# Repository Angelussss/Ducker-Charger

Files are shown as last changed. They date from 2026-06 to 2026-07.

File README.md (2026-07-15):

<div align="center">

# ⚡ Ducker-Charger

**A fully custom, open-source smart power bank, designed from scratch.**

*4S3P Li-Ion pack · bidirectional USB-PD · bench-supply output · TFT telemetry UI*






<table>
  <tr>
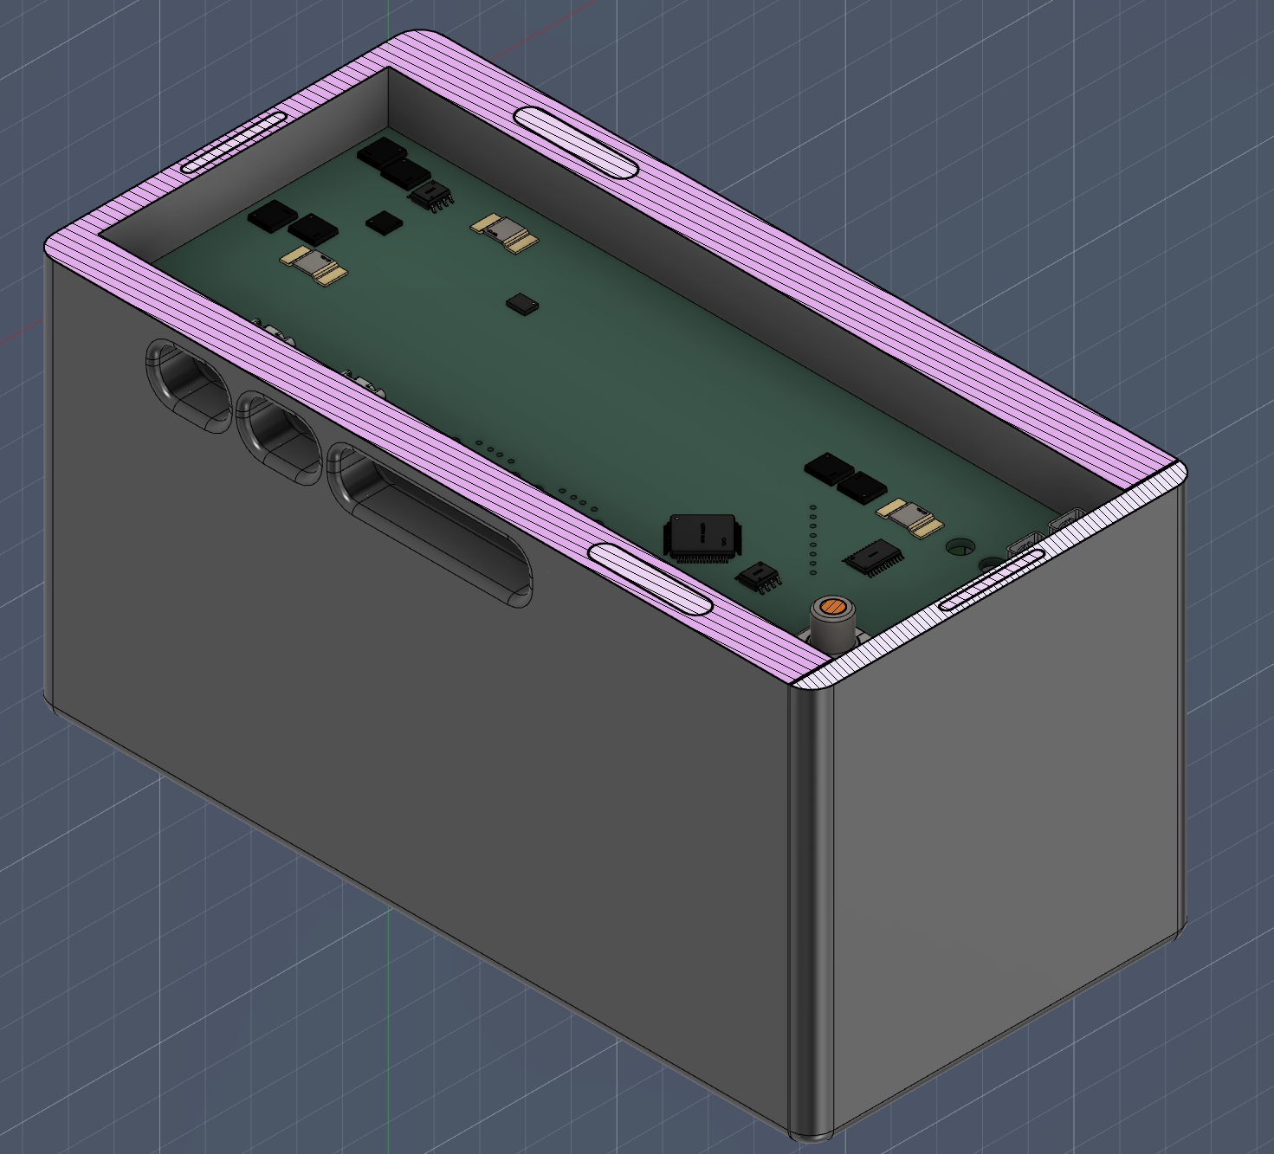
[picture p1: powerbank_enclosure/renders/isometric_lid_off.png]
Enclosure render
    <td align="center"></td>
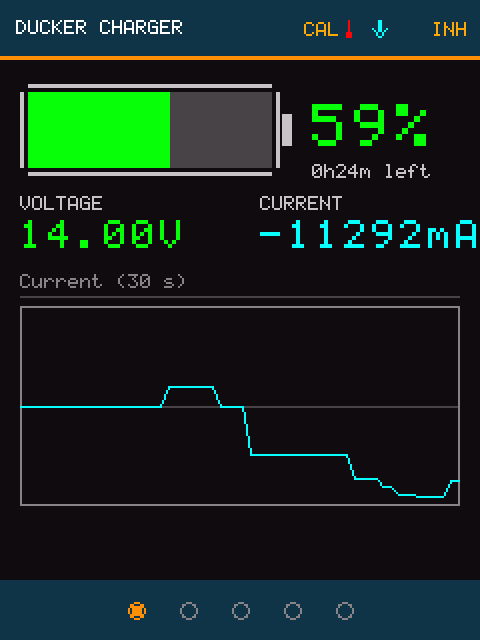
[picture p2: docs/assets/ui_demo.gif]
UI demo
    <td align="center"></td>
  </tr>
  <tr>
    <td align="center"><em>Enclosure (prototype 3, lid off)</em></td>
    <td align="center"><em>Live telemetry UI</em></td>
  </tr>
</table>

</div>

> [!WARNING]
> **Work in progress: the design is not yet validated.** This project involves
> Li-Ion batteries, which can overheat, catch fire, or explode if mishandled.
> Take any information here at your own risk and read the safety note below.

## 🌟 Highlights

* **115 Wh**: 12× 18650 cells (Sony Murata VTC5, 4S3P), 14.4 V nominal / 16.8 V max
* **2× USB-C PD**: primary port is bidirectional (charges the pack *and* powers loads)
* **2× USB-A**: fixed 5 V, individually switchable, current-monitored
* **Lab output**: banana-jack rail that behaves like a bench power supply
* **Hardware-autonomous BMS**: BQ77915 protection works even if all firmware fails
* **STM32F401 supervisor**: power-state FSM, charge management, TFT + rotary-encoder UI
* **On-device gauge calibration**: guided 9-step wizard on the display; a multimeter is the only tool needed (no bqStudio / EV2400)
* **Develop without hardware**: full-PCB emulator, desktop UI simulator, host-side unit tests

## ⚠️ Safety & Disclaimer

* **I assume no liability** for any damage to property, people, or components resulting from the construction or use of this project.
* Always double-check polarity before connecting the batteries.
* Do not attempt to assemble this circuit if you are not experienced in handling lithium batteries.

## 🛠️ Requirements

**Hardware**
* Assembled mainboard + Sensing-Board (`PCB/`)
* 12× 18650 Li-Ion cells, 4S3P (e.g. Sony/Murata VTC5)
* ST-Link V2 (or compatible SWD probe) to flash the STM32F401RBT6
* A USB-PD charger for the primary port, plus USB-C/USB-A cables to exercise the outputs

**Software**
* `arm-none-eabi-gcc`: the firmware builds via the CubeMX-generated `Makefile` in `firmware/cubeMX/`, no IDE required
* `st-flash` (`stlink-tools`) or STM32CubeProgrammer, to flash over SWD
* `gcc` + `SDL2`: only needed for `firmware/emulator/` and `firmware/interface-tester/` (no hardware required to run these)
* Optional: STM32CubeIDE / STM32CubeMX, only to regenerate peripheral init code from `cubeMX.ioc`

## 🧩 Architecture

Distributed design: cell safety, power conversion, PD negotiation and gauging
each live in a dedicated IC; the STM32 supervises, aggregates telemetry and
drives the UI. Block diagram in [`PCB/README.md`](PCB/README.md).

<details>
<summary><strong>Full IC breakdown (10 subsystems)</strong></summary>
<br>

| Subsystem | Part | Role |
|---|---|---|
| Safety / Protection | TI **BQ77915** + N-ch MOSFETs | Autonomous, software-independent cell OV/UV/SC/OC cutoff (4S, always-on) |
| Charger | TI **BQ25713** | Buck-boost NVDC battery charger (driven by the TPS25750 on a private I²C bus) |
| Main USB-C PD | TI **TPS25750** | Primary PD port controller; patch bundle streamed by the MCU at every boot |
| Aux USB-C PD | Infineon **CYPD3175** (CCG3PA) | Secondary PD port negotiation (replaced the EOL STUSB4710) |
| Aux programmable rail | ST **STPD01** | I²C-programmable supply for the secondary USB-C / lab output |
| Fuel gauge | TI **BQ34Z100-R2** | Impedance Track™ State-of-Charge / Time-to-Empty |
| Telemetry | TI **INA3221** | 3-channel voltage/current monitoring |
| Step-down | TI **TPS54302 / TPS54202** | Auxiliary rails |
| ESD / I²C isolation | **USBLC6**, **ISO1540** | Port ESD protection, isolated I²C to the battery-referenced gauge |
| Host | **STM32F401RBT6** | I²C master, power-state FSM, thermal manager, HMI / supervisor |

</details>

## 📂 Repository

| Path | Contents |
| --- | --- |
| [`PCB/`](PCB/README.md) | KiCad projects: main board + cell sensing board |
| [`firmware/`](firmware/) | STM32 firmware, PD controller configs, emulator, UI simulator, tests |
| [`docs/`](docs/README.md) | Documentation, start here |
| [`powerbank_enclosure/`](powerbank_enclosure/) | 3D-printable enclosure (F3D, STEP, STL, renders) |

<details>
<summary><strong>Full tree</strong></summary>

```text
Ducker-Charger/
├── PCB/
│   ├── Ducker-Charger/         # Main charger board (schematics, layout, datasheets)
│   └── Sensing-Board/          # Cell sensing board
├── firmware/
│   ├── cubeMX/                 # STM32F401 firmware (FSM, charge mgmt, UI, drivers)
│   ├── TPS25750/               # Primary PD controller config (JSON project + .bin)
│   ├── CYPD3175/               # Secondary PD controller firmware (hex, patches, LED driver)
│   ├── emulator/               # Full-PCB emulator: real firmware vs IC models (SDL)
│   ├── interface-tester/       # Desktop UI simulator (SDL)
│   └── tests/                  # Host-side unit tests (FSM, charge, HPI, math)
├── powerbank_enclosure/        # 3D-printable enclosure (F3D, STEP, STL, renders)
└── docs/
    ├── hardware/               # Power architecture, pin map / BSP reference
    ├── firmware/               # Architecture, FSM, charge mgmt, boot, UI
    └── assets/                 # UI demo gif
```

</details>

## 📖 Documentation

Start from **[`docs/README.md`](docs/README.md)**: full system overview and a
walkthrough of how the firmware works, with links to:

* [Hardware architecture](docs/hardware/Hardware_Architecture.md) · [pin-level BSP reference](docs/hardware/BSP_reference.md)
* [Firmware architecture](docs/firmware/Firmware_Architecture.md) · [power-state FSM](docs/firmware/FSM.md) · [charge management](docs/firmware/Charge_Management.md)
* [Boot & IC provisioning](docs/firmware/Boot_and_Provisioning.md) · [gauge calibration wizard](docs/firmware/Gauge_Calibration.md) · [UI / display reference](docs/firmware/UI_and_Display.md)
* [KiCad projects & block diagram](PCB/README.md)

## 🎮 User Guide

Boots to **MAIN** (battery %, voltage/current, live current graph). Rotate the
encoder to cycle **MAIN → DETAILS → GRAPH → PORTS → STATS**; press to open
**SETTINGS** (per-port toggles, Lab output voltage/current, USB-C2 output
ceiling, lock-all, brightness/auto-sleep, gauge calibration wizard, shutdown).
A long press (or SETTINGS → Shutdown) puts the device into deep sleep; a
short press wakes it back up if a charger is attached. Fault conditions open a
dedicated FAULT screen automatically, naming the cause.

Full screen-by-screen reference: [`docs/firmware/UI_and_Display.md`](docs/firmware/UI_and_Display.md).

## 🎥 Presentation & Demo

* 📊 Slides: [Google Slides](https://docs.google.com/presentation/d/1OwDXiBUUQ08QPd7Jknc45msrt9zxNyJMcGTFnEZxmk4/edit?usp=sharing)
* 🎬 YouTube walkthrough: [youtu.be/msm0JCK7GhI](https://youtu.be/msm0JCK7GhI)

## 👥 Team & Contributions

The project is split by layer, one owner per layer end-to-end (design, implementation, docs, tests):

| Member | Layer owned |
|---|---|
| Angelo Perotti | Hardware (PCB/KiCad), CubeMX project bring-up, boot & IC provisioning |
| Francesco Brunelli | Charge management: sensors, actuators, fault detection |
| Michelangelo Calia | Power-state FSM & fault handling |
| Maya | Display/UI stack: driver, widgets, screens, navigation |

## 🤝 Contributing

Issues, suggestions, and pull requests are momentarily suspended, as this is a university course project.

## 📜 License

Released under the [Creative Commons Attribution-NonCommercial 4.0 Internationalç
License (CC BY-NC 4.0)](LICENSE). © 2026 Angelo Perotti.

You are free to use, modify, and build upon this work for **non-commercial**
purposes, as long as you **credit the author**. See [NOTICE](NOTICE) for
attribution details.

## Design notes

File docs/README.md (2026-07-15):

# Ducker-Charger: Project Documentation

Entry point of the Ducker-Charger documentation: what the project is, how the
hardware is organized, how the firmware works, and which tools exist to develop
and test it. Every section links to the detailed document that covers it.

## Documentation map

```text
docs/
├── README.md                        # ← you are here: overview + code walkthrough
├── hardware/
│   ├── Hardware_Architecture.md     # power architecture, rails, subsystem analysis
│   └── BSP_reference.md             # pin map, ADC channels, I2C buses, GPIO tables
├── firmware/
│   ├── Firmware_Architecture.md     # module layers, main loop, telemetry/encoder/display/UI
│   ├── FSM.md                       # power-state machine: events, states, transition matrix
│   ├── Charge_Management.md         # charge.c: sensors, register maps, port logic
│   ├── Boot_and_Provisioning.md     # every-boot IC init + one-time gauge provisioning
│   ├── Gauge_Calibration.md         # on-device fuel-gauge calibration wizard
│   └── UI_and_Display.md            # screens, widgets, per-screen behaviour
└── assets/
    └── ui_demo.gif                  # UI demo capture
```

Related documentation outside `docs/`:

| Location | Content |
| --- | --- |
| [`PCB/README.md`](../PCB/README.md) | KiCad projects, schematic sheets, system block diagram |
| [`PCB/Ducker-Charger/docs/`](../PCB/Ducker-Charger/docs/) | IC datasheets and technical reference manuals |
| [`firmware/CYPD3175/README.md`](../firmware/CYPD3175/README.md) | Secondary-port PD controller firmware (build, flash, LED driver) |
| [`firmware/emulator/README.md`](../firmware/emulator/README.md) | Full-PCB emulator (firmware vs datasheet-level IC models) |
| [`firmware/interface-tester/README.md`](../firmware/interface-tester/README.md) | Desktop UI simulator (SDL) |

---

## 1. What the Ducker-Charger is

A custom, open-source smart power bank built around a 4S3P pack of twelve 18650
cells (Sony Murata VTC5, 14.4 V nominal / 16.8 V max / ~115 Wh). It exposes:

- **USB-C1 (primary)**: bidirectional USB-PD: charges the pack *and* powers loads (OTG).
- **USB-C2 (secondary)**: source-only USB-PD output, with a user-settable output ceiling.
- **2× USB-A**: fixed 5 V outputs, individually switchable.
- **Lab output**: banana-jack pins driven like a bench supply (shares the STPD01 rail with USB-C2, interlocked).

HMI: ILI9341 TFT (SPI) + rotary encoder with push-button.

Design philosophy: **distributed architecture**. Cell safety, power conversion,
PD negotiation and gauging each live in a dedicated IC; the STM32 supervises,
aggregates telemetry and drives the UI. Battery protection works even if every
line of firmware fails.

## 2. Hardware in one page

Full analysis: [`hardware/Hardware_Architecture.md`](hardware/Hardware_Architecture.md).
Pin-level reference: [`hardware/BSP_reference.md`](hardware/BSP_reference.md).

**NVDC topology**: the system load hangs on `VSYS`, regulated by the buck-boost
charger from either VBUS or the battery, the device is "instant-on" from USB-C
even with a dead pack.

| Subsystem | IC | Role |
| --- | --- | --- |
| Cell protection | TI **BQ77915** | Autonomous hardware OV/UV/OC/SC cutoff + passive balancing (4S, always-on). No firmware involved. |
| Charger | TI **BQ25713** | 4-switch buck-boost NVDC charger. On the TPS25750's **private** I2C bus, the MCU cannot reach it; it only sees the analog IADPT/IBAT/PSYS pins and CHRG_OK / EN_OTG GPIOs. |
| Primary PD (USB-C1) | TI **TPS25750** | PD controller; ROM-based, receives its 32 KB patch bundle from the STM32 at every boot. |
| Secondary PD (USB-C2) | Infineon **CYPD3175** (CCG3PA) | Autonomous PD negotiation, monitored by the MCU over HPI. Replaced the EOL STUSB4710. Own firmware, flashed independently. |
| Aux programmable rail | ST **STPD01** | Generates the voltage negotiated on USB-C2 / set for the lab output. |
| Fuel gauge | TI **BQ34Z100-R2** | Impedance Track SoC / time-to-empty. Battery-referenced, behind an **ISO1540** I2C isolator. |
| Telemetry | TI **INA3221** | Shunt monitor for USB-A1/A2 (CH3 grounded). |
| Aux rails | TI **TPS54302 / TPS54202** | Step-downs for logic and 5 V rails. |
| Host | **STM32F401RBT6** | I2C master, ADC telemetry, FSM, HMI, supervisor. |

**Buses:**

| Bus | Pins | Devices (7-bit addr) |
| --- | --- | --- |
| I2C3 "PD bus" | PA8 / PC9 | TPS25750 (0x20, length-prefixed host interface) |
| I2C1 "system bus" | PB6 / PB7 | CYPD3175 (0x08, HPI) · STPD01 (0x05) · INA3221 (0x40) · BQ34Z100 (0x55, isolated) |
| ADC1 | 8 channels | 5× NTC + IADPT / IBAT / PSYS from the charger |
| SPI1 | PA5 / PB5 | ILI9341 display (write-only) |
| TIM3 | PC6 / PC7 | Quadrature encoder (button on PC0 / EXTI0) |

**Grounds:** system `GND` and battery `-BATT` join only through the protection
FETs and the sense resistor; when protection trips, `-BATT` floats, hence the
ISO1540 isolator in front of the gauge.

## 3. Firmware: how the code works

Full detail: [`firmware/Firmware_Architecture.md`](firmware/Firmware_Architecture.md).

### 3.1 Layered structure (`firmware/cubeMX/Core/`)

```text
UI          ui/ui_state.c · ui/screens.c · ui/widgets.c
App         app/telemetry.c · app/encoder.c · app/initialization.c · app/provisioning.c · app/calibration.c
System      system/fsm.c · system/charge.c · system/event.c · system/tps25750_io.c
Display     display/ili9341.c · display/gfx.c
HAL         CubeMX-generated (SPI1 · I2C1 · I2C3 · TIM3 · ADC1 · GPIO)
```

Strictly one-directional: lower layers never know about upper ones. The UI reads
charge-layer getters read-only; only the FSM drives actuators; only `charge.c`
touches sensors and pushes events.

### 3.2 Boot (`main.c` + `app/initialization.c` + `app/provisioning.c`)

Doc: [`firmware/Boot_and_Provisioning.md`](firmware/Boot_and_Provisioning.md).

1. HAL + clock (HSE/PLL, 84 MHz) and `MX_*_Init()` peripherals.
2. **`System_Initialization()`**: every-boot bring-up of ICs with volatile config:
   - **TPS25750**: streams the 32 KB patch bundle (`app/tps25750_bundle.c`,
     generated from `firmware/TPS25750/*.bin`) over I2C3, verifies `PTCH → APP`
     transition. Skipped on warm reboot. No bundle → no PD, no charging.
   - **INA3221** config (CH1-2, averaging) and **STPD01** safe defaults
     (5 V / 3 A, output **off**).
   - 50 ms bounded timeouts, one retry per step; failures degrade the boot
     (`Init_GetReport()` feeds the boot screen) but never block it.
3. **Gauge provisioning**: one-time, marker-guarded write of pack parameters
   into the BQ34Z100 data flash; runs only on a verified device, at rest.
4. `Encoder_Init` · `Telemetry_Init` · `ILI9341_Init` · `UI_Init` · charge-layer
   `init()` · `PB_FSM_Init()` → IDLE.

### 3.3 Main loop (cooperative, no RTOS)

Each `while(1)` iteration: refresh port-status pins (`readNCS()`), pop one event
from the ring buffer into `PB_FSM_FireEvent()`, track encoder activity and the
deep-sleep button hold, `PB_FSM_Update()` (onExit/onEnter/onRun), `Telemetry_Poll()`
(rate-limited to 500 ms; keeps running in SLEEP so energy/uptime/histories don't
stop), and `UI_Tick()` (250 ms refresh) unless the FSM has the backlight off.
Sensor polling lives in each state's `onRun`, so what gets polled follows the
power state automatically.

### 3.4 Power-state FSM (`system/fsm.c`)

Doc: [`firmware/FSM.md`](firmware/FSM.md). Hybrid **vtable + transition matrix**:
behaviour per state (`onEnter/onRun/onExit`), transitions in a `[state][event]`
lookup. States: `DEEP_SLEEP`, `SLEEP`, `IDLE`, `SAFETY_LOCK`, `LOW_V`,
`EMERGENCY`, `CHARGING`, `MANUAL` (lab mode), `ERROR`. Events come from the
charge layer (charger plug/unplug, SoC thresholds 15 %/10 %, under-voltage,
overtemperature, critical faults) and from the UI (buttons, inactivity, lock,
lab mode). Protection states cut outputs in `onEnter`; `DEEP_SLEEP` uses STM32
STOP mode with the encoder button as sole wake source.

### 3.5 Charge management (`system/charge.c`)

Doc: [`firmware/Charge_Management.md`](firmware/Charge_Management.md). The only
module that touches sensors/actuators:

- **ADC**: NTC → °C (Beta equation), IADPT → mA, PSYS → W.
- **I2C**: gauge registers/flags, INA3221 currents + critical alerts, STPD01 status.
- **Primary port**: on `PD_IRQ`, decode TPS25750 `INT_EVENT1` (plug, power status,
  new contract as sink/provider), parse Fixed-Voltage PDO/RDO, gate **OTG**
  (EN_OTG raised only in IDLE/SLEEP; the pin is an independent kill switch on C1 sourcing).
- **Secondary port**: on `C2_RDY`, read the CYPD3175 HPI event (contract complete,
  disconnect, OVP/OCP/OTP, hard reset), then program the STPD01 through
  `secondaryUSBC_ApplyOutput()`, which clamps the negotiated contract to the
  user-set ceiling, verifies no post-setup fault, and only then enables the port.
- Pushes all FSM events; exposes getters for telemetry/UI.

### 3.6 Telemetry, display, UI

Docs: [`firmware/Firmware_Architecture.md`](firmware/Firmware_Architecture.md),
[`firmware/UI_and_Display.md`](firmware/UI_and_Display.md).
`app/telemetry.c` reshapes charge-layer getters into UI structs (battery snapshot,
per-port V/I with 60-sample histories, lifetime/session stats), no I2C of its own.
Display stack: `ili9341.c` (SPI, RGB565, 240×320) + `gfx.c` (text/primitives).
UI: screen carousel MAIN ↔ DETAIL ↔ GRAPH ↔ PORTS ↔ STATS, SETTINGS overlay
(long-press/double-click) with OUTPUT / DISPLAY / CALIBRATION / TEST sub-pages, CONFIRM/WARNING
modals, FAULT takeover, SLEEP page. Two-phase draw (full `Draw` on entry, partial
`Update` at 4 fps) eliminates flicker.

### 3.7 Companion firmware (not on the STM32)

- **TPS25750** (`firmware/TPS25750/`): TI web-GUI config project + generated
  `.bin` → embedded as `tps25750_bundle.c`, streamed at every boot (volatile).
- **CYPD3175** (`firmware/CYPD3175/`): built with Infineon CCGx Power SDK /
  PSoC Creator; flashed once over SWD or CC bootloader. Repo keeps the built hex,
  a status-LED driver, SDK patches and the PD config (PDOs 5/9/12/15/20 V @ 3 A).
- **BQ25713**: no firmware, configured at runtime by the TPS25750.

## 4. Development tooling (host-side, no hardware needed)

| Tool | What it does |
| --- | --- |
| [`firmware/emulator/`](../firmware/emulator/README.md) | Runs the **unmodified firmware** natively against register-level models of every IC (HPI, TPS patch flow, gauge data flash, battery physics with OCV/IR/thermal). SDL window renders the panel; headless scripted mode for regression runs. Firmware bugs are supposed to surface here. |
| [`firmware/interface-tester/`](../firmware/interface-tester/README.md) | UI-only simulator: real UI sources on a fake framebuffer + fake telemetry from `sim_config.ini`. Fastest way to iterate on screens. |
| `firmware/tests/` | Host-side unit tests: `make` runs `test_event`, `test_fsm`, `test_charge`, `test_cypd3175`, `test_hpi_schematic`, `test_math` against HAL stubs and IC models. |

## 5. Build & flash

```sh
cd firmware/cubeMX && make          # arm-none-eabi → build/cubeMX.elf/.hex/.bin
cd firmware/tests   && make         # host unit tests (gcc)
cd firmware/emulator && ./build.sh && ./run.sh          # full-board emulator (SDL2)
cd firmware/interface-tester && ./build.sh && ./run.sh  # UI simulator (SDL2)
```

STM32 flashes over SWD (ST-Link). Per-IC programming paths are mapped in
[`firmware/Boot_and_Provisioning.md`](firmware/Boot_and_Provisioning.md).
**Caveat:** CubeMX regeneration rewrites the Makefile, re-check the application
entries in `C_SOURCES` afterwards.

## 6. Mechanical

`powerbank_enclosure/` holds the 3D-printable enclosure (prototype 3): Fusion 360
source (`.f3d`), STEP, STLs (body, upper lid, short-side lid) and renders.

## 7. Status & open points

- Work in progress; hardware not yet validated, see the root [README](../README.md) disclaimer.
- Open `CHECK:` items (TPS burst chunking/address, gauge data-flash offsets,
  design capacity vs final pack, CYPD3175 LED pin) tracked in
  [`firmware/Boot_and_Provisioning.md`](firmware/Boot_and_Provisioning.md#open-verification-points).
- Fuel-gauge calibration is done **on-device**: SETTINGS → Calibration, a
  nine-step multimeter-assisted wizard (electrical cal, pack config, IT
  enable, learning-cycle monitor), see
  [`firmware/Gauge_Calibration.md`](firmware/Gauge_Calibration.md). Until it
  is run on the real pack, SoC readings are indicative and the UI shows a
  NOT CALIBRATED warning at every wake. ChemID selection (optional accuracy
  refinement) still needs one bqStudio session.

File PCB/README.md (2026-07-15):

# PCB: KiCad Projects

Two KiCad projects make up the Ducker-Charger hardware:

| Project | Contents |
| --- | --- |
| `Ducker-Charger/` | Main charger board: schematics, PCB layout, production files |
| `Sensing-Board/` | Cell sensing board (tap connections from the 4S pack to the BMS) |

## Main board schematic structure

| Sheet | File | Contents |
| --- | --- | --- |
| Root | `Ducker-Charger.kicad_sch` | Top level, sheet interconnections |
| High power | `high_pow.kicad_sch` | TPS25750 (primary USB-C PD), BQ25713 buck-boost charger, VBUS power path |
| Low power | `low_pow.kicad_sch` | CYPD3175 (secondary USB-C PD), STPD01 programmable rail, USB-A load switches, INA3221 sensing, lab-output switching |
| Logic | `Logic.kicad_sch` | STM32F401RBT6, display/encoder interface, logic supply |
| BMS | `BMS.kicad_sch` | BQ77915 protection, BQ34Z100-R2 fuel gauge, ISO1540 I2C isolator, protection FETs |

> The secondary PD controller is the Infineon **CYPD3175**: it replaced the
> ST **STUSB4710** (EOL).

Component datasheets and technical reference manuals used during the design are
collected in [`Ducker-Charger/docs/`](Ducker-Charger/docs/).

## System block diagram

```mermaid
flowchart TB
    subgraph BMS["BMS (always-on hardware safety)"]
        PACK["4S3P Sony VTC5<br/>14.4V nom / 16.8V max"]
        BQ77915["BQ77915 protector<br/>+ N-ch FETs (low-side)"]
        GAUGE["BQ34Z100-R2 fuel gauge<br/>(battery-referenced)"]
        PACK --> BQ77915
        PACK -.->|sense| GAUGE
    end

    subgraph HP["High-power stage"]
        TPS["TPS25750<br/>primary USB-C PD"]
        BQ25713["BQ25713<br/>buck-boost NVDC charger"]
        USBC1(("USB-C1<br/>bidirectional PD"))
        USBC1 <--> TPS
        TPS <-->|private I2C_EX| BQ25713
    end

    subgraph LP["Low-power / aux stage"]
        CYPD["CYPD3175<br/>secondary USB-C PD"]
        STPD01["STPD01<br/>programmable rail"]
        USBC2(("USB-C2<br/>source-only"))
        USBA(("2x USB-A<br/>5V"))
        LAB(("Lab output"))
        INA["INA3221<br/>current monitor"]
        CYPD <--> USBC2
        STPD01 --> USBC2
        STPD01 --> LAB
        INA --- USBA
    end

    subgraph LOGIC["Logic"]
        MCU["STM32F401RBT6"]
        DISP["ILI9341 TFT (SPI1)"]
        ENC["Rotary encoder (TIM3)"]
        MCU --> DISP
        ENC --> MCU
    end

    BQ77915 -->|+BATT| BQ25713
    BQ25713 -->|VSYS| LP
    BQ25713 -->|VSYS| LOGIC

    MCU <-->|"I2C3 (PD bus)"| TPS
    MCU <-->|"I2C1 (system bus, HPI)"| CYPD
    MCU <-->|I2C1| STPD01
    MCU <-->|I2C1| INA
    MCU <-->|"I2C1 via ISO1540"| GAUGE
```

Bus-level detail (pins, addresses):
[`docs/hardware/BSP_reference.md`](../docs/hardware/BSP_reference.md).

## Production

`*/production/` holds the fabrication outputs (gerber zip + IPC netlist)
generated with the JLCPCB fabrication toolkit. Regenerate after any layout
change; do not hand-edit.

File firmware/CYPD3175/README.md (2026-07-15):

# Ducker-Charger: CYPD3175 (EZ-PD CCG3PA) firmware customisation

Custom bits to graft onto the **EZ-PD CCGx Power SDK** reference firmware
for the USB-C2 PD controller (CYPD3175-24LQXQ, the STUSB4710
replacement). Reviewed here first; moves into the git repo only after
approval.

## Contents

```
src/ducker_led.c|h      status-LED driver (GPIO + SDK software timer)
src/INTEGRATION.md      where to hook it inside the reference project
config/c2_pd_config.md  config-table values (PDOs, protections) for the
                        EZ-PD Configuration Utility: no code involved
```

## Status

- **BUILT AND LINKED** (2026-07-04) against CCGx Power SDK 3.5 with
  PSoC Creator 4.4 in the win11 VM, zero warnings under `-Werror`.
  Flash: 89.6% (noboot) vs 88.7% baseline, the LED costs ~600 B.
  Built hex in `build/`; the patched reference files (app.c, main.c,
  both .cyprj with the ducker_led source entries) are mirrored in
  `patched-reference/` and live in the VM under `C:\ducker\fw`.
- Two of the three original CHECKs are resolved against SDK 3.5
  (timer ID = USER_TIMERS_START_ID+4, GPIO signatures verified).
- **One CHECK left**: the LED pin is a placeholder
  (`GPIO_PORT_1_PIN_4`) until the CCG3PA section of the schematic
  exists.
- The big open item is the power stage: `pa_direct_fb` expects the
  CCG3PA to drive the regulator via direct feedback. Copying the CCG3PA
  reference topology in the new PCB keeps firmware work at
  "config + LED"; keeping the STPD01 I2C chain means real psource-layer
  work.

## Toolchain

| Piece | Purpose |
|---|---|
| EZ-PD CCGx Power SDK | stack + reference projects (`CYPD3175-24LQXQ_pa_direct_fb`, `CYPD3171-24LQXQ_pb`) |
| PSoC Creator 4.x (Windows) | build |
| EZ-PD Configuration Utility | config table edit + bootloader flashing |
| MiniProg3/4 (SWD) | first flash on a blank chip |

Getting started: Infineon AN218179 "Getting Started with EZ-PD CCG3PA".

## LED behaviour (as implemented)

| State | Pattern |
|---|---|
| No cable | off |
| Attached / negotiating | slow blink (2 Hz) |
| Contract established | solid on |
| OVP/OCP fault | fast blink (8 Hz) |

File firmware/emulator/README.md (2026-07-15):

# emulator: full-PCB emulator for the Ducker-Charger firmware

Runs the **unmodified firmware** (`main.c`, FSM, charge management,
boot-camp init, gauge provisioning, telemetry, encoder, ILI9341 driver,
UI) natively on the PC against register-level models of the board's ICs.

Where `interface-tester/` fakes the telemetry and replaces the display
API, this emulator models **the PCB**: the ICs behave as their
datasheets/TRMs say, not as the firmware expects. Firmware bugs are
supposed to surface here; that is the point.

```
firmware thread (real, unmodified code)          emulator
────────────────────────────────────────  ──────────────────────────
main.c / fsm.c / charge.c / event.c        fake HAL (src/hal_impl.c)
initialization.c / provisioning.c            ├── I2C1 ─ BQ34Z100 (gauge, data flash, flags)
telemetry.c / encoder.c                      │         ├ CYPD3175 (HPI, event queue, INT PC3)
ili9341.c / gfx.c / ui/*                     │         ├ STPD01   (VOUT/ILIM/INT_STAT, EN PC11)
                                             │         └ INA3221  (shunts A1/A2, MSB-first)
                                             ├── I2C3 ─ TPS25750 (len-prefixed regs, PTCH→APP
                                             │          patch flow, burst addr 0x22, IRQ PB14)
                                             ├── ADC1 ─ NTC dividers + current/power senses
                                             ├── SPI1 ─ ILI9341/ST7789 panel (CASET/RASET/
                                             │          RAMWR decode → SDL window)
                                             └── GPIO ─ pin table, EXTI0, CHRG_OK, EN pins
                                           board.c: 4S3P battery physics (OCV curve, SoC
                                           integration, IR drop, thermal), power flow
```

## Quick start

```sh
# needs gcc + SDL2  (Arch: sudo pacman -S sdl2)
./build.sh
./run.sh                     # SDL window, 240x320 like the panel
./run.sh --headless 8000 --at 2500:c --at 5000:v    # scripted, no window
```

Headless mode dumps `screen.ppm` (as the eye would see it: backlight,
display-on and inversion applied) and `gram.ppm` (raw GRAM) plus a
status report on exit.

## Keys / scripted events

| Key | Action |
|-----|---|
| arrows / wheel | encoder rotation |
| SPACE | encoder button (hold = long press) |
| `c` | plug / unplug the C1 charger (TPS25750 + CHRG_OK) |
| `d` | attach / detach a sink device on C1 (powerbank sources, OTG) |
| `v` | attach / detach a PD sink on C2 (CYPD3175) |
| `1` / `2` | attach / detach a load on USB-A1 / A2 |
| `l` | attach / detach a resistive load on the lab output (`lab_load_ohm`) |
| `o` | INA3221 critical alert on A1 |
| `t` `h` `u` `f` | gauge faults: overtemp / BATHI / BATLOW / CF |
| `x` `z` `r` | CYPD3175 OVP / OCP / hard reset |
| `g` | STPD01 short-circuit fault |
| `k` | toggle CHRG_OK line |
| `w` | wake from STOP mode (deep sleep) |
| `q` | shutdown: push the long-press event straight into DEEP_SLEEP (only takes effect from IDLE/SLEEP, same as a real button hold) |
| `i` | print full status (board + firmware getters + pins) |
| `s` | dump screen.ppm / gram.ppm |
| ESC | quit |

`emu_config.ini` sets the initial battery state, PD contracts, loads and
IC behavior. `time_scale` accelerates only the battery physics.

## Recording gifs

`--rec <ms>` dumps a numbered frame to `frames/` every `<ms>` in both
the SDL and the headless loop. `./record.sh [out.gif]` wraps it:
records an interactive SDL session until ESC, trims the display-off
boot frames, inverts the colors back to the real-panel palette and
assembles the gif with ffmpeg (`REC_MS=50` for 20 fps).

## Gauge calibration model

The BQ34Z100 model exercises the on-device calibration wizard end to
end: the DF calibration block (subclass 104) is live, reported V/I/T
are distorted by the stored divider/gain/offset, seeded with deliberate
errors at attach, the internal offset routines run with realistic
CCA/BCA timing, and IT_ENABLE sets QEN + Update Status 0x04. A correct
wizard run visibly converges the readings.

Every log line carries the firmware FSM state as a column, and every
event fired into the FSM is traced as a `[FSM ]` line with the
transition it caused (`CHARGER_CONNECTED: IDLE -> CHARGING`), including
events that were ignored or refused by a guard, the log alone tells the
whole story of a scenario. The hook is `PB_FSM_TraceEvent()`, a weak
no-op in fsm.c that the emulator overrides; the target build pays
nothing for it.

## Fidelity notes / limits
- STPD01 `DIGITAL_ENABLE` (0x06) is stored but does not gate the output
  in the model (power-on follows the EN pin only), verify on hardware
  before trusting either.
- Timing is wall-clock: I2C/SPI transfers are instantaneous, HAL_Delay
  sleeps for real. `time_scale` compresses battery time only.
- BQ25713 is on the TPS25750's private I2C bus on the real board and is
  not modeled beyond CHRG_OK + the charge-current profile.

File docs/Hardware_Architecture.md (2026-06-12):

# Ducker-Charger: Hardware Architecture

This document details the hardware design, power architecture, and circuit analysis of the Ducker-Charger.

## 1. Power Architecture & Domains

The system utilizes a **Narrow Voltage DC (NVDC)** architecture. This decouples the system load from the battery, allowing the device to operate immediately upon USB-C insertion even if the battery is depleted or removed ("Instant-on").

### Voltage Rails

| Rail Name | Voltage | Source | Description |
| --- | --- | --- | --- |
| **VBUS** | 5V - 20V | USB-C / Boost | Input/Output power rail negotiated by PD Controller.|
| **VSYS** | Regulated | U1 (Charger) | Main system bus. Powered by Buck-Boost from VBUS or Battery.|
| **+BATT** | 10V - 16.8V | Battery Pack | Raw battery stack voltage (4S Li-Ion typical).|
| **+3V3** | 3.3V | **IC2** (TPS54302) | Logic supply for MCU and sensors, derived from `VSYS`.|
| **5V_USB** | 5.0V | **U4, U5** | Regulated output for USB-A ports.|
---

## 2. Subsystem Analysis

### 2.1. High-Power Stage & USB-C PD

*Schematic Sheet: `/High_pow/*`

* **USB-C PD Controller (U2 - TPS25750):** Manages the Power Delivery policy and negotiation on CC lines. It controls the input VBUS MOSFETs via `PP5V` gate drive and communicates with the MCU via `I2C_PD`.

* **Buck-Boost Charger (U1 - BQ25713):** The core power converter. It utilizes a 4-switch H-Bridge topology (MOSFETs Q3, Q4, Q13, **Q5**) to regulate voltage regardless of the VBUS/Battery differential. It manages the Power Path via the `BATDRV` signal, controlling Q15 to charge or discharge the battery.

### 2.2. Battery Management System (BMS)

*Schematic Sheet: `/BMS/*`

The BMS prioritizes safety through hardware redundancy, separating protection from monitoring.

* **Primary Protection (U8 - BQ77915):** A standalone hardware protector. It monitors individual cell voltages (`VC0`-`VC4`) and drives the series protection MOSFETs (Q1, Q2) to cut off the battery in case of Over-Voltage, Under-Voltage, or Short-Circuit. It also handles passive cell balancing.

* **Fuel Gauge (IC3 - BQ34Z100-R2):** Uses a low-side sense resistor (`SRN`/`SRP`) to track State of Charge (SoC).

* **Critical Design Note:** An **ISO1540 (U9)** I2C isolator is used. The Fuel Gauge references the Battery Negative (`-BATT`), while the MCU references System Ground (`GND`). The isolator prevents ground loops and protects the logic when protection FETs are open.

### 2.3. Logic & Control

*Schematic Sheet: `/Logic/*`

* **MCU (U7 - STM32F401RBT6):** The central controller. It monitors system telemetry, drives the display, and configures the PD controller and Charger via I2C.

* **Power Supply:** The MCU regulator (**IC2 - TPS54302**) is powered by `VSYS`. Since `VSYS` is backed by `VBUS`, the logic remains active during charging.

### 2.4. Auxiliary Outputs & Sensing

*Schematic Sheet: `/Low_pow/*`

* **Lab Mode Switching:** The system can route power to banana jacks (`V_LABS`) or USB ports via back-to-back MOSFETs (Q6-Q9), controlled by `USB_C_ZENABLER` and `LAB_ZENABLER` signals.

* **Current Monitoring:** An **INA3221** (3-channel monitor) provides real-time current and voltage telemetry for the auxiliary outputs.

---

## 3. Critical Implementation Details

### Ground Separation

The design features two distinct ground domains:

1. **GND:** System Ground (Logic, Power Stage, USB-C).
2. **-BATT:** Battery Pack Negative.

*Connection:* These are connected via the **Protection MOSFETs** and the **Sense Resistor**. When the protection trips, `-BATT` floats.

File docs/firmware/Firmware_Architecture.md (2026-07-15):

# Ducker-Charger: Firmware Architecture

This document describes the software architecture, module structure, and data
flow of the Ducker-Charger firmware, targeting the STM32F401RBT6 MCU and built
on top of the STM32 HAL generated by STM32CubeMX.

---

## 1. Project Layout

```
firmware/cubeMX/
├── Core/
│   ├── Inc/
│   │   ├── app/
│   │   │   ├── encoder.h        # Rotary encoder API
│   │   │   ├── initialization.h # Boot-time IC bring-up (TPS25750 patch…)
│   │   │   ├── provisioning.h   # BQ34Z100 data-flash provisioning
│   │   │   ├── calibration.h    # On-device gauge calibration backend
│   │   │   └── telemetry.h      # UI-facing data aggregation
│   │   ├── display/
│   │   │   ├── ili9341.h        # Low-level SPI display driver
│   │   │   ├── gfx.h            # Primitive drawing (text, lines…)
│   │   │   └── logo.h           # Boot logo bitmap
│   │   ├── system/
│   │   │   ├── charge.h         # Charge management: sensors + actuators
│   │   │   ├── defines.h        # Pins, thresholds, IC addresses
│   │   │   ├── event.h          # FSM event queue (ring buffer)
│   │   │   ├── fsm.h            # Power-state FSM
│   │   │   └── tps25750_io.h    # Length-prefixed TPS25750 register I/O
│   │   └── ui/
│   │       ├── ui_state.h       # UI state machine
│   │       ├── screens.h        # Per-screen draw/update functions
│   │       └── widgets.h        # Reusable graphical components
│   └── Src/
│       ├── app/        (encoder, initialization, provisioning,
│       │                calibration, telemetry, tps25750_bundle)
│       ├── display/    (ili9341, gfx)
│       ├── system/     (charge, event, fsm, tps25750_io)
│       ├── ui/         (ui_state, screens, widgets)
│       └── main.c      # CubeMX-generated entry point + main loop
├── Drivers/            # STM32 HAL + CMSIS (CubeMX-generated)
└── cubeMX.ioc          # CubeMX project file
```

The application code lives entirely in `Core/`. CubeMX-generated peripheral
initialisation (`MX_*_Init()`) stays in its generated files; application
integration lives in `main.c`'s USER CODE sections.

---

## 2. Module Architecture

The firmware is split into independent layers that communicate in a
single direction (lower layers do not know about upper layers):

```
┌──────────────────────────────────────────────┐
│              UI Layer                        │
│   ui_state.c  ·  screens.c  ·  widgets.c    │
├──────────────────────────────────────────────┤
│           Application Layer                  │
│  telemetry.c · encoder.c · initialization.c │
│  provisioning.c                              │
├──────────────────────────────────────────────┤
│         System Layer (FSM + charge)          │
│   fsm.c · charge.c · event.c · tps25750_io  │
├──────────────────────────────────────────────┤
│            Display Layer                     │
│       ili9341.c  ·  gfx.c                   │
├──────────────────────────────────────────────┤
│         HAL / Hardware (CubeMX)              │
│  SPI1 · I2C1 · I2C3 · TIM3 · ADC1 · GPIO   │
└──────────────────────────────────────────────┘
```

### Layer responsibilities

| Layer | Module | Responsibility |
| --- | --- | --- |
| **UI** | `ui_state` | State machine: which screen is active, navigation transitions |
| **UI** | `screens` | Full draw and partial update of each screen |
| **UI** | `widgets` | Reusable graphical components (battery bar, graph, labels…) |
| **App** | `telemetry` | Reshapes charge-layer getters into UI-facing structs (`telemetry`, `port_stats[]`, `sys_stats`); no I2C of its own |
| **App** | `encoder` | Reads TIM3 counter delta and button debounce |
| **App** | `initialization` / `provisioning` | Boot-time IC bring-up (TPS25750 patch bundle, STPD01/INA3221 defaults) and one-time BQ34Z100 data-flash provisioning |
| **App** | `calibration` | On-device gauge calibration backend: ratio-method DF rewrites, internal offset routines, pack config, IT enable, learning monitor (see `Gauge_Calibration.md`) |
| **System** | `fsm` | Power-state FSM: consumes events, drives port actuators via `onEnter`/`onExit` (see `FSM.md`) |
| **System** | `charge` | All sensor reads (ADC + I2C) and all port actuation; pushes FSM events (see `Charge_Management.md`) |
| **System** | `event` | 8-slot ring buffer decoupling event producers from the FSM |
| **System** | `tps25750_io` | Length-prefixed register I/O helpers for the TPS25750 host interface |
| **Display** | `ili9341` | SPI commands/data to the panel; raw pixel operations; backlight ownership |
| **Display** | `gfx` | Text rendering, lines, rectangles built on top of `ili9341` |

---

## 3. Main Loop Integration

The firmware uses a **cooperative, polling-based** approach: there is no RTOS.
Everything is called from the `while(1)` loop in `main.c`:

```c
/* USER CODE BEGIN 2  (after MX_*_Init calls) */
Encoder_Init(&htim3);
Telemetry_Init(&hi2c1, &hi2c3);
ILI9341_Init(&hspi1);
UI_Init();                     // show boot screen
init();                        // charge layer bring-up (initialization.c)
PB_FSM_Init(&fsm);             // enters IDLE
/* USER CODE END 2 */

/* USER CODE BEGIN 3  (inside while(1)) */
readNCS();                     // refresh port-status pins
if (event_pop(&evt)) PB_FSM_FireEvent(&fsm, evt);
/* encoder-activity, deep-sleep-hold and inactivity timers */
PB_FSM_Update(&fsm);           // onExit / onEnter / onRun
Telemetry_Poll();              // rate-limited; runs even in SLEEP so
                               // uptime/energy/histories keep flowing
if (state != SLEEP && state != DEEP_SLEEP)
    UI_Tick();                 // input + redraw (skipped: backlight off)
/* USER CODE END 3 */
```

Sensor polling itself happens inside the FSM's `onRun` handlers (each
active state calls `readCS()`/`readSensors()`/`readINA()` as appropriate),
so what gets polled follows the power state automatically.

### Timing budget

| Task | Interval | Controlled by |
| --- | --- | --- |
| Telemetry reshape | 500 ms | `TELEMETRY_POLL_INTERVAL_MS` in `telemetry.h` |
| UI refresh | 250 ms (4 fps) | `UI_REFRESH_INTERVAL_MS` in `ui_state.h` |
| Encoder read | Every `UI_Tick()` call | No timer, read-on-every-tick |
| FSM inactivity → SLEEP | 2 min | `INACTIVITY_TIMEOUT_MS` in `defines.h` |
| Deep-sleep hold | 3 s | `BUTTON_DEEPSLEEP_HOLD_MS` in `defines.h` |
| Boot screen timeout | 1 500 ms | `BOOT_SCREEN_DURATION_MS` in `ui_state.c` |

---

## 4. Application Layer

### 4.1 Telemetry Module (`telemetry.h / telemetry.c`)

The telemetry module makes **no I2C calls of its own**: the fuel gauge,
INA3221 and PD contracts are already polled every FSM tick by the charge
layer. `do_poll()` reads that layer's getters and reshapes the data into
UI-facing structs, `telemetry` (battery snapshot), `port_stats[5]`
(per-port V/I + 60-sample history ring for the PORTS screen), `sys_stats`
(lifetime + session counters, including a discharge-energy integral with a
sub-mWh remainder accumulator), and `tte_min`/`ttf_min`.

**Global data structure:**

```c
extern SystemTelemetry_t telemetry;
```

| Field | Type | Source | Description |
| --- | --- | --- | --- |
| `soc_percent` | `uint8_t` | BQ34Z100 reg `0x02` | State of Charge 0–100 % |
| `voltage_mV` | `uint16_t` | BQ34Z100 reg `0x08` | Pack voltage in mV |
| `current_mA` | `int16_t` | BQ34Z100 reg `0x0A` | Signed: positive = charging |
| `temp_celsius` | `int16_t` | BQ34Z100 reg `0x0C` | Converted from 0.1 K units |
| `is_full` | `uint8_t` | BQ34Z100 flags `FC` bit | 1 when battery fully charged |
| `is_charging` | `uint8_t` | BQ34Z100 flags `CHG` bit | 1 when current > 0 |
| `over_temp` | `uint8_t` | BQ34Z100 flags `OT` bit | 1 on over-temperature fault |
| `vbus_present` | `uint8_t` | TPS25750 PD contract | 1 when the primary USB-C port is plugged and sinking |
| `charge_phase` | `uint8_t` | BQ34Z100 `CHG` flag / current sign | 0=idle, 1=charging. The BQ25713 register that would distinguish pre-charge/fast/taper (`CHGSTATUS1`) sits on a private I2C bus this MCU can't reach, see `Charge_Management.md`. |
| `power_mW` | `int32_t` | Computed | `voltage_mV × current_mA / 1000` |
| `current_history[]` | `int16_t[60]` | Ring buffer | Last 60 current samples (30 s) |
| `sensor_ok` | `uint8_t` | Internal | 1 if last poll succeeded on all chips |

**API:**

```c
void    Telemetry_Init(I2C_HandleTypeDef *hi2c1_ptr,
                       I2C_HandleTypeDef *hi2c3_ptr);
uint8_t Telemetry_Poll(void);   // respects TELEMETRY_POLL_INTERVAL_MS
void    Telemetry_ForcePoll(void);
```

**I2C bus assignment** (all access happens in the charge layer):

| Bus | HAL handle | Devices | Address (7-bit) |
| --- | --- | --- | --- |
| I2C1 | `hi2c1` | CYPD3175 · STPD01 · INA3221 · BQ34Z100 (via ISO1540) | `0x08` · `0x05` · `0x40` · `0x55` |
| I2C3 | `hi2c3` | TPS25750 (length-prefixed host interface, `tps25750_io.c`) | `0x20` |

> **Note:** the BQ25713 charger is *not* on any MCU bus, it sits on the
> TPS25750's private I2C_EX bus. Its only MCU-visible outputs are the
> analog telemetry pins (IADPT/IBAT/PSYS on ADC1) and CHRG_OK/EN_OTG GPIOs.

**Temperature conversion** (from raw register to °C):
```
T[°C] = (raw / 10) − 273
```
Example: `raw = 2981` → 298.1 K → **25 °C**

**Current ring buffer:** `current_history[]` is a circular buffer of 60
samples. `history_idx` points to the next free slot; `history_full` is set
to 1 after the first complete lap. At one sample per 500 ms this gives
30 seconds of current history, used by the graph screen.

---

### 4.2 Encoder Module (`encoder.h / encoder.c`)

Reads the rotary encoder (EC11 type) connected to TIM3 in hardware encoder
mode, plus the push-button on PC0.

**Hardware connections:**

| Signal | MCU pin | Notes |
| --- | --- | --- |
| Encoder A | TIM3 CH1 (PC6) | Handled automatically by TIM3 encoder mode |
| Encoder B | TIM3 CH2 (PC7) | Handled automatically by TIM3 encoder mode |
| Button | PC0 | Active-low, external pull-up on board; EXTI0 both edges + 50 ms software debounce. Also the sole DEEP_SLEEP wake source. |

**How TIM3 encoder mode works:** the timer hardware counts quadrature edges
on channels A and B without using interrupts (`TIM_ENCODERMODE_TI12`).
Reading `TIM3->CNT` gives the accumulated position; the raw delta is
divided by 2 (2 counts per detent in TI12) to obtain user-visible clicks.

**API:**

```c
void    Encoder_Init(TIM_HandleTypeDef *htim_ptr);
int8_t  Encoder_GetDelta(void);   // positive = right, negative = left
uint8_t Encoder_IsPressed(void);  // edge-triggered, consumed on read
uint8_t Encoder_IsHeld(void);     // level-based, not consumed
```

`Encoder_GetDelta()` is stateful: it returns the movement since the last
call and resets the reference counter. Calling it twice without any rotation
returns 0 on the second call.

Button debounce threshold: `ENCODER_DEBOUNCE_MS = 50 ms`.

---

## 5. Display Layer

### 5.1 ILI9341 Driver (`ili9341.h / ili9341.c`)

Low-level SPI driver. Handles the hardware reset sequence, the
command/data distinction via the DC pin, and raw pixel operations.

**SPI connections:**

| Signal | MCU pin |
| --- | --- |
| SPI1 SCK | PA5 |
| SPI1 MOSI | PB5 |
| CS | PB0 (`DISP_CS_Pin`) |
| DC | PB1 (`DISP_DC_Pin`), LOW = command, HIGH = data |
| RST | PB2 (`DISP_RST_Pin`) |
| Backlight | PB8 (`BCKL_CTRL_Pin`), via `ILI9341_Backlight()`, polarity per JP402 |

Display resolution: **240 × 320 pixels, portrait mode.**
Pixel format: **RGB565** (5 bits red, 6 bits green, 5 bits blue, 2 bytes per pixel).

**Key primitives:** `ILI9341_Init()`, `ILI9341_FillScreen()`,
`ILI9341_FillRect()`, `ILI9341_DrawPixel()`.

**Colour constants** (defined in `ili9341.h`):

| Constant | RGB565 | Usage |
| --- | --- | --- |
| `COLOR_BG` | `0x0841` | Near-black background |
| `COLOR_ACCENT` | `0x04FF` | Teal, active elements, selection |
| `COLOR_WARN` | `0xFD00` | Orange, warnings |
| `COLOR_DANGER` | `0xF800` | Red, errors, low battery |

### 5.2 GFX Layer (`gfx.h / gfx.c`)

Geometric and text primitives built on top of `ili9341`:
`GFX_DrawString()`, `GFX_DrawChar()`, `GFX_DrawHLine()`, `GFX_DrawCircle()`.
Three font sizes are available: `GFX_FontSmall`, `GFX_FontMedium`, `GFX_FontLarge`.

---

## 6. UI Layer

### 6.1 State Machine (`ui_state.h / ui_state.c`)

Manages navigation between screens. The state is stored in:

```c
extern UIState_t ui_state;
```

**Screens and navigation:**

```
          [BOOT]
            |  auto after 1 500 ms
            v
[MAIN] <--> [DETAIL] <--> [GRAPH] <--> [PORTS] <--> [STATS]   (carousel, wraps)

  SETTINGS overlay: long press (1 s) or double click from anywhere;
  its rows open the OUTPUT (Lab / USB-C2), DISPLAY, CALIBRATION
  (gauge wizard, behind a confirm modal) and TEST sub-pages.
  Modals: CONFIRM (Lock all / Shutdown), WARNING, FAULT (FSM takeover),
  SLEEP (dark screen page).
```

Encoder rotation moves through the main carousel. Short press is
screen-specific (GRAPH: cycle Y scale; SETTINGS: act on the selected row).
The full per-screen behaviour is documented in `UI_and_Display.md`.

**API:**

```c
void       UI_Init(void);
void       UI_Tick(void);                    // call in while(1)
void       UI_NavigateTo(UIScreen_t screen);
```

**`UIScreen_t` enum:** see `ui/ui_state.h`, BOOT, MAIN, DETAIL, GRAPH,
PORTS, STATS, SETTINGS, OUTPUT, DISPLAYPG, CALPG, TESTPG, CONFIRM, WARNING,
SLEEP, FAULT.

### 6.2 Screens (`screens.h / screens.c`)

Each screen exposes two functions:

- `Screen_XXX_Draw()`, draws everything (background, labels, current
  values). Called once when entering the screen.
- `Screen_XXX_Update()`, redraws **only** the dynamic parts (numbers,
  graph). Called periodically by `UI_Tick()`.

This two-phase approach eliminates flickering: the background and static
labels are never redrawn unnecessarily.

**Screen layout (240 × 320 portrait):**

```
Y=0   ┌──────────────────────────┐
      │  HEADER  (30 px)         │  title + status icons (USB-C, charging…)
Y=30  ├──────────────────────────┤
      │  CONTENT (260 px)        │  screen-specific content
Y=290 ├──────────────────────────┤
      │  FOOTER  (30 px)         │  navigation dots (● ○ ○ ○)
Y=320 └──────────────────────────┘
```

**MAIN screen layout:**

```
┌──────────────────────────┐
│  DUCKER CHARGER  [●USB-C]│  header
├──────────────────────────┤
│  [███████░░░░░] 85%      │  battery bar (Widget_BatteryBar)
│  14.75 V      +2450 mA   │  voltage + current labels
│  ~~~~~~~~~~~~~~~~~~~~~~~~│  current graph (Widget_LineGraph, 30 s)
├──────────────────────────┤
│  ●  ○  ○  ○              │  navigation dots footer
└──────────────────────────┘
```

**SETTINGS screen:** scrollable overlay of 9 rows. The currently selected
row is highlighted with `COLOR_ACCENT`.

| Row | Action | Backing signal / path |
| --- | --- | --- |
| 0 | USB-A Port 1 toggle | `USB_A1_CTRL_Pin` (PC1), row reads the live pin |
| 1 | USB-A Port 2 toggle | `USB_A2_CTRL_Pin` (PC2), row reads the live pin |
| 2 | Lab output → OUTPUT page | `C2_LAB_EN_Pin` (PA11) via FSM MANUAL state |
| 3 | USB-C Port 2 → OUTPUT page | `C2_PORT_EN_Pin` (PA12), row reads the live pin (the port auto-enables on PD negotiation) |
| 4 | Lock all (confirm modal) | `EVT_LOCK`/`EVT_UNLOCK` → FSM SAFETY_LOCK |
| 5 | DISPLAY page | brightness, auto-sleep, screen off, shutdown |
| 6 | CALIBRATION page | nine-step gauge calibration wizard (`app/calibration.c`), behind a CONFIRM modal |
| 7 | TEST page | forced warning scenarios |
| 8 | Exit | back to the screen SETTINGS was opened from |

### 6.3 Widgets (`widgets.h / widgets.c`)

Self-contained graphical components used by `screens.c`.

| Widget | Function pair | Description |
| --- | --- | --- |
| **BatteryBar** | `Widget_BatteryBar_Draw/Update` | Filled bar + percentage text. Colour: green >50 %, yellow >20 %, red ≤20 % |
| **LineGraph** | `Widget_LineGraph_Draw` | Renders a `int16_t[]` ring buffer; scales Y automatically between `val_min` and `val_max` |
| **ValueLabel** | `Widget_ValueLabel_Draw/Update` | Small header label + large numerical value |
| **StatusIcon** | `Widget_StatusIcon_Draw` | Coloured dot + text for USB-C, charging, full, temperature states |
| **MenuRow** | `Widget_MenuRow_Draw` | Single row with optional selection highlight |

---

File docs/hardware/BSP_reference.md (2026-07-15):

# Hardware Interface & Memory Map: Ducker-Charger Mainboard

**Target MCU:** STM32F401RBT6
---

## 1. Human Interface (Encoder & Button)

The user interface relies on a mechanical rotary encoder with an integrated push button.
**Hardware Note:** Signals are filtered via RC networks on the PCB. Internal pull-ups should be configured for the button if not sufficient.

| Signal Name | STM32 Pin | GPIO Config | Function |
| :--- | :--- | :--- | :--- |
| **ENC_A** | **PC6** | `AF_TIM` (Encoder Mode) | Encoder Phase A |
| **ENC_B** | **PC7** | `AF_TIM` (Encoder Mode) | Encoder Phase B |
| **ENC_BUTT** | **PC0** | `Input` (Pull-up) | Enter Button (Active Low) |

---

## 2. Analog Sensing System (ADC)

All sensors are read via **ADC1** (12-bit resolution).
**Reference (VREF+):** VDDA (+3.3V, filtered).

### 2.1 Channel Mapping
| Signal Name | STM32 Pin | ADC Channel | Description |
| :--- | :--- | :--- | :--- |
| **NTC_1** | **PA0** | IN0 | Temp Zone 1 (General/FETs) |
| **NTC_2** | **PA1** | IN1 | Temp Zone 2 |
| **NTC_3** | **PA2** | IN2 | Temp Zone 3 |
| **NTC_4** | **PA3** | IN3 | Temp Zone 4 |
| **NTC_ONB** | **PA4** | IN4 | On-Board NTC |
| **HP.IADPT** | **PA6** | IN6 | USB-C Input Current |
| **HP.IBAT** | **PA7** | IN7 | Battery Current (Charge/Discharge) |
| **HP.PSYS** | **PC4** | IN14 | Total System Power |

### 2.2 Data Conversion Formulas

**Thermistors (NTC)**
Standard voltage divider with 10k Pull-up to 3.3V.

**Input Current (HP.IADPT)**
Hardware: Sense Resistor = 10 mOhm, BQ25713 Gain = 20x.
```c
// Result in Amperes
float current_in_A = (adc_voltage_mV / 200.0f);

```

**System Power (HP.PSYS)**
Analog voltage proportional to system power (Battery + VBUS).

```c
// Result in Watts (Approximate, depends on R72/R69 ratio)
float power_sys_W = (adc_voltage_V * 60.0f);

```

---

## 3. Digital Communication Architecture

The system uses two separate I2C buses to isolate High Power (PD) negotiation from Low Power (System) telemetry.

### 3.1 High Power Bus (I2C_PD) - "Monitor Mode"

**Peripheral:** I2C3, **Pins:** SCL = **PA8**, SDA = **PC9**

| Device | IC | Address (7-bit) | Firmware Role |
| --- | --- | --- | --- |
| **PD Controller** | **TPS25750** | **0x20** | **Primary Target.** Query for PD Contracts & Status. Length-prefixed host interface, access via `system/tps25750_io.c` only. |
| **Charger** | **BQ25713** | N/A | **Not on this bus.** Slaved to the TPS25750 on their private `I2C_EX`; unreachable from the MCU. Its MCU-visible signals are the analog IADPT/IBAT/PSYS pins (ADC1) and the CHRG_OK / EN_OTG GPIOs. |

### 3.2 Low Power Bus (I2C_LP) - "Control Mode"

**Peripheral:** I2C1, **Pins:** SCL = **PB6**, SDA = **PB7**

| Device | IC | Address (7-bit) | Function & Configuration |
| --- | --- | --- | --- |
| **Power Monitor** | **INA3221** | **0x40** | **USB-A Current.** *Init:* CH1 (USB-A1) + CH2 (USB-A2) enabled; CH3 is tied to GND on this board. *Shunts:* 10 mOhm. |
| **Fuel Gauge** | **BQ34Z100-R2** | **0x55** | **Battery SoC.** Behind the ISO1540 isolator (battery side). Full register map below. |
| **Sec. USB-C PD** | **CYPD3175** (EZ-PD CCG3PA) | **0x08** | **Secondary port PD controller.** HPI protocol, 16-bit register addresses. Negotiates autonomously; MCU reads events/contract. |
| **Sec. USB-C Reg.** | **STPD01PUR** | **0x05** | **Programmable buck for the C2/Lab rail.** `ADD` pin grounded per netlist → 0x05. Set VOUT/ILIM, monitor faults. |

### 3.2.1 BQ34Z100-R2 Register Map (Fuel Gauge, I2C_LP @ 0x55)

These are the standard/extended commands the firmware reads from the fuel gauge.
Addresses, byte order, and units verified against the **BQ34Z100-R2 Technical
Reference Manual (SLUUCO5A)**. Multi-byte values are **little-endian** (low byte at
the lower address). The bundled `docs/bq34z100-r2.pdf` is the *datasheet* and does
**not** contain this table; it is sourced from the TRM.

| Command | Addr (LSB/MSB) | Bytes | Unit | Firmware field (`FuelGaugeSensors`) |
| :--- | :--- | :---: | :--- | :--- |
| `StateOfCharge()` | 0x02 | 1 | % | `SoC` |
| `Voltage()` | 0x08/0x09  | 2 | mV | `voltage` |
| `AverageCurrent()` | 0x0A/0x0B  | 2 | mA | `avgCurrent` |
| `Temperature()` | 0x0C/0x0D  | 2 | 0.1 K | `externalTemperature` |
| `Flags()` | 0x0E/0x0F  | 2 | bitfield| `flags` (see below) |
| `Current()` | 0x10/0x11  | 2 | mA | `current` |
| `AverageTimeToEmpty()` | 0x18/0x19  | 2 | minutes | `avgTimeToEmpty` |
| `AverageTimeToFull()`  | 0x1A/0x1B  | 2 | minutes | `avgTimeToFull` |
| `VoltScale()` | 0x20 | 1 | N/A | `voltageScale` |
| `CurrScale()` | 0x21 | 1 | N/A | `currentScale` |
| `InternalTemperature()`| 0x2A/0x2B  | 2 | 0.1 K | `internalTemperature` |
| `CycleCount()` | 0x2C/0x2D  | 2 | counts  | `cycleCount` |
| `StateOfHealth()` | 0x2E/0x2F  | 2 | % | `stateOfHealth` |

**Scaling note (per TRM §2.2):** when `VoltScale()` / `CurrScale()` return a value
> 1, the raw `Voltage()` / `Current()`, `AverageCurrent()`, and capacity readings
must be multiplied by that scale to obtain real units.

**`Flags()` bit definitions (TRM Table 2-6):**

| Byte | Bit 7 | Bit 6 | Bit 5 | Bit 4 | Bit 3 | Bit 2 | Bit 1 | Bit 0 |
| :--- | :---: | :---: | :---: | :---: | :---: | :---: | :---: | :---: |
| High | OTC | OTD | BATHI | BATLOW | CHG_INH | XCHG | FC | CHG |
| Low  | REST | RSVD | RSVD | CF | RSVD | SOC1 | SOCF | DSG |

The firmware decodes all high-byte bits and the documented low-byte bits
(`DSG`, `SOCF`, `SOC1`, `CF`, `REST`).

---

## 4. GPIO Control & Interrupts

### 4.1 Digital Outputs (Active High)

Signals used to enable power rails and modes.

| Signal Name | STM32 Pin | Hardware Target | Description |
| --- | --- | --- | --- |
| **USB_A1_CTRL** | **PC1** | Q10 (Load Switch) | Enable USB-A Port 1 Output (5V) |
| **USB_A2_CTRL** | **PC2** | Q11 (Load Switch) | Enable USB-A Port 2 Output (5V) |
| **HP.EN_OTG** | **PB15** | BQ25713 EN_OTG | Enable OTG (Reverse Power) on C1. ANDed by the charger with the I2C bit the TPS25750 sets, the MCU holding this low is an independent kill switch on C1 sourcing. |
| **STPD01_EN** | **PC11** | STPD01 Enable Pin | Enable the C2/Lab buck converter |
| **C2_PORT_EN** | **PA12** | Port FET | Route the STPD01 rail to the USB-C2 connector |
| **C2_LAB_EN** | **PA11** | Lab FET | Route the STPD01 rail to the Lab output (FSM MANUAL state; interlocked with C2_PORT_EN) |
| **BCKL_CTRL** | **PB8** | JP402 → FET | Display backlight (polarity per jumper; drive via `ILI9341_Backlight()` only) |

### 4.2 Interrupts & Status Inputs

Critical signals, polled from `readCS()` each FSM tick (the encoder button
on PC0/EXTI0 is the only line configured as a true interrupt).

| Signal Name | STM32 Pin | Trigger | Action Required |
| --- | --- | --- | --- |
| **HP.PD_IRQ** | **PB14** | Falling Edge | Read TPS25750 Event Register (Plug/Unplug). |
| **C2_ST_INT** | **PC12** | Falling Edge | Read STPD01 fault register (overcurrent/temp). |
| **C2_RDY** | **PC3** | Falling Edge | Read CYPD3175 HPI event register (PD event/fault). |
| **HP.CHRG_OK** | **PB13** | High Level | Adapter is valid. Also the DEEP_SLEEP wake gate: a button wake is only honored while this pin is high. |

---

## 5. Firmware Operational Notes

1. **Boot & Safety Sequence:**
* Check `HP.CHRG_OK` (PB13) before enabling high-current paths.
* `STPD01_EN` (PC11) stays low at boot, `initialization.c` programs the STPD01 with safe defaults (5 V / 3 A, output disabled) and enabling remains the runtime logic's job.
* Initialize `INA3221` (I2C_LP) immediately to provide OCP (Over Current Protection) for USB-A ports.

2. **Fuel Gauge Polarity Warning:**
* The hardware design places the **SRP** pin on the Cell Side and **SRN** on the System Side.
* **Action:** Ensure the BQ34Z100 flash configuration matches this polarity. If configured incorrectly, discharge current will be reported as positive charge.

3. **I2C Bus Separation:**
* **I2C_PD (I2C3: PA8 SCL / PC9 SDA)** is strictly for the TPS25750. Do not attempt to address battery-side or LP devices on this bus.
* **I2C_LP (I2C1: PB6/PB7)** carries everything else: CYPD3175, STPD01, INA3221, and the BQ34Z100 behind the ISO1540 isolator.

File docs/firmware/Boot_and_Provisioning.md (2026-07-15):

# Boot Initialization & IC Provisioning

**Scope:** the `feat/boot-camp` work, how every programmable IC on the
Ducker-Charger gets its configuration, at boot and in production.

## The four programming paths

Not everything on this board is "flashed" the same way. The complete
map:

| IC | What | When | How |
|---|---|---|---|
| STM32F401RB | application firmware | development / production | SWD (ST-Link) |
| CYPD3175 (CCG3PA) | USB-PD firmware, persistent | production + updates | SWD (MiniProg / OpenOCD `psoc4`) or CC/I2C bootloader, see `firmware/CYPD3175/README.md` |
| TPS25750 | patch + configuration bundle, **volatile** | **every boot** | streamed over I2C3 by the STM32 (`initialization.c`) |
| BQ34Z100-R2 | data-flash configuration (pack parameters, gauging) | **once**, in production | I2C, marker-guarded (`provisioning.c`) |

The BQ25713 charger has no user firmware: it is configured at runtime
by the TPS25750 through their private I2C bus (`I2C_EX`), so it never
appears in this document.

## Every-boot initialization: `Core/Src/app/initialization.c`

`System_Initialization()` runs once from `main()` (USER CODE 2 section,
after the `MX_*_Init()` calls) and configures the ICs whose settings do
not survive a power cycle, in this order:

1. **TPS25750** *(critical)*, the device is ROM-based and boots into
   patch mode: the 32 KB patch/config bundle
   (`Core/Src/app/tps25750_bundle.c`, generated from
   `firmware/TPS25750/TPS25750D_DuckerCharger.bin`) is streamed over
   I2C3 using the Patch Bundle Burst Mode protocol (`PBMs` → raw burst
   writes → `PBMc`), then the transition to `APP` mode is verified.
   Register access goes through the shared `system/tps25750_io.c`
   helpers (the host interface is length-prefixed on the wire); only
   the raw burst writes bypass them, as the burst target is a separate
   plain I2C address with no register framing.
   A warm reboot (device already in `APP`) skips the stream entirely.
   Without this step there is no PD on USB-C1 and no charging.
2. **INA3221**: configuration register: channels 1–2 enabled (channel
   3 is grounded on this board), 16-sample averaging, 1.1 ms
   conversions, continuous mode. Written and read back.
3. **STPD01**: safe defaults: VOUT 5 V, ILIM 3 A, **output disabled**.
   Turning the output on remains the runtime logic's job.

Design rules baked into the module:

- **Bounded timeouts everywhere** (50 ms per transaction), never
  `HAL_MAX_DELAY`: a dead bus degrades the boot, it must never freeze
  the product.
- Each step is retried once, then recorded as failed.
- **The boot always continues.** `Init_GetReport()` exposes the
  per-step outcome so the UI boot screen (or a UART log) can show what
  failed; a failed TPS25750 means a degraded product (no PD/charge),
  not a dead display.

## One-time provisioning: `Core/Src/app/provisioning.c`

The fuel gauge keeps its configuration in its own data flash, so this
is **not** part of the hot boot path: DF writes wear the gauge's flash
and must happen with the pack at rest.

### Version check over I2C

`Provisioning_Check()` answers "does this gauge need programming?"
in two stages:

1. `Control() DEVICE_TYPE` (0x0001) must return **0x0100**: confirms
   a BQ34Z100 actually answers at 0x55. Any other answer means wrong
   or absent silicon: the module then **refuses to write anything**.
2. A two-byte marker in *Manufacturer Info Block A*: `'D'` + a
   pack-configuration revision. Blank marker → factory-fresh gauge;
   older revision → re-provision. Bump `PROV_MARKER_1` whenever the
   patch list changes and already-deployed units re-provision
   themselves at the next check.

`Provisioning_Required()` returns 1 only for the two legitimate cases
(blank / old revision), bus errors and wrong devices are *not*
invitations to write.

### What gets written

`Provisioning_RunGauge()` (guarded by `|AverageCurrent| < 50 mA`)
unseals with the TI default keys and applies a patch list
(`GaugeDfPatch_t`: subclass, offset, bytes) through the standard
data-flash block protocol (0x3E/0x3F class+block select, 0x40 window,
0x60 checksum). Blocks whose content already matches are skipped to
spare the flash. Current list: design capacity (7800 mAh, 3P × VTC5),
series cells (4), the revision marker.

### Electrical calibration (on-device)

Shunt/divider/offset calibration is done from the device itself,
SETTINGS → Calibration, multimeter-assisted, no bqStudio needed. The
resulting DF values belong in the patch list above as golden-image
entries. Full procedure: [Gauge_Calibration.md](Gauge_Calibration.md).

### The golden image (still to do)

Static parameters are not enough for accurate gauging: the BQ34Z100
uses Impedance Track and must **learn** Qmax and the Ra tables on a
sample pack once, ChemID selection, full
charge/rest/discharge/rest learning cycle, then export. The exported
golden image becomes additional `GaugeDfPatch_t` entries, and every
production unit receives it through this same module. Until then, SoC
and capacity readings are indicative only.

## CYPD3175 (USB-C2 PD controller): `firmware/CYPD3175/`

Built separately with the Infineon EZ-PD CCGx Power SDK 3.5 + PSoC
Creator 4.4 and flashed independently from the STM32. The folder
contains the compiled hex (reference `pa_direct_fb` + our status-LED
module), the LED driver sources, minimal patches against the SDK
reference (full SDK sources are not redistributed for licensing
reasons), and the PD configuration values (PDOs 5/9/12/15/20 V @ 3 A,
protections) for the EZ-PD Configuration Utility. Details and the
rebuild procedure: `firmware/CYPD3175/README.md`.

## Open verification points

All marked `CHECK:` in the sources (`grep -rn CHECK Core/Src/app`):

| # | What | Where to verify |
|---|---|---|
| 1 | PBMs data layout and burst chunking | TPS25750 TRM, "Patch Bundle Burst Mode" |
| 2 | Burst target address (default 0x22 assumed; PBMs response reports the real one) | TPS25750 TRM |
| 3 | BQ34Z100 subclass IDs / offsets (Design Capacity, Series Cells, Mfg Info A) | BQ34Z100-R2 TRM data-flash table |
| 4 | Design capacity value (7800 mAh) vs final cell choice | pack BOM |
| 5 | CYPD3175 status-LED pin (placeholder `GPIO_PORT_1_PIN_4`) | schematic, once the CCG3PA section exists |

**Resolved since:** all IC I2C addresses now live in the single shared
header `system/defines.h`, TPS25750 settled at 0x20
(`TPS25750_PD_CONTROLLER_ADDR`), STPD01 at 0x05 (`ADD` pin grounded per
the schematic netlist, see `Charge_Management.md`).

## Maintenance notes

- **Flash budget:** the TPS bundle costs 32 KB of MCU flash. The UI and
  charge logic are now integrated in the build, re-measure with
  `arm-none-eabi-size` after significant changes (128 KB total).
- **CubeMX regeneration rewrites the Makefile** (it has no USER CODE
  sections): after every regeneration, re-check that all the application
  entries (`Core/Src/app/*.c`, `system/*.c`, `display/*.c`, `ui/*.c`)
  are still in `C_SOURCES`.
- The `main.c` hooks live inside USER CODE sections and survive
  regeneration.

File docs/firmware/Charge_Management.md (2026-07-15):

# Charge Management

## Table of Contents

- [Introduction](#introduction)
- [Telemetry](#telemetry)
	- [ADC](#adc)
	- [GPIO](#gpio)
	- [I2C1](#i2c1)
	- [I2C3](#i2c3)
- [Charging Ports](#charging-ports)
	- [USB-As](#usb-as)
	- [Primary USB-C](#primary-usb-c)
	- [Secondary USB-C](#secondary-usb-c)
- [Additional Resources](#additional-resources)

## Introduction

This document covers the implementation of the charge management system of the Ducker Charger (files `charge.h` and `charge.c`). Such system is responsible for:
- Reading all relevant sensors via `ADC` and converting appropriately the read values into correct units
- Initializing, reading and updating the statuses of ports and both critical and non-critical signals via `GPIO`
- Detecting faults (e.g. short circuit, over-temperature, etc...) and throwing interrupts accordingly
- Reading status registers and flags of different key components (`BQ34Z100-R2`, `INA3221`, `TPS25750`, `CYPD3175`, `STPD01`) via two different `I2C` channels
- Monitoring the secondary USB-C PD controller (`CYPD3175`) via HPI, reading the negotiated contract, configuring accordingly the power delivery and enabling/disabling the secondary USB-C port and the power delivery component
- Gating the primary port's OTG (source) mode through `EN_OTG` (PB15), enabled only when a sink device negotiates while the FSM allows outputs, dropped on unplug and in every protection state
- Applying the user-configurable output ceiling on the secondary USB-C port (`setSecondaryUSBC_VoltageCeiling/CurrentCeiling`): the delivered rail is `min(ceiling, negotiated contract)`, the ceiling can only lower what PD negotiated, never raise it
- Providing ready-to-use get functions for easy data fetch regarding sensors, statuses and components read

All TPS25750 register access goes through `system/tps25750_io.c`: the host interface is length-prefixed on the wire (a read returns `[len][data...]`, a write is `[reg][len][data...]`), which `HAL_I2C_Mem_*` cannot produce, hence the dedicated `tps25750_read()`/`tps25750_write()` helpers on I2C3.

---

## Telemetry

### ADC

All sensors are read via **ADC1** (12-bit resolution) according to the following table:
#### Channel Mapping
| Signal Name | STM32 Pin | ADC Channel | Description |
| :--- | :--- | :--- | :--- |
| `NTC_1` | PA0 | IN0 | Temp Zone 1 (General/FETs) |
| `NTC_2` | PA1 | IN1 | Temp Zone 2 |
| `NTC_3` | PA2 | IN2 | Temp Zone 3 |
| `NTC_4` | PA3 | IN3 | Temp Zone 4 |
| `NTC_ONB` | PA4 | IN4 | On-Board NTC |
| `HP.IADPT`  | PA6 | IN6 | USB-C Input Current |
| `HP.IBAT` | PA7 | IN7 | Battery Current (Charge/Discharge) |
| `HP.PSYS` | PC4 | IN14 | Total System Power |

*Note:* HP.IBAT is not memorized since the charge/discharge battery current is also fetched via I2C from the Fuel Gauge (`BQ34Z100-R2`). We need to read it anyway to continue the ADC scan sequence.

#### Data Conversion
Data fetched via ADC are provided in voltage and therefore need to be converted accordingly to get their correct value expressed in their proper unit measure.
First of all we need to adjust the fetched, raw voltage measure, according to our hardware specs; the function `toVoltage` performs this transformation by dividing the raw value by `VMAX` and multiplying it by `VREF` as shown:

$$
\frac{V_{raw}}{V_{MAX}} \cdot V_{REF}
$$

where: `VMAX` is equal to 2^nbits - 1 = 4095 (the ADC channel has 12-bit resolution); and `VREF` is equal to `VDD` = 3300mV.

Then we need to convert the obtained voltage value (expressed in `mV`) accordingly to the sensor we are reading:
- **Temperature:** obtained via NTC thermistors, in order to get the value expressed in ºC we need to:
	- Convert from voltage to resistance by doing:

$$
R_{PULLUP} \cdot \frac{V_{out}}{(V_{REF} - V_{out})}
$$

	- Convert from resistance to K using the Beta equation:

$$
T = \left( \frac{1}{T_0} + \frac{1}{\beta} \cdot \ln\left(\frac{R}{R_0}\right) \right)^{-1}
$$

	- Convert from K to ºC:

$$
T_{ºC} = T - 273.15
$$

- **USB-C Input Current:** given the Sense Resistor of 10 mOhm and the `BQ25713` Gain = 20x, in order to get the current value expressed in `mA` we need to divide the voltage by 0.2, or, more specifically:

$$
I = \frac{V_{out}}{R \cdot Gain} \cdot 1000
$$

- **Total System Power:**

$$
P = \frac{V_{out}}{1000} \cdot 60
$$

	- Where 60 is a hardware-derived gain constant (R72/R69 ratio)

### GPIO

#### Digital Outputs (Active High)

Signals used to enable power rails and modes.

| Signal Name | STM32 Pin | Hardware Target | Description |
| --- | --- | --- | --- |
| `USB_A1_CTRL` | PC1 | Q10 (Load Switch) | Enable USB-A Port 1 Output (5V) |
| `USB_A2_CTRL` | PC2 | Q11 (Load Switch) | Enable USB-A Port 2 Output (5V) |
| `C2_PORT_EN`  | PA12 | Port FET | Route the STPD01 rail to the USB-C2 connector |
| `C2_LAB_EN` | PA11 | Lab FET | Route the STPD01 rail to the Lab output (interlocked with `C2_PORT_EN`) |
| `HP.EN_OTG` | PB15 | BQ25713 EN_OTG | Enable OTG (Reverse Power) on C1, see the Primary USB-C section |
| `STPD01_EN` | PC11 | STPD01 Enable Pin | Enable the shared C2/Lab buck converter |

#### Interrupts & Status Inputs

Critical signals. Configure as EXTI (External Interrupt) or Polling.

| Signal Name  | STM32 Pin | Trigger | Action Required |
| --- | --- | --- | --- |
| `HP.PD_IRQ`  | PB14 | Falling Edge | Read TPS25750 Event Register (Plug/Unplug). |
| `C2_ST_INT`  | PC12 | Falling Edge | Read STPD01 fault register (overcurrent/temp). |
| `C2_RDY` | PC3 | Falling Edge | Read CYPD3175 HPI event register (PD protocol event/fault).  |
| `HP.CHRG_OK` | PB13 | High Level | Adapter is valid. Safe to start charging logic. |

### I2C1

#### BQ34Z100-R2 Register Map (Fuel Gauge @ 0x55)

These are the standard/extended commands the firmware reads from the fuel gauge.
Addresses, byte order, and units verified against the **BQ34Z100-R2 Technical
Reference Manual (SLUUCO5A)**. Multi-byte values are **little-endian** (low byte at
the lower address). The bundled [`bq34z100-r2.pdf`](../../PCB/Ducker-Charger/docs/bq34z100-r2.pdf) is the *datasheet* and does
**not** contain this table; it is sourced from the [TRM](../../PCB/Ducker-Charger/docs/BQ34Z100-R2_Technical Reference_Manual.pdf). All mentioned registers are Read-Only (RO)

| Command | Addr (LSB/MSB) | Bytes | Unit | Firmware field (`FuelGaugeSensors`) |
| :--- | :--- | :---: | :--- | :--- |
| `StateOfCharge()` | 0x02 | 1 | % | `SoC` |
| `Voltage()` | 0x08/0x09 | 2 | mV | `voltage` |
| `AverageCurrent()` | 0x0A/0x0B | 2 | mA | `avgCurrent` |
| `Temperature()` | 0x0C/0x0D | 2 | 0.1 K | `externalTemperature` |
| `Flags()` | 0x0E/0x0F | 2 | bitfield | `flags` (see below) |
| `Current()` | 0x10/0x11 | 2 | mA | `current` |
| `AverageTimeToEmpty()`  | 0x18/0x19 | 2 | minutes  | `avgTimeToEmpty` |
| `AverageTimeToFull()` | 0x1A/0x1B | 2 | minutes  | `avgTimeToFull` |
| `VoltScale()` | 0x20 | 1 | N/A | `voltageScale` |
| `CurrScale()` | 0x21 | 1 | N/A | `currentScale` |
| `InternalTemperature()` | 0x2A/0x2B | 2 | 0.1 K | `internalTemperature` |
| `CycleCount()` | 0x2C/0x2D | 2 | counts | `cycleCount` |
| `StateOfHealth()` | 0x2E/0x2F | 2 | % | `stateOfHealth` |

> **Scaling note (per TRM §2.2):** when `VoltScale()` / `CurrScale()` return a value greater than 1, the raw `Voltage()` / `Current()`, `AverageCurrent()`, and capacity readings must be multiplied by that scale to obtain real units

**`Flags()` bit definitions (TRM Table 2-6):**

| Byte | Bit 7 | Bit 6 | Bit 5 | Bit 4 | Bit 3 | Bit 2 | Bit 1 | Bit 0 |
| :--- | :---: | :---: | :---: | :---: | :---: | :---: | :---: | :---: |
| High | OTC | OTD | BATHI | BATLOW | CHG_INH | XCHG | FC | CHG |
| Low  | REST | RSVD | RSVD | CF | RSVD | SOC1 | SOCF | DSG |

**Flags Legend: RSVD = Reserved**
- **OTC:** Overtemperature in Charge condition is detected. True when set
- **OTD:** Overtemperature in Discharge condition is detected. True when set
- **BATHI:** Battery High bit that indicates a high battery voltage condition. True when set
- **BATLOW:** Battery Low bit that indicates a low battery voltage condition. True when set
- **CHG_INH:** Charge Inhibit: unable to begin charging. Refer to the data flash (Charge Inhibit Temp Low, Charge Inhibit Temp High) parameters for threshold settings. True when set
- **XCHG:** Charging not allowed
- **FC:** Full charge is detected
- **CHG:** (Fast) charging allowed. True when set
- **DSG:** Discharging detected. True when set
- **SOCF:** State of Charge is below the final (critical) low threshold
- **SOC1:** State of Charge is at threshold 1
- **CF:** Condition Flag, indicates the gauge needs a re-learning cycle. Firmware pushes `EVT_ERROR` on rising edge
- **REST:** Rest condition detected (no charge or discharge current for a sustained period)

*Note:* The firmware decodes all high-byte bits and all four documented low-byte bits (`DSG`, `SOCF`, `SOC1`, `CF`, `REST`). `CF` is the only low-byte flag that pushes an FSM event; the rest are available for the display layer

#### INA3221 Register Map @ 0x40

| Register Name | Addr (LSB/MSB) | Access | Bytes | Description |
| :--- | :--- | :----- | :---: | :--- |
| `Channel-1 Shunt Voltage` | 0x01 | R | 2 | Averaged shunt voltage value |
| `Channel-2 Shunt Voltage` | 0x03 | R | 2 | Averaged shunt voltage value |
| `Channel-3 Shunt Voltage` | 0x05 | R | 2 | Averaged shunt voltage value |
| `Mask/Enable` | 0x0F | R/W | 2 | Alert configuration, alert status indication, summation control and status |

*Note:* All data bytes are transmitted MSB first

**Data conversion:** in order to get the value of current (expressed in mA) that is passing through each channel, we need to convert the average shunt voltage value according to the following formula:

$$
I = \frac{V_{shunt} \cdot 0.04}{0.01}
$$

Where:
- 40 µV (= 0.04 mV) is the unit in which the shunt voltage is stored in the registers
- 10 mΩ is the resistance value for all shunt resistors

- **`Shunt Voltage` registers bit definitions (Starting from Table 6):**

| Bit  | Name | Access | Description |
| :--: | :--- | :----- | :--- |
|  15  | `SIGN` | R | Sign bit.  <br>0 = positive number  <br>1 = negative number in two's complement format |
| 14-3 | `SD11-0` | R | Channel's shunt-voltage data bits |
| 2-0  | `Reserved` | R | Reserved |

*Note:* the firmware right-shifts the 16-bit read by 3 positions to discard the reserved bits and isolate the signed 12-bit value

- **`Mask/Enable` bit definitions (Table 20):** (only those used by the firmware are specified)

| Bit | Name  | Access | Description |
| :-: | :---- | :----- | :--- |
|  9  | `CF1` | R/W | Critical-alert flag indicator |
|  8  | `CF2` | R/W | Critical-alert flag indicator |
|  7  | `CF3` | R/W | Critical-alert flag indicator |

*Note:* These bits are asserted if the corresponding channel measurement has exceeded the critical alert limit, resulting in the Critical alert pin being asserted

#### CYPD3175-24LQXQ HPI Register Map @ 0x08

The CYPD3175 (Cypress EZ-PD CCG3PA) uses the **HPI (Host Processor Interface)** protocol over I2C. All register addresses are **16-bit** and must be transmitted using `I2C_MEMADD_SIZE_16BIT`. The register space is split between global device registers and per-port registers.

**Global registers:**

| Register Name | Addr | Access | Bytes | Description |
| :--- | :----- | :----- | :---: | :--- |
| `INTR_REG` | 0x0006 | R/WC | 1 | Interrupt source flags; write 1 to clear each bit |

- **`INTR_REG` bit description:**

| Bit | Name | Description |
| --- | --- | --- |
| 0 | `DEV_INTR` | Device-level interrupt pending |
| 1 | `PORT0_INTR` | Port 0 interrupt pending |

**Port 0 registers (port base 0x1000, offsets per `cy_hpi_master_port_reg_t`):**

| Register Name | Addr | Access | Bytes | Description |
| :--- | :----- | :----- | :---: | :--- |
| `PORT0_TYPE_C_STATUS` | 0x100C | RO | 4 | Type-C connection state |
| `PORT0_CURRENT_PDO` | 0x1010 | RO | 4 | Active PDO contract (USB PD Fixed PDO format, little-endian) |
| `PORT0_CURRENT_RDO` | 0x1014 | RO | 4 | Active RDO from sink (USB PD RDO format, little-endian) |

- **HPI event codes; read from `RESPONSE_REG` (0x007E) per `cy_hpi_master_response_t`:**

| Code | Firmware macro | Description |
| ---- | --- | --- |
| 0x82 | `CYPD3175_EVT_OCP` | VBUS overcurrent fault |
| 0x83 | `CYPD3175_EVT_OVP` | VBUS overvoltage fault |
| 0x85 | `CYPD3175_EVT_DISCONNECT` | Type-C disconnection |
| 0x86 | `CYPD3175_EVT_CONTRACT_COMPLETE` | PD contract negotiation complete |
| 0x8F | `CYPD3175_EVT_HARD_RESET` | Hard Reset received |
| 0xB6 | `CYPD3175_EVT_OTP` | Overtemperature fault |

*Note:* the firmware reads `INTR_REG` (0x0006) to confirm a port 0 interrupt (bit 1 set), then reads the device-level `RESPONSE_REG` (0x007E) for the single-byte event code. The port 0 interrupt bit is then cleared by writing `0x02` back to `INTR_REG`. PDO/RDO data follows the standard [Fixed-Voltage PDO/RDO bit mappings](#usb-power-delivery-standard) and is decoded identically to the primary port.

####  STPD01PUR Register Map @ 0x05

*Note:* the `ADD` pin is grounded on this PCB (confirmed via schematic netlist); per the STPD01 datasheet's I2C address table, `ADD` tied to GND selects `ADD1,ADD0 = 01`, giving a 7-bit address of `0b0000101` (0x05).

| Register Name | Addr (LSB/MSB) | Access | Bytes | Description |
| :--- | :--- | :----- | :---: | :--- |
| `VOUT` | 0x00 | R/W | 1 | Set the output voltage configuration |
| `ILIM` | 0x01 | R/W | 1 | Set the output current limitation configuration |
| `INT_STAT` | 0x02 | R | 1 | Interrupt management (see below) |
| `DIGITAL_ENABLE` | 0x06 | R/W | 1 | Digital enable |

**Interrupt register description (Table 14):**

| Bit | Function | Notes |
| --- | --- | --- |
| 0 | `Overvoltage protection` | |
| 1 | `Constant current function` | |
| 2 | `Short-circuit protection` | |
| 3 | `Power` | |
| 4 | `Watchdog` | |
| 5 | `Overtemperature protection` | Junction temperature 165 °C |
| 6 | `Overtemperature warning` | Junction temperature 145 °C |
| 7 | `Inductor peak current protection` | |

*Note:* the firmware decodes all bits except 1 and 4. Bit 6 (`OTW`) is decoded and stored in `stpd01_status.overTemperatureWarning` for the display layer but does **not** block STPD01 enable, only bits 0, 2, 5, and 7 (OVP, SCP, OTP, ILIM) are treated as blocking faults in `checkSTPD01()`

### I2C3

#### TPS25750 Register Map @ 0x20

All access is length-prefixed (see `system/tps25750_io.c`): reads return `[len][data...]`, writes send `[reg][len][data...]`. The byte counts below are payload sizes, excluding the length prefix.

| Register Name | Addr (LSB/MSB) | Access | Bytes | Description |
| :--- | :--- | :----- | :---: | :--- |
| `INT_EVENT1` | 0x14 | RO |  11 | Interrupt event bit field for `I2Cs_IRQ`. If any bit in this register is 1, then the `I2Cs_IRQ` pin is pulled low |
| `INT_CLEAR1` | 0x18 | RW |  11 | Interrupt clear bit field for `INT_EVENT1`. Bits set  <br>in this register are cleared from `INT_EVENT1` |
| `POWER_STATUS` | 0x3F | RO | 2 | Details about the power of the connection |
| `ACTIVE_CONTRACT_PDO` | 0x34 | RO | 6 | Power data object for active contract. This register stores `PDO` data for the current explicit USB PD contract, or all zeroes if no contract |
| `ACTIVE_CONTRACT_RDO` | 0x35 | RO | 4 | Power data object for the active contract. This register stores the `RDO` of the current explicit USB PD contract, or all zeroes if no contract |

*Note:* `PDO` = Power Data Object; `RDO` = Request Data Object

- **`EVENT1` interrupt register description:**

| Bit | Name | Firmware field | Description |
| --- | --- | --- | --- |
| 3 | `PlugInsertOrRemoval` | `plugInsertOrRemoval` | USB Plug Status has Changed |
| 12  | `NewContractAsCons` | `newContractAsCons` | Far-end source has accepted an RDO sent by the PD Controller as a Sink |
| 13  | `NewContractAsProv` | `newContractAsProv` | An RDO from the far-end device has been accepted and the PD Controller is a Source |
| 24  | `PowerStatusUpdate` | `powerStatusUpdate` | Set whenever contents of `POWER_STATUS` register (0x3F) change |

- **`POWER_STATUS` register description:**

| Bit | Name | Firmware field | Description |
| --- | --- | --- | --- |
| 0 | `PowerConnection` | `powerConnection` | Asserted if there is a connection |
| 1 | `SourceSink` | `sourceSink` | Source / Sink indicator (0 = source; 1 = sink) |

- **`ACTIVE_CONTRACT_PDO` register description:**

| Bytes | Bits  | Name | Description |
| ----- | ----- | --- | --- |
| 5-6 | 15:10 | `Reserved` | Reserved |
| 5-6 | 9:0 | `firstPDOControlBits` | Contains bits 29:20 of the first PDO |
| 1-4 | 31:0  | `ActivePDO` | Power data object. This field contains the contents of the PDO Requested |

*Note:* the firmware extracts bits of 1-4 bytes; which contain the actual PDO contract (treated as 32-bit little endian value). The PDO contract follows the [USB Power Delivery Standard](#usb-power-delivery-standard), according to which the firmware extracts the PDO type (`pdoType`), the voltage, (`voltageRaw`) and the maximum current (`maxCurrentRaw`), the latter two are then converted respectively in `mV` and `mA`

- **`ACTIVE_CONTRACT_RDO` register description:**

*Note:* the firmware extracts bits of 1-4 bytes; which contain the actual RDO contract (treated as 32-bit little endian value). The RDO contract follows the [USB Power Delivery Standard](#usb-power-delivery-standard), according to which the firmware extracts the operating current (`operatingCurrentRaw`) and converts it into `mA`

---

## Charging Ports

In this section, a detailed explanation of the logic adopted behind each of the charging ports is provided. The powerbank exposes four output ports: two USB-A ports (`USB-A1`, `USB-A2`), a primary USB-C port (autonomously negotiated by the `TPS25750`), and a secondary USB-C port (PD negotiated autonomously by the `CYPD3175`, output regulated via the `STPD01`).

All the following logic and the firmware in general expects:
- The call of its `init` function at start, and
- The periodical call of its functions regarding: (i) sensor reading and update, (ii) components status reading and update and, (iii) critical and non-critical signals status reading and update

### USB-As

Each USB-A port provides a fixed 5V output and therefore requires no negotiation procedure. Current delivered by each port is monitored by the `INA3221`, whose reading function computes the current flowing through each channel and checks for critical-alert conditions, triggering the appropriate fault handling when needed. Both ports can be enabled/disabled by calling their respective functions `enable_USBAx()` and `disable_USBAx()`

#### Primary USB-C

The primary USB-C allows for both source and sink connections. This port is also responsible for charging the powerbank. The firmware periodically reads the `PD_IRQ` signal status in order to detect connection changes. Once it detects one, the firmware fetches from the `INT_EVENT1` the possible reasons the interrupt has been fired:
- `PlugInsertOrRemoval` detects if the USB port status has changed
- `PowerStatusUpdate` assesses if the `POWER_STATUS` register has changed
- `NewContractAsCons` detects a new contract negotiated with our device acting as **sink** (consumer)
- `NewContractAsProv` detects a new contract negotiated with our device acting as **source** (provider)

If both `PlugInsertOrRemoval` and `PowerStatusUpdate` are set, the firmware reads the `POWER_STATUS` register and updates the port's connection state and, if connected, whether the powerbank is acting as source or sink:

- **Sink** (being charged): `EVT_CHARGER_CONNECTED` is pushed and the FSM enters CHARGING.
- **Source** (OTG, powering a device): the firmware raises `EN_OTG` (PB15) via `enable_OTG()`, but only while the FSM is in IDLE or SLEEP, the same auto-enable gate used for the secondary port. Per the BQ25713 TRM, OTG output requires this pin HIGH **and** the `ChargeOption3.EN_OTG` I2C bit the TPS25750 sets on its private bus, an AND condition, so the MCU holding the pin low is an independent kill switch on C1 discharging the pack (protection-state `onEnter` handlers rely on exactly this).
- **Unplug**: `disable_OTG()` runs before `EVT_CHARGER_DISCONNECTED` is pushed.

If the port is connected and either `NewContractAsCons` or `NewContractAsProv` is set, the firmware reads the `ACTIVE_CONTRACT_PDO` register and checks the `PDO Type` field. If the contract is not Fixed-Voltage type, it is rejected; otherwise, the firmware extracts the `Voltage` and `Maximum Current` from the PDO, then reads the `ACTIVE_CONTRACT_RDO` in order to extract the `Operating Current`.

Finally, the firmware clears the bits it has read from `INT_EVENT1` by setting them in the `INT_CLEAR1` register, avoiding re-processing already-handled events.

*Note:* the `PlugInsertOrRemoval` AND `PowerStatusUpdate` gate does not currently handle a `POWER_STATUS` change occurring without a plug event

#### Secondary USB-C

The secondary USB-C port is source-only. PD negotiation is handled autonomously by the `CYPD3175` (EZ-PD CCG3PA). The MCU monitors the `C2_RDY` signal (PC3), which is wired to the CYPD3175's `GPIO_3`/interrupt pin; when it goes low, `secondaryUSBC_ConnectionINT()` is called. `C2_ST_INT` (PC12) is wired to the STPD01's `INT` pin and triggers `stpd01_PowerStateINT()` instead.

The function reads `INTR_REG` (0x0006) to confirm a port 0 interrupt (bit 1), then reads the single-byte event code from `RESPONSE_REG` (0x007E). The port 0 interrupt bit is cleared by writing `0x02` to `INTR_REG`. Events are handled as follows:

1. **OVP / OCP** (codes 0x83 / 0x82): USB-C2 and STPD01 are immediately disabled, the contract is cleared, and `EVT_FAULT_CRITICAL` is pushed.
2. **OTP** (code 0xB6): USB-C2 and STPD01 are disabled, negotiation is cleared, and `EVT_FAULT_OT` is pushed.
3. **Hard Reset** (code 0x8F): STPD01 and USB-C2 are disabled and negotiation is cleared; `isPlugged` stays true because the device is still physically present and the CYPD3175 re-advertises automatically.
4. **Disconnect** (code 0x85): contract and connection state are cleared, both STPD01 and USB-C2 are disabled.
5. **Contract complete** (code 0x86): `PORT0_CURRENT_PDO` (0x1010) and `PORT0_CURRENT_RDO` (0x1014) are read to extract the negotiated `Voltage`, `Maximum Current`, and `Operating Current` using the standard USB PD Fixed PDO/RDO bit mapping. The output is then applied through `secondaryUSBC_ApplyOutput()`, the single path shared with the ceiling setters, so a fresh contract and a live ceiling change can never diverge. It clamps the contract to the user ceiling (`min(ceiling, contract)` on both voltage and current, the CYPD3175 only negotiates; the STPD01 is what physically produces the rail, so the clamp is a real limit), configures the `STPD01` via `setupSTPD01()`, and enables it with a 10 ms stabilization delay, after which `checkSTPD01()` verifies no post-setup fault is active. If healthy, the USB-C2 output is enabled and the contract is marked as negotiated. A state gate applies before any of this: auto-enable only runs while the FSM is in IDLE or SLEEP, everywhere else the event is acked and the contract stored, but the output stays off (MANUAL is excluded too: there the STPD01 rail belongs to the Lab output).

Changing the ceiling from the UI while a device is already connected and negotiated re-runs `secondaryUSBC_ApplyOutput()` immediately, the rail is reprogrammed live, no replug needed. Since the STPD01 offers no VOUT/ILIM readback and its rail carries no shunt (INA3221 ch3 is grounded), `setupSTPD01()` records the register-decoded setpoint, exposed via `getSTPD01_SetpointVoltage()/Current()`, the quantized value the rail actually holds, which telemetry and the UI use as the source of truth for that rail.

---

## Additional Resources

### USB Power Delivery Standard
PDO and RDO contracts follow the USB Power Delivery Standard available [here](https://www.usb.org/documents)

In this section we provide the complete PDO and RDO register bit mappings used for this project and taken from the official documentation provided in the link above.

#### `Fixed-Voltage PDO` register description

| Bit(s)  | Name | Description |
| --- | --- | --- |
| 31...30 | `PDO Type` | 00b - Fixed Voltage  <br>Other values are used to describe other PDOs. |
| 29 | `Dual-Role Power` | 0b - Port cannot change Power Role via the PR_Swap Message process<br><br>1b - Port may change Power Role via the PR_Swap Message process |
| 28 | `USB Suspend Supported` | 0b - Sink Shall Not apply the [USB2], [USB3] or [USB4] rules for suspend and May continue to draw the Negotiated power<br><br>1b - Sink Shall follow the [USB2], [USB3] or [USB4] rules for suspend and resume |
| 27 | `Unconstrained Power` | 0b - The Source is limiting its available output power based on its own internal power usage.<br><br>1b - An external Source of power is available that is sufficient to adequately power the Source system while charging external devices, or when the Source's primary function is to charge external devices |
| 26 | `USB Communications Capable` | 0b - Port is not capable of communication over the USB data lines<br><br>1b - Port is capable of communication over the USB data lines |
| 25 | `Dual-Role Data` | 0b - Port cannot change Data Role via the DR_Swap Message process<br><br>1b - Port may change Data Role via the DR_Swap Message process |
| 24 | `Unchunked Extended Messages Supported` | 0b - Port does not support Unchunked Extended Message<br><br>1b - Port supports both Chunked and Unchunked Extended Message |
| 23 | `EPR Capable` | 0b - Source will only provide power Capabilities in the Standard Power Range<br><br>1b - Source is capable of providing power Capabilities in the Extended Power Range. The Source may enter EPR Mode when requested by an EPR Capable Sink |
| 22 | `Reserved` | **Reserved**, receiver **Shall** ignore this field |
| 21...20 | `Peak Current` | Peak Current |
| 19...10 | `Voltage` | Voltage, **in 50mV units** |
| 9...0 | `Maximum Current` | Maximum amount of current supported at this voltage, **in 10mA units** |

*Note:* the firmware always extracts the **Voltage** (bits 19:10) and **Maximum Current** (bits 9:0) fields from each PDO. For the primary USB-C port, it additionally extracts the **PDO Type** to verify the contract is Fixed-Voltage type before proceeding; the secondary USB-C port assumes PDOs configured as Fixed-Voltage type only. Bits 29:20 (flags, peak current) are not currently read or used by `charge.c`

#### `Fixed-Voltage RDO` register description

| Bit(s)  | Name | Description |
| --- | --- | --- |
| 31...28 | `Object Position` | Indicates the corresponding PDO configuration location |
| 27 | `Giveback` | **Deprecated**, receiver **Shall** ignore this field. |
| 26 | `Capability Mismatch` | |
| 25 | `USB Communications Cable` | |
| 24 | `No USB Suspend` | |
| 23 | `Unchunked Extended Messages Supported` | |
| 22 | `EPR Capable` | |
| 21...20 | `Reserved` | **Reserved**, receiver **Shall** ignore this field. |
| 19...10 | `Operating Current` | Operating current, **in 10mA units**<br><br>Indicates the highest current the Sink will draw during the Explicit Contract. |
| 9...0 | `Maximum Operating Current` | **Deprecated**, transmitter **Shall** set this field equal to "Operating Current", receiver should ignore this field. |

*Note:* the firmware extracts **Operating Current** (bits 19:10) from every RDO contract. For the secondary USB-C port the CYPD3175 handles PDO negotiation internally; the firmware reads the already-resolved contract directly from `PORT0_CURRENT_PDO` (0x1010) and `PORT0_CURRENT_RDO` (0x1014), no Object Position lookup is needed

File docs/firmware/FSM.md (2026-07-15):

# Power Bank FSM

## Table of Contents

- [Introduction](#introduction)
- [Architecture](#architecture)
  - [Layer Responsibilities](#layer-responsibilities)
  - [Data Flow](#data-flow)
- [Events](#events)
  - [Event List](#event-list)
  - [Event Queue](#event-queue)
  - [Event Producers](#event-producers)
- [States](#states)
  - [State Overview](#state-overview)
  - [SoC and Voltage Thresholds](#soc-and-voltage-thresholds)
  - [State Behaviors](#state-behaviors)
- [Transition Matrix](#transition-matrix)
  - [Overcharge (`ovchargeBlock`)](#overcharge-ovchargeblock)

---

## Introduction

This document describes the Finite State Machine (FSM) that governs the overall operating behavior of the Ducker Charger. The FSM determines which state the device is in at any given time, controlling which ports are active, what the display shows, and how the system reacts to hardware events such as low battery, fault conditions, or charger connection.

The FSM is implemented in `firmware/cubeMX/Core/Src/system/fsm.c` using a **hybrid vtable + transition matrix** approach:
- The **vtable** defines the behavior of each state through three handlers: `onEnter`, `onRun`, and `onExit`.
- The **transition matrix** encodes when to leave a state: a 2D lookup table indexed by `[current state][event]` returns the next state, keeping transition logic fully decoupled from state behavior.

---

## Architecture

### Layer Responsibilities

| Layer | Files | Role |
| :---- | :---- | :--- |
| Charge Management | `system/charge.h/.c` | Reads all sensors, drives all actuators (`enable/disable_*`), pushes events to the queue. Knows nothing about the FSM. |
| FSM | `system/fsm.h/.c` | Consumes events, determines state transitions, calls charge layer actuators in Enter/Exit handlers. Never pushes events. |
| Event Queue | `system/event.h/.c` | Ring buffer decoupling event producers from the FSM consumer. |
| Display / UI | `ui/`, `display/` | Reads charge layer getters read-only. Never writes to charge state. |
| Main Loop | `main.c` | Calls `readNCS()` each tick to refresh port status variables, drains one event from the queue, calls `PB_FSM_FireEvent()`, checks the inactivity and deep-sleep-hold timers, calls `PB_FSM_Update()`, then `Telemetry_Poll()` (here and not in `UI_Tick()`, so uptime/energy/port histories keep running while the screen is dark in SLEEP), and finally `UI_Tick()` unless the FSM has the backlight off. |

### Data Flow

```
charge.c  ──getters──►  fsm.c  ──getters──►  display / ui.c
  (data +               (logic)
  actuation)◄──enable/disable──┘
     │
     │  event_push()
     ▼
 event_queue  (ring buffer, 8 slots)
     │
     │  drained each main-loop tick
     ▼
 PB_FSM_FireEvent()  →  TransitionTable lookup  →  PB_FSM_RequestState()
                                                          │
                                                          ▼
                                                   PB_FSM_Update()  →  onExit / onEnter / onRun
```

The flow is **unidirectional**: the charge layer pushes events and the FSM consumes them. The FSM's `Run()` handlers call charge layer getters for display data and `enable/disable_*` actuators in `Enter`/`Exit`; they never call `event_push()`.

---

## Events

Events are the signals that drive FSM transitions. They are produced by the charge management layer, ISRs, and the main loop, then consumed by the FSM. Neither layer needs to know about the other's internals, the event queue is the only coupling point between them.

### Event List

| Event | Trigger |
| :---- | :--- |
| `EVT_CHARGER_CONNECTED` | Primary USB-C plug detected |
| `EVT_CHARGER_DISCONNECTED` | Primary USB-C removed |
| `EVT_SOC_SAFETY` | SoC drops below 15% |
| `EVT_SOC_LOWV` | SoC drops below 10% |
| `EVT_SOC_UNDERV` | `BATLOW` flag set or pack voltage below damage threshold |
| `EVT_SOC_OK` | SoC recovers above 15% |
| `EVT_SOC_OVCH` | BQ34Z100 `BATHI` flag set, overcharge detected |
| `EVT_FAULT_OT` | `OTC`/`OTD` flags or STPD01 OTP, recoverable overtemperature |
| `EVT_FAULT_CRITICAL` | BMS dead / I2C loss on fuel gauge, unrecoverable |
| `EVT_FAULT_OCC` | Overcurrent on charging input (INA3221) |
| `EVT_ERROR` | General recoverable error (I2C fault, sensor read fail) |
| `EVT_ERROR_CLEAR` | Error condition resolved |
| `EVT_INACTIVITY` | No user input for `INACTIVITY_TIMEOUT_MS` (2 min) |
| `EVT_BUTTON_SHORT` | Encoder button short press |
| `EVT_BUTTON_LONG` | Encoder button held ≥ 3 s then released, or the UI DISPLAY page's "Shutdown" row confirmed |
| `EVT_MANUAL_ENTER` | UI enables the Lab output channel (OUTPUT page) |
| `EVT_MANUAL_EXIT` | UI disables the Lab output channel |
| `EVT_LOCK` | UI "Lock all": user-requested SAFETY_LOCK (sets `userLock`) |
| `EVT_UNLOCK` | UI "Lock all" off, honored only if the lock was user-initiated |

### Event Queue

Events are stored in an 8-slot ring buffer defined in `system/event.h/.c`. The queue exposes three functions:

```c
void event_push(Event_t event);  // called by charge layer and ISRs
bool event_pop(Event_t *out);    // called by main loop each tick; returns false if empty
bool event_pending(void);        // returns true if at least one event is waiting
```

If the queue is full, `event_push()` silently drops the incoming event. The queue is drained every main loop iteration before `PB_FSM_Update()` is called.

### Event Producers

| Source | Events pushed |
| :----- | :--- |
| `primaryUSBC_ConnectionINT()` | `EVT_CHARGER_CONNECTED`, `EVT_CHARGER_DISCONNECTED` |
| `readSensors()` | `EVT_SOC_SAFETY`, `EVT_SOC_LOWV`, `EVT_SOC_UNDERV`, `EVT_SOC_OK`, `EVT_SOC_OVCH`, `EVT_FAULT_OT`, `EVT_FAULT_CRITICAL` |
| `readINA()` | `EVT_FAULT_OCC` |
| `stpd01_PowerStateINT()` | `EVT_FAULT_CRITICAL` (OVP/SCP/ILIM), `EVT_FAULT_OT` (OTP) |
| `secondaryUSBC_ConnectionINT()` | `EVT_ERROR` |
| Any `HAL_I2C_Mem_Read` → `HAL_ERROR` | `EVT_ERROR` |
| Encoder button ISR | `EVT_BUTTON_SHORT`, `EVT_BUTTON_LONG` |
| UI DISPLAY page "Shutdown" (confirmed) | `EVT_BUTTON_LONG`, same primitive as the physical 3 s hold, subject to the same transition-table gate |
| Main loop inactivity timer | `EVT_INACTIVITY` |
| UI OUTPUT page (Lab channel enable/disable) | `EVT_MANUAL_ENTER`, `EVT_MANUAL_EXIT` |
| UI SETTINGS "Lock all" | `EVT_LOCK`, `EVT_UNLOCK` |
| UI FAULT screen OK button | `EVT_BUTTON_SHORT` (ERROR acknowledge) |
| `Idle_Enter` re-validation | `EVT_CHARGER_CONNECTED`, `EVT_SOC_LOWV`, `EVT_SOC_SAFETY` (edge-detected producers cannot re-fire for conditions that persisted across a protection state) |

---

## States

### State Overview

| State | SoC Range | Output Ports | Display |
| :---- | :--- | :--- | :--- |
| `IDLE` | 100% – 15% | All active | ON |
| `SAFETY_LOCK` | 15% – 10% | All detached | ON |
| `LOW_V` | 10% – UNDERV threshold | All detached | OFF |
| `EMERGENCY` | Below UNDERV threshold | All detached | OFF |
| `CHARGING` | Any | All detached | ON |
| `MANUAL` | Any | C2 = LAB mode, A1/A2 active | ON |
| `SLEEP` | Any | Unchanged from previous state | OFF |
| `DEEP_SLEEP` | Any | All detached | OFF |
| `ERROR` | Any | Faulted subsystem only detached | ON |

*Note:* There is no `BOOT` state, peripheral initialization runs before `PB_FSM_Init()` is called.

*Note:* There is no hard port "off", all port disable operations use the detach path (controller stays powered, output disabled).

*Note:* "All detached" includes the C1 OTG source path: protection states (`SAFETY_LOCK`, `LOW_V`, `EMERGENCY`, `DEEP_SLEEP`) also call `disable_OTG()`, dropping `EN_OTG` (PB15). Per the BQ25713 TRM, OTG mode requires that pin HIGH **and** the I2C enable bit the TPS25750 sets (an AND condition) so the MCU holding it low is a real, independent kill switch on C1 ever discharging the pack, even with a sink device still plugged in. `CHARGING` does not need the call: C1 cannot be sink and source on the same connector at once.

### SoC and Voltage Thresholds

A hybrid approach is used: **SoC** (from BQ34Z100 coulomb counting) for the upper thresholds because it is the user-facing metric, and **pack voltage / `BATLOW` flag** for the undervoltage threshold because it directly reflects hardware protection limits.

```c
#define SOC_SAFETY_THRESHOLD    15.0f    // %, IDLE → SAFETY_LOCK
#define SOC_LOWV_THRESHOLD      10.0f    // %, SAFETY_LOCK → LOW_V
#define UNDERV_VOLTAGE_MV     3000.0f    // mV/cell, LOW_V → EMERGENCY
#define SOC_OK_THRESHOLD        15.0f    // %, recovery back to IDLE
#define INACTIVITY_TIMEOUT_MS  120000    // ms, IDLE/CHARGING/LOW_V → SLEEP
```

`INACTIVITY_TIMEOUT_MS` deliberately matches the UI DISPLAY page's default
"Auto sleep" setting (2 min) so the FSM's own inactivity sleep does not
silently pre-empt the user-facing option.

The `BATLOW` flag from the BQ34Z100 (`fuelGaugeSensors.flags.BATLOW`) is used as the primary UNDERV trigger, the gauge raises it when the configured minimum cell voltage is reached.

### State Behaviors

Each state implements three handlers (`onEnter`, `onRun`, `onExit`) defined in `system/fsm.c`.

#### DEEP_SLEEP

`onEnter` is the unusual one; it blocks. After detaching all ports (including the C1 OTG source path via `disable_OTG()`) and turning the display off, it calls `HAL_SuspendTick()` (otherwise SysTick would immediately wake the MCU) then `HAL_PWR_EnterSTOPMode()`, which puts the Cortex-M4 into STOP mode: PLL and most clocks are gated, RAM is retained, current drops from ~20 mA to ~20 µA. The processor halts at that line until an EXTI fires. **The encoder button (EXTI0, both edges) is the only configured wake source**, no other pin has an EXTI handler, so plugging in a charger cannot, by itself, wake the MCU. When the button edge arrives, `HAL_PWR_EnterSTOPMode` returns on the internal HSI oscillator (the PLL was killed by STOP), so `SystemClock_Config()` restores the correct frequency, followed by `HAL_ResumeTick()`.

**Wake gate:** a button press alone is not honored. `onEnter` loops: after each STOP-mode exit it reads `HP_CHRG_OK` (PB13, the BQ25713 valid-adapter output) and, if no charger is present, re-enters STOP immediately, screen and ports never come back, no event fires, externally indistinguishable from "nothing happened". Only a press *while a charger is attached* breaks the loop; `onEnter` then pushes `EVT_BUTTON_SHORT` itself (nothing else would, the FSM would stay trapped otherwise), driving `DEEP_SLEEP → IDLE`, and `Idle_Enter`'s contract re-validation immediately converges to CHARGING. Once awake, unplugging the charger does **not** return the device to DEEP_SLEEP; it is fully on, and only the explicit shutdown paths (3 s hold or the UI Shutdown row) put it back.

`onRun` is a no-op: by the time it is called, `onEnter` has already returned post-wakeup and pushed the event. The main loop will pop it and fire the transition on the next iteration.

`onExit` turns the display back on.

#### SLEEP

Lighter than DEEP_SLEEP, the MCU stays fully running, only the display turns off. Ports are intentionally **not touched** in `onEnter` because SLEEP can be reached from any state (IDLE, CHARGING, LOW_V…) and each of those already left ports in the correct state. Touching them here would break CHARGING's port state, for example.

`onRun` runs the full poll, `readCS()`, `readSensors()`, `readINA()`. `readCS()` is required so that `PD_IRQ` is serviced while sleeping: without it, `EVT_CHARGER_CONNECTED` could never fire from SLEEP and the SLEEP → CHARGING transition would be unreachable. `readINA()` is included because ports are not touched on SLEEP entry, if the device fell asleep from IDLE, USB-A1/A2 are still active and need overcurrent monitoring.

`onExit` turns the display back on when waking.

#### IDLE

The "everything is fine" state. `onEnter` re-enables both USB-A ports and the display. `enable_USBC2()` and `enable_STPD01()` are **not** called here because the secondary USB-C is managed through its own negotiation flow in `readCS()` and `secondaryUSBC_ConnectionINT()`, the FSM does not reach in and enable it directly.

`onRun` does a full sensor poll each tick (`readCS()`, `readSensors()`, `readINA()`) so the charge layer can detect threshold crossings and push events.

`onExit` is empty, the next state's `onEnter` handles its own setup.

#### CHARGING

When the device is being charged it gives all available power to the battery, no outputs. `onEnter` disables everything. `onRun` continues the full sensor poll so fault events (`EVT_FAULT_OCC`, `EVT_SOC_OVCH`) are detected while charging.

`onExit` deliberately does **not** re-enable anything: the destination state decides. `Idle_Enter` re-enables USB-A1/A2 (normal unplug path); CHARGING → SLEEP on inactivity keeps them off, charging continues in SLEEP with the same no-outputs policy as CHARGING itself. USBC2 and STPD01 always go through the CYPD3175 negotiation flow.

#### SAFETY_LOCK

Battery is low, detach everything and wait, **or** the user asked for it: the SETTINGS "Lock all" row pushes `EVT_LOCK`, which lands here with the `userLock` flag set, and `EVT_UNLOCK` (same row) releases it back to IDLE. The unlock is refused while `userLock` is clear, so a low-SoC lock cannot be dismissed from the menu; leaving SAFETY_LOCK by any path clears `userLock`. The display stays on so the user can see the SoC. `onRun` keeps polling so `EVT_SOC_LOWV` (further drain) or `EVT_SOC_OK` (charger brought it back) can be detected. `EVT_FAULT_OT` and `EVT_ERROR` also escalate to `STATE_ERROR` from here. (Overcharge no longer routes here, see [Overcharge](#overcharge-ovchargeblock).)

`onExit` is empty, the destination state's `onEnter` handles re-enabling whatever is appropriate.

*Note:* `onRun` does not currently call `readINA()`, unlike every other actively-monitored state, an INA3221 overcurrent condition is not detected while locked in this state.

#### LOW_V

`onEnter` disables all ports and turns the display off. The disable calls are redundant on the normal path (arriving from SAFETY_LOCK, ports are already off) but necessary for paths coming from SLEEP, IDLE, or ERROR where ports may still be active. At this SoC level every milliamp counts and the display is not worth the draw.

`onRun` keeps sensors alive so `EVT_SOC_UNDERV` and `EVT_CHARGER_CONNECTED` can still be detected.

*Note:* like `SAFETY_LOCK`, `onRun` does not currently call `readINA()`, an INA3221 overcurrent condition is not detected while in this state either.

#### EMERGENCY

Terminal state. Everything detaches, the MCU keeps running but does nothing further. `onRun` is empty; there are no outgoing transitions in the matrix so `PB_FSM_FireEvent()` will never trigger a state change from here. `onExit` is never called in practice. The display message is left for the display layer to handle.
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

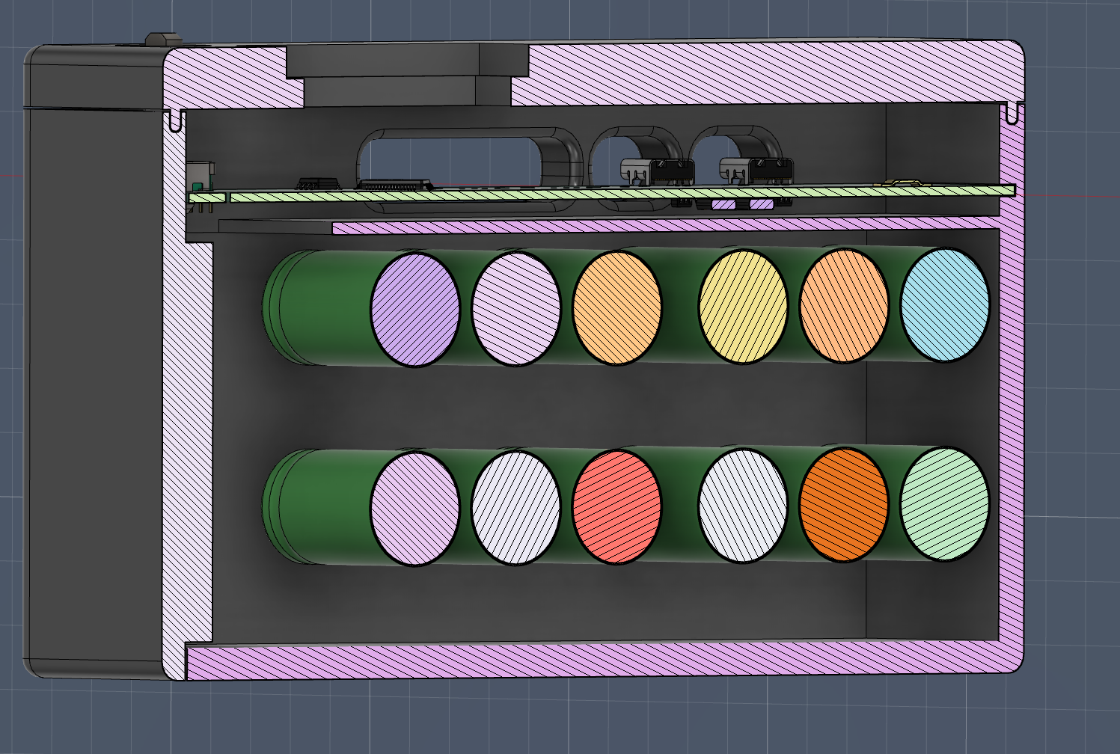
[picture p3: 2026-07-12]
powerbank_enclosure/renders/top_section_cells.png

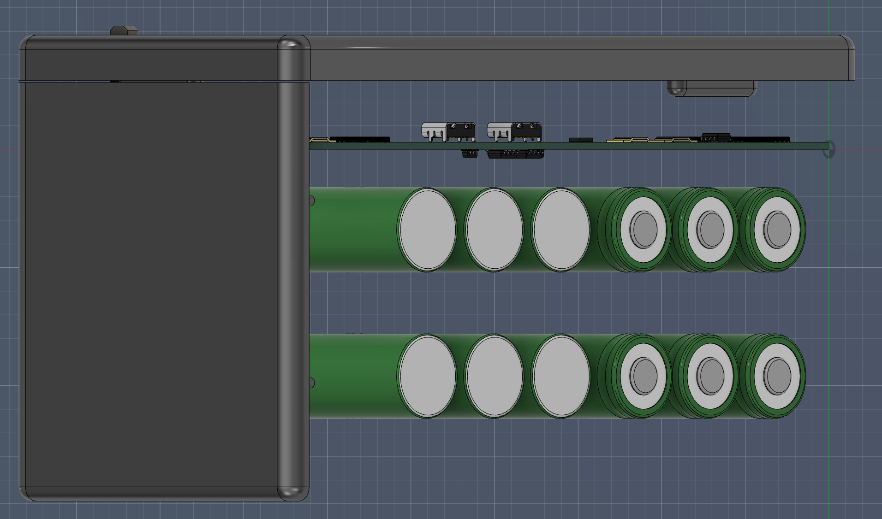
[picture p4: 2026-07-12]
powerbank_enclosure/renders/side_view.png

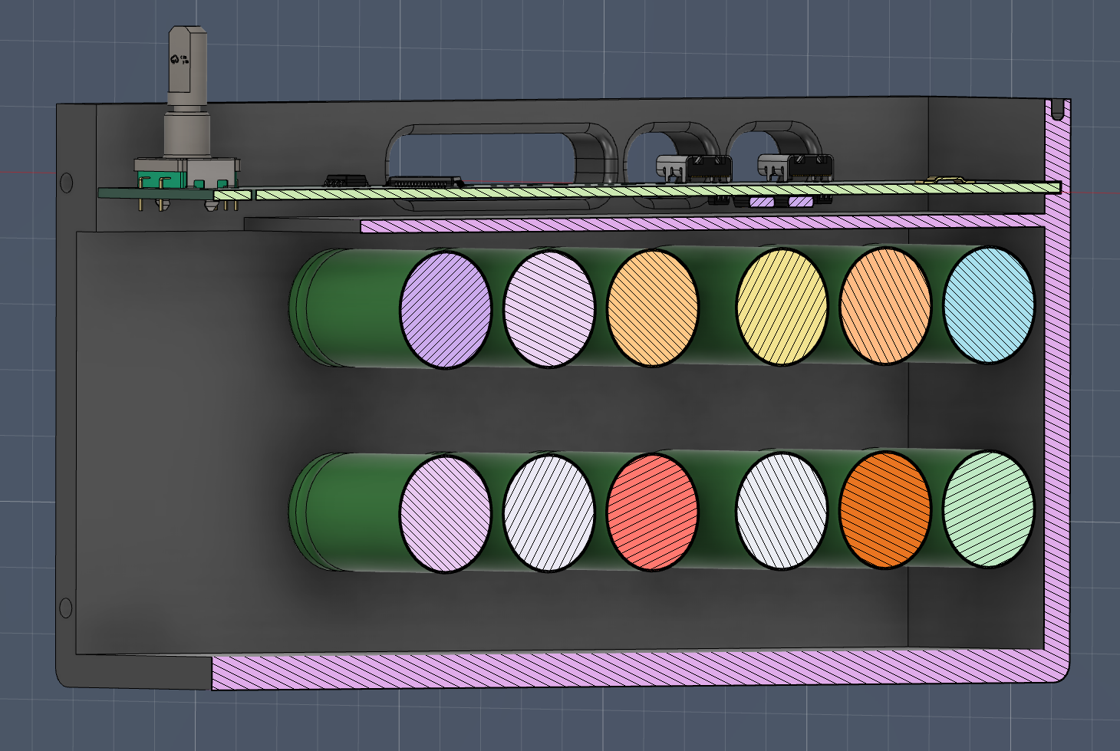
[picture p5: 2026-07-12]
powerbank_enclosure/renders/top_section_lid_off.png

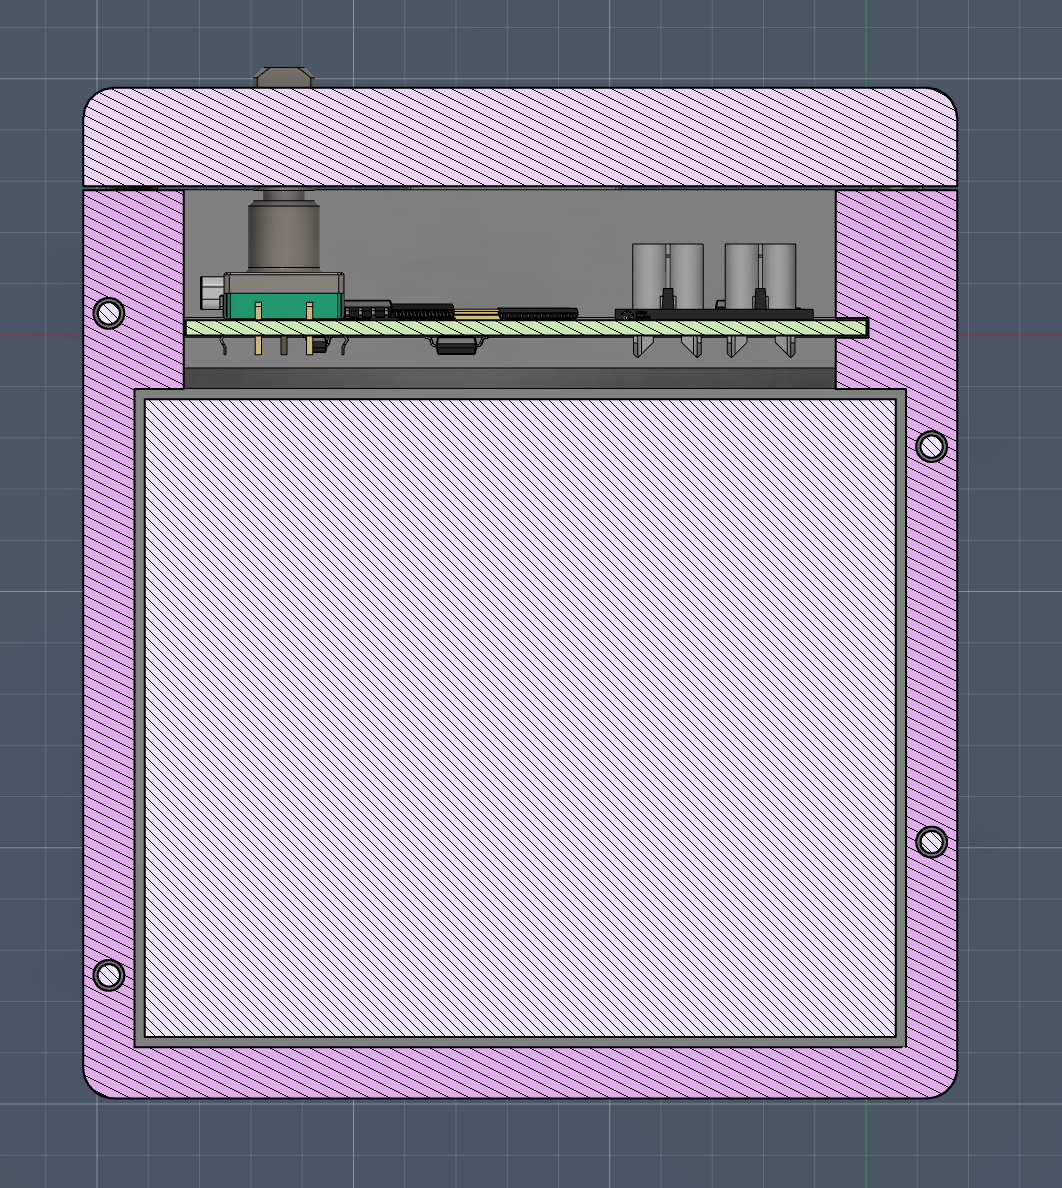
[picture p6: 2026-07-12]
powerbank_enclosure/renders/front_view.png

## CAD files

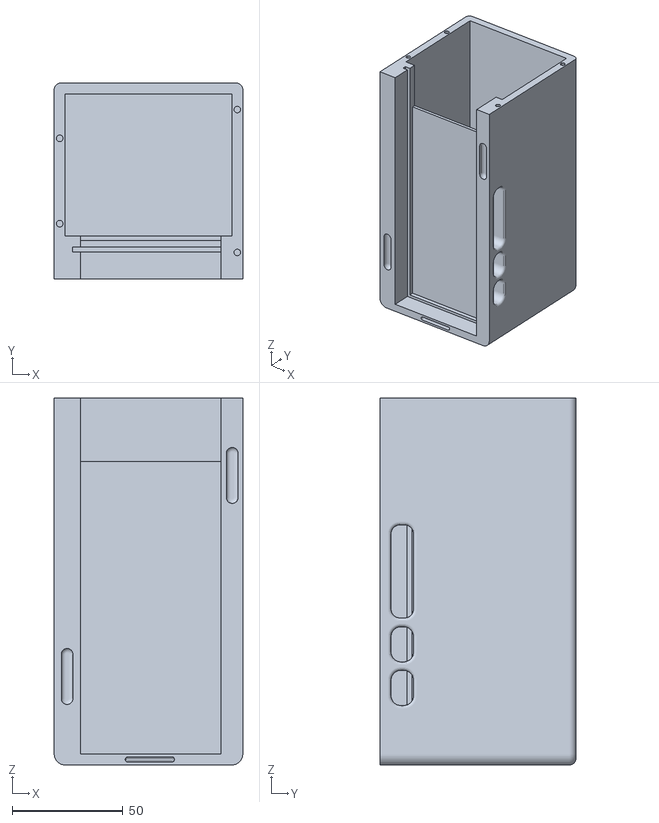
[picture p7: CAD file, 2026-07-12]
powerbank_enclosure/Enclosure_(prototype_3).stl
85.3 x 88.6 x 165.8

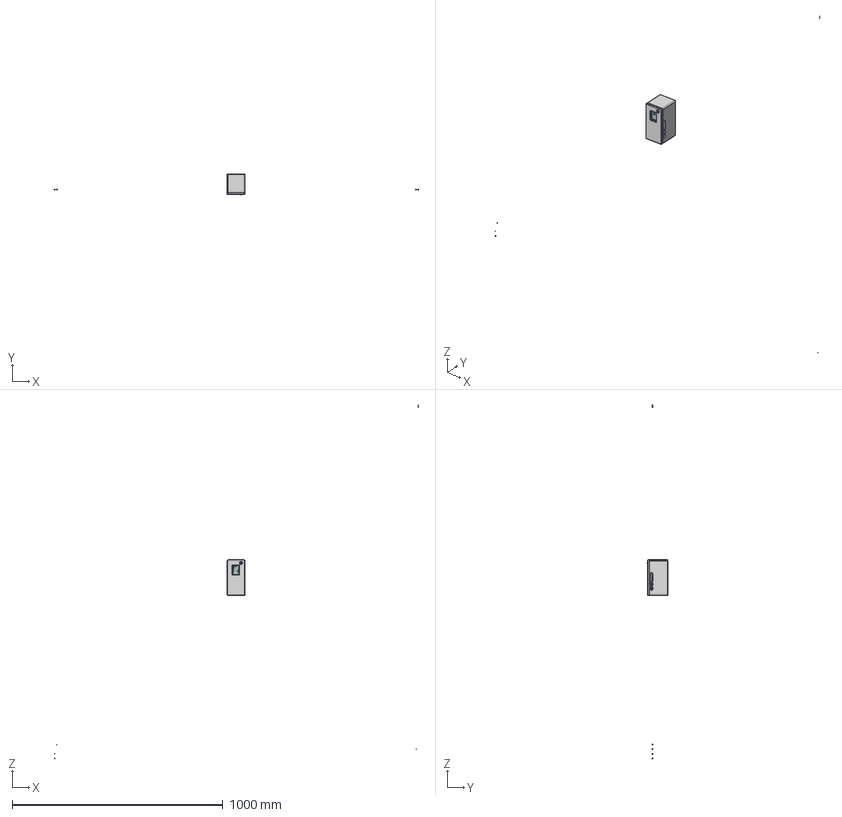
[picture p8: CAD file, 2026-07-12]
powerbank_enclosure/Power_bank_enclosure_(prototype_3).step
1727.8 x 100.5 x 1678.9 mm
PG-TDSON-8_L5.9-W5.1-P1.27-LS6.2-BL_6 x 6
SOIC-8_L4.9-W3.9-H1.7-LS6.0-P1.27_4 x 4
R3920_3 x 3
QFN-32_L4.0-W4.0-H0.8-P0.40-BL-EP2.8_1
FUSE-TH_3522-2_1
TSSOP-24_L7.8-W4.4-H1.0-LS6.4-P0.65_1
USB-C_SMD-TYPE-C-31-M-12 x 2
SW-TH_EC11E15244G1-L11.7-W12.0-H24.5-P2.5-LS14.5_1
LQFP-64_L10.0-W10.0-H1.4-LS12.0-P0.50_1
QFN-24_L4.0-W3.0-P0.40-TL-EP_1
SOT-23-6_L2.9-W1.6-H1.5-LS2.8-P0.95_2 x 2
SOT-23-3P_L2.9-W1.3-H1.0-LS2.4-P0.95_6 x 6
Ducker-Charger_PCB
18650 Battery
18650 Battery_1
18650 Battery_2
18650 Battery_3
18650 Battery_4
18650 Battery_5
18650 Battery_6
18650 Battery_7
18650 Battery_8
18650 Battery_9
18650 Battery_10
18650 Battery_11
Enclosure v6
Short_side_lid
Upper_lid

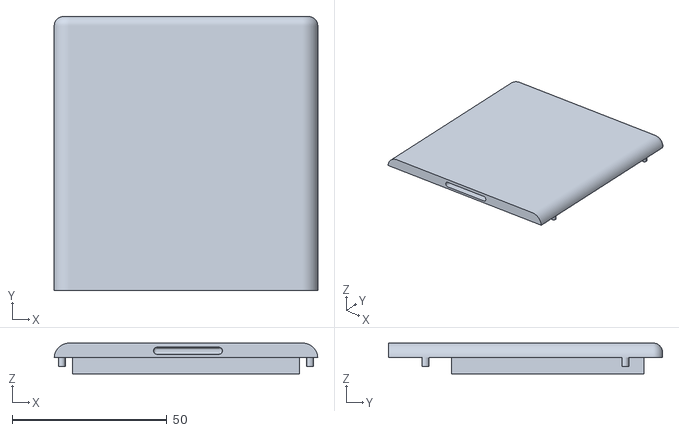
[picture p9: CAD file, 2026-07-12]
powerbank_enclosure/Short_side_lid_(prototype_3).stl
85.2 x 88.6 x 10.0

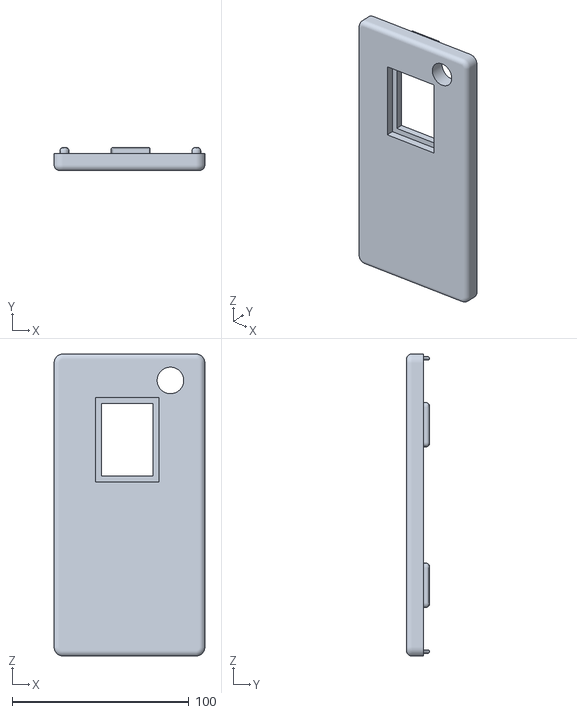
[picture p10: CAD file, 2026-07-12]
powerbank_enclosure/Upper_lid_(prototype_3).stl
85.3 x 13.0 x 170.8

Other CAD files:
powerbank_enclosure/Power_bank_enclosure_(prototype_3).f3d

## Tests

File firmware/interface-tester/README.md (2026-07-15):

# interface-tester

Native desktop simulator for the Ducker-Charger UI.
Compiles the real firmware UI sources against a fake framebuffer instead of
the SPI display, so you can see and interact with every screen without hardware.

## Quick start

```sh
# needs gcc + SDL2
# Arch:   sudo pacman -S sdl2
# Ubuntu: sudo apt install libsdl2-dev

./build.sh   # (re)compile sim_ui from the current firmware sources
./run.sh     # launch sim_ui, compiles it first if missing
```

The window is 240×320, the same resolution as the real display.

## Controls

| Key | Action |
|-----|---|
| Arrow up / mouse wheel up | Rotate encoder right (+1 click) |
| Arrow down / mouse wheel down | Rotate encoder left (−1 click) |
| Space (tap) | Encoder press (short click) |
| Space held ≥ 1 s | Long press → opens SETTINGS overlay |
| Double space within 400 ms | Jump straight to SETTINGS |
| ESC | Quit |

## Fake sensor data: sim_config.ini

Edit `sim_config.ini` and relaunch to change what the UI displays.
No rebuild needed, the file is read every time at startup.

Key fields:

| Key | What it does |
|-----|---|
| `soc` | State of charge 0–100 % |
| `pack_mv` | Pack voltage in mV (typical 11000–16800) |
| `batt_ma` | Battery current: positive = charging, negative = draining |
| `batt_ripple` | Sine amplitude on `batt_ma` (0 = flat line on graph) |
| `temp_c` | Battery temperature in °C |
| `vbus` | 1 = USB-C charger plugged in |
| `phase` | Charger phase: 0 idle · 1 charging (the real UI can't tell pre-charge/taper apart, the chip that knows sits on a bus this MCU can't reach) |
| `a1/a2/c1/c2/lab_active` | Port enabled/disabled |
| `*_mv` / `*_ma` / `*_ripple` | Per-port voltage, current, graph ripple |
| `tte_min` / `ttf_min` | Time-to-empty / time-to-full shown under SoC |
| `cycles`, `health`, `cap_*` | OVERALL DATA screen, lifetime gauge stats |

Set `batt_ma` negative and `vbus = 0` to simulate discharging.
Set `temp_c = 65` to trigger the over-temperature warning.
Set `soc = 4` to trigger the critical low-battery warning + sleep.

## What each file does

| File | Role |
|---|---|
| `build.sh` | Recompile `sim_ui` from the current firmware sources |
| `run.sh` | Launch `sim_ui`; compiles it first if the binary is missing |
| `sim_config.ini` | Fake sensor data, read at startup |
| `Makefile` | Build rules; UI sources pulled from `../cubeMX/Core/Src/` |
| `src/stm32f4xx_hal.h` | Minimal HAL stub (HAL_GetTick, GPIO, SPI types) |
| `src/main.h` | GPIO pin name stubs matching the real firmware `main.h` |
| `src/sim_config.h/c` | INI file parser and `SimCfg` struct |
| `src/sim_stubs.c` | HAL + encoder + telemetry stubs; feeds fake data to the UI |
| `src/sim_display.c` | Implements ILI9341 API against an in-memory RGB565 framebuffer |
| `src/sdl_main.c` | SDL2 window, event loop, keyboard/mouse → encoder events |

## How it links to the firmware

The Makefile compiles these files **directly from the firmware tree**:
no copies:

```
../cubeMX/Core/Src/display/gfx.c
../cubeMX/Core/Src/ui/widgets.c
../cubeMX/Core/Src/ui/screens.c
../cubeMX/Core/Src/ui/ui_state.c
```

`-Isrc` is listed first so the stub headers (`stm32f4xx_hal.h`, `main.h`)
shadow the real HAL. Everything else comes from `../cubeMX/Core/Inc`.

After editing any UI file, run `./build.sh` then `./run.sh` to see the result.
`sim_ui` is not committed to git; it is always generated locally.

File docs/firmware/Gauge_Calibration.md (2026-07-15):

# Fuel-Gauge Calibration (on-device wizard)

The BQ34Z100-R2 needs a one-time electrical calibration before its
readings can be trusted: shunt, voltage divider and layout all carry
tolerances that only a comparison against an external reference can
remove. This project does it **entirely on the device**: SETTINGS →
**Calibration**: with a multimeter as the only external tool. No
bqStudio, no EV2400.

Code: backend `Core/Src/app/calibration.c`, UI `Screen_Cal_*` in
`Core/Src/ui/screens.c` (page `UI_SCREEN_CALPG`).

## Why this is not "just another config"

Boot-camp (`initialization.c`) and provisioning (`provisioning.c`)
write **constants known at compile time**. Calibration values are
**measured, per-board**: they come out of comparing the gauge's own
reading with a multimeter. Once measured they live in the gauge's own
data flash: **non-volatile, no further action needed**: the wizard is
the whole "first pack attach" procedure. Copying the values into the
`provisioning.c` patch list is an *optional* backup, useful only if
the gauge chip is ever replaced or its data flash reset (the review
step shows the values for that purpose).

## Method: the ratio method

The TRM does not document the raw-ADC registers bqStudio uses, but all
three measurements are **linear** in their DF parameter, so a
correction needs only the *reported* value:

```
Voltage Divider' = Voltage Divider x V_multimeter / Voltage()
CC Gain'         = CC Gain         x I_multimeter / Current()
CC Delta'        = CC Gain' x 1190738          (fixed TRM ratio)
Ext Temp Offset' += (T_true - Temperature())   (0.1 C units)
```

Offsets cannot be ratio'd (they are additive at zero signal): the
wizard uses the gauge's **internal routines**: Control() `CC_OFFSET`
(0x000A) + `CC_OFFSET_SAVE` (0x000B), then `BOARD_OFFSET` (0x0009),
polling the `CCA`/`BCA` bits in `CONTROL_STATUS` until they clear.

DF target: subclass **104 (Calibration/Data)**: CC Gain (F4 @0),
CC Delta (F4 @4), CC Offset (I2 @8), Board Offset (I1 @10), Int/Ext
Temp Offset (I1 @11/12), Voltage Divider (U2 @14). F4 is the TI/Xemics
float format (codec in `calibration.c`). Same block protocol and
default unseal keys as `provisioning.c`.

## The wizard, step by step

| Step | What you do | What the firmware does |
|---|---|---|
| 1/9 GAUGE CHECK | press CHECK | `DEVICE_TYPE` must answer 0x0100, unseal (TI default keys). Wrong device → refuses everything. |
| 2/9 ZERO OFFSET | get the current through the shunt to **true ~0 mA** (best: MCU powered from the SWD connector, every load off), press START | runs `CC_OFFSET` + `BOARD_OFFSET` internally (~20 s budget), saves both |
| 3/9 VOLTAGE | multimeter on the pack terminals, dial the reading in (10 mV steps), press APPLY | rewrites `Voltage Divider` by the ratio |
| 4/9 CURRENT | attach any steady load through the multimeter (10 A range) on USB-A1, dial the reading, press CAPTURE; **remove the load**, press SAVE | captures the ratio under load, writes `CC Gain`/`CC Delta` at rest |
| 5/9 TEMPERATURE | dial the ambient temperature, press APPLY | adjusts `Ext Temp Offset` (rejects diffs > 12 C; that is a wiring problem, not an offset) |
| 6/9 PACK CONFIG | press APPLY | writes VOLTSEL (Pack Configuration MSB bit 3, external divider, mandatory for 4S), Number of Series Cells (4), Design Capacity (7800 mAh). Read-modify-write, already-correct bytes skipped. |
| 7/9 ENABLE IT | press ENABLE | Control() `IT_ENABLE` (0x0021). **One-way** on the gauge ([QEN] cannot be cleared); run it only after the electrical calibration. |
| 8/9 LEARNING | run the learning cycle (full charge, rest 2 h, discharge C/5 to term voltage, rest 5 h) | passive live monitor: Update Status (0x04 → 0x05 Qmax → 0x06 Qmax+Ra), QEN/VOK, FC/REST flags, average current, and a next-action hint |
| 9/9 REVIEW | nothing, done | DF readout (gain, divider, offsets, Update Status). Values are permanent in the gauge; optionally note them down as a backup for a future gauge replacement. |

Guards baked in:

- Every write happens on an explicit APPLY/SAVE, browsing never
  touches the flash.
- Entered values implying a correction > **±15%** are rejected
  (`CAL_RANGE`): that is a hardware bug or a typo, not calibration.
- The current-step write is deferred until after the load is removed,
  so the DF write happens with the pack at rest.

## MCU self-draw trap (offset step)

While the firmware runs, the MCU's own supply current (~tens of mA)
flows through the battery shunt: an offset calibrated in that state
would hide real discharge current forever. Hence the SWD-power
instruction. If external power is impossible, skip the offset step and
keep the factory offsets, a wrong offset is worse than none.

## Testing without hardware

The emulator models the calibration path end to end
(`firmware/emulator/src/dev_bq34z100.c`): the DF calibration block is
live (reported V/I/T are distorted by the stored divider/gain/offset,
seeded with deliberate errors at attach), and the internal offset
routines run with realistic `CCA`/`BCA` timing. A correct wizard run
visibly converges the readings; every DF write shows in the log as
`data-flash write: subclass 104`.

Note for scripted runs: the UI's double-click arbiter holds single
clicks for 400 ms, leave ≥600 ms between a press and the next
rotation or the rotation lands first and moves the selection.

## What calibration does NOT cover

**ChemID selection**: the chemistry profile is a proprietary data block
distributed only through bqStudio's chemistry database, the wizard
cannot conjure it. Program it once via bqStudio (or accept the factory
default profile with degraded SoC accuracy); once written, the chem DF
block can be exported and added to the `provisioning.c` patch list like
everything else. The learning cycle itself needs hours and an external
load, the wizard monitors it (step 8/9) but cannot run it. See the
"golden image" section of
[Boot_and_Provisioning.md](Boot_and_Provisioning.md). Order matters:

```
electrical calibration -> static params -> ChemID -> IT enable
-> learning cycle -> export golden image into provisioning.c
```

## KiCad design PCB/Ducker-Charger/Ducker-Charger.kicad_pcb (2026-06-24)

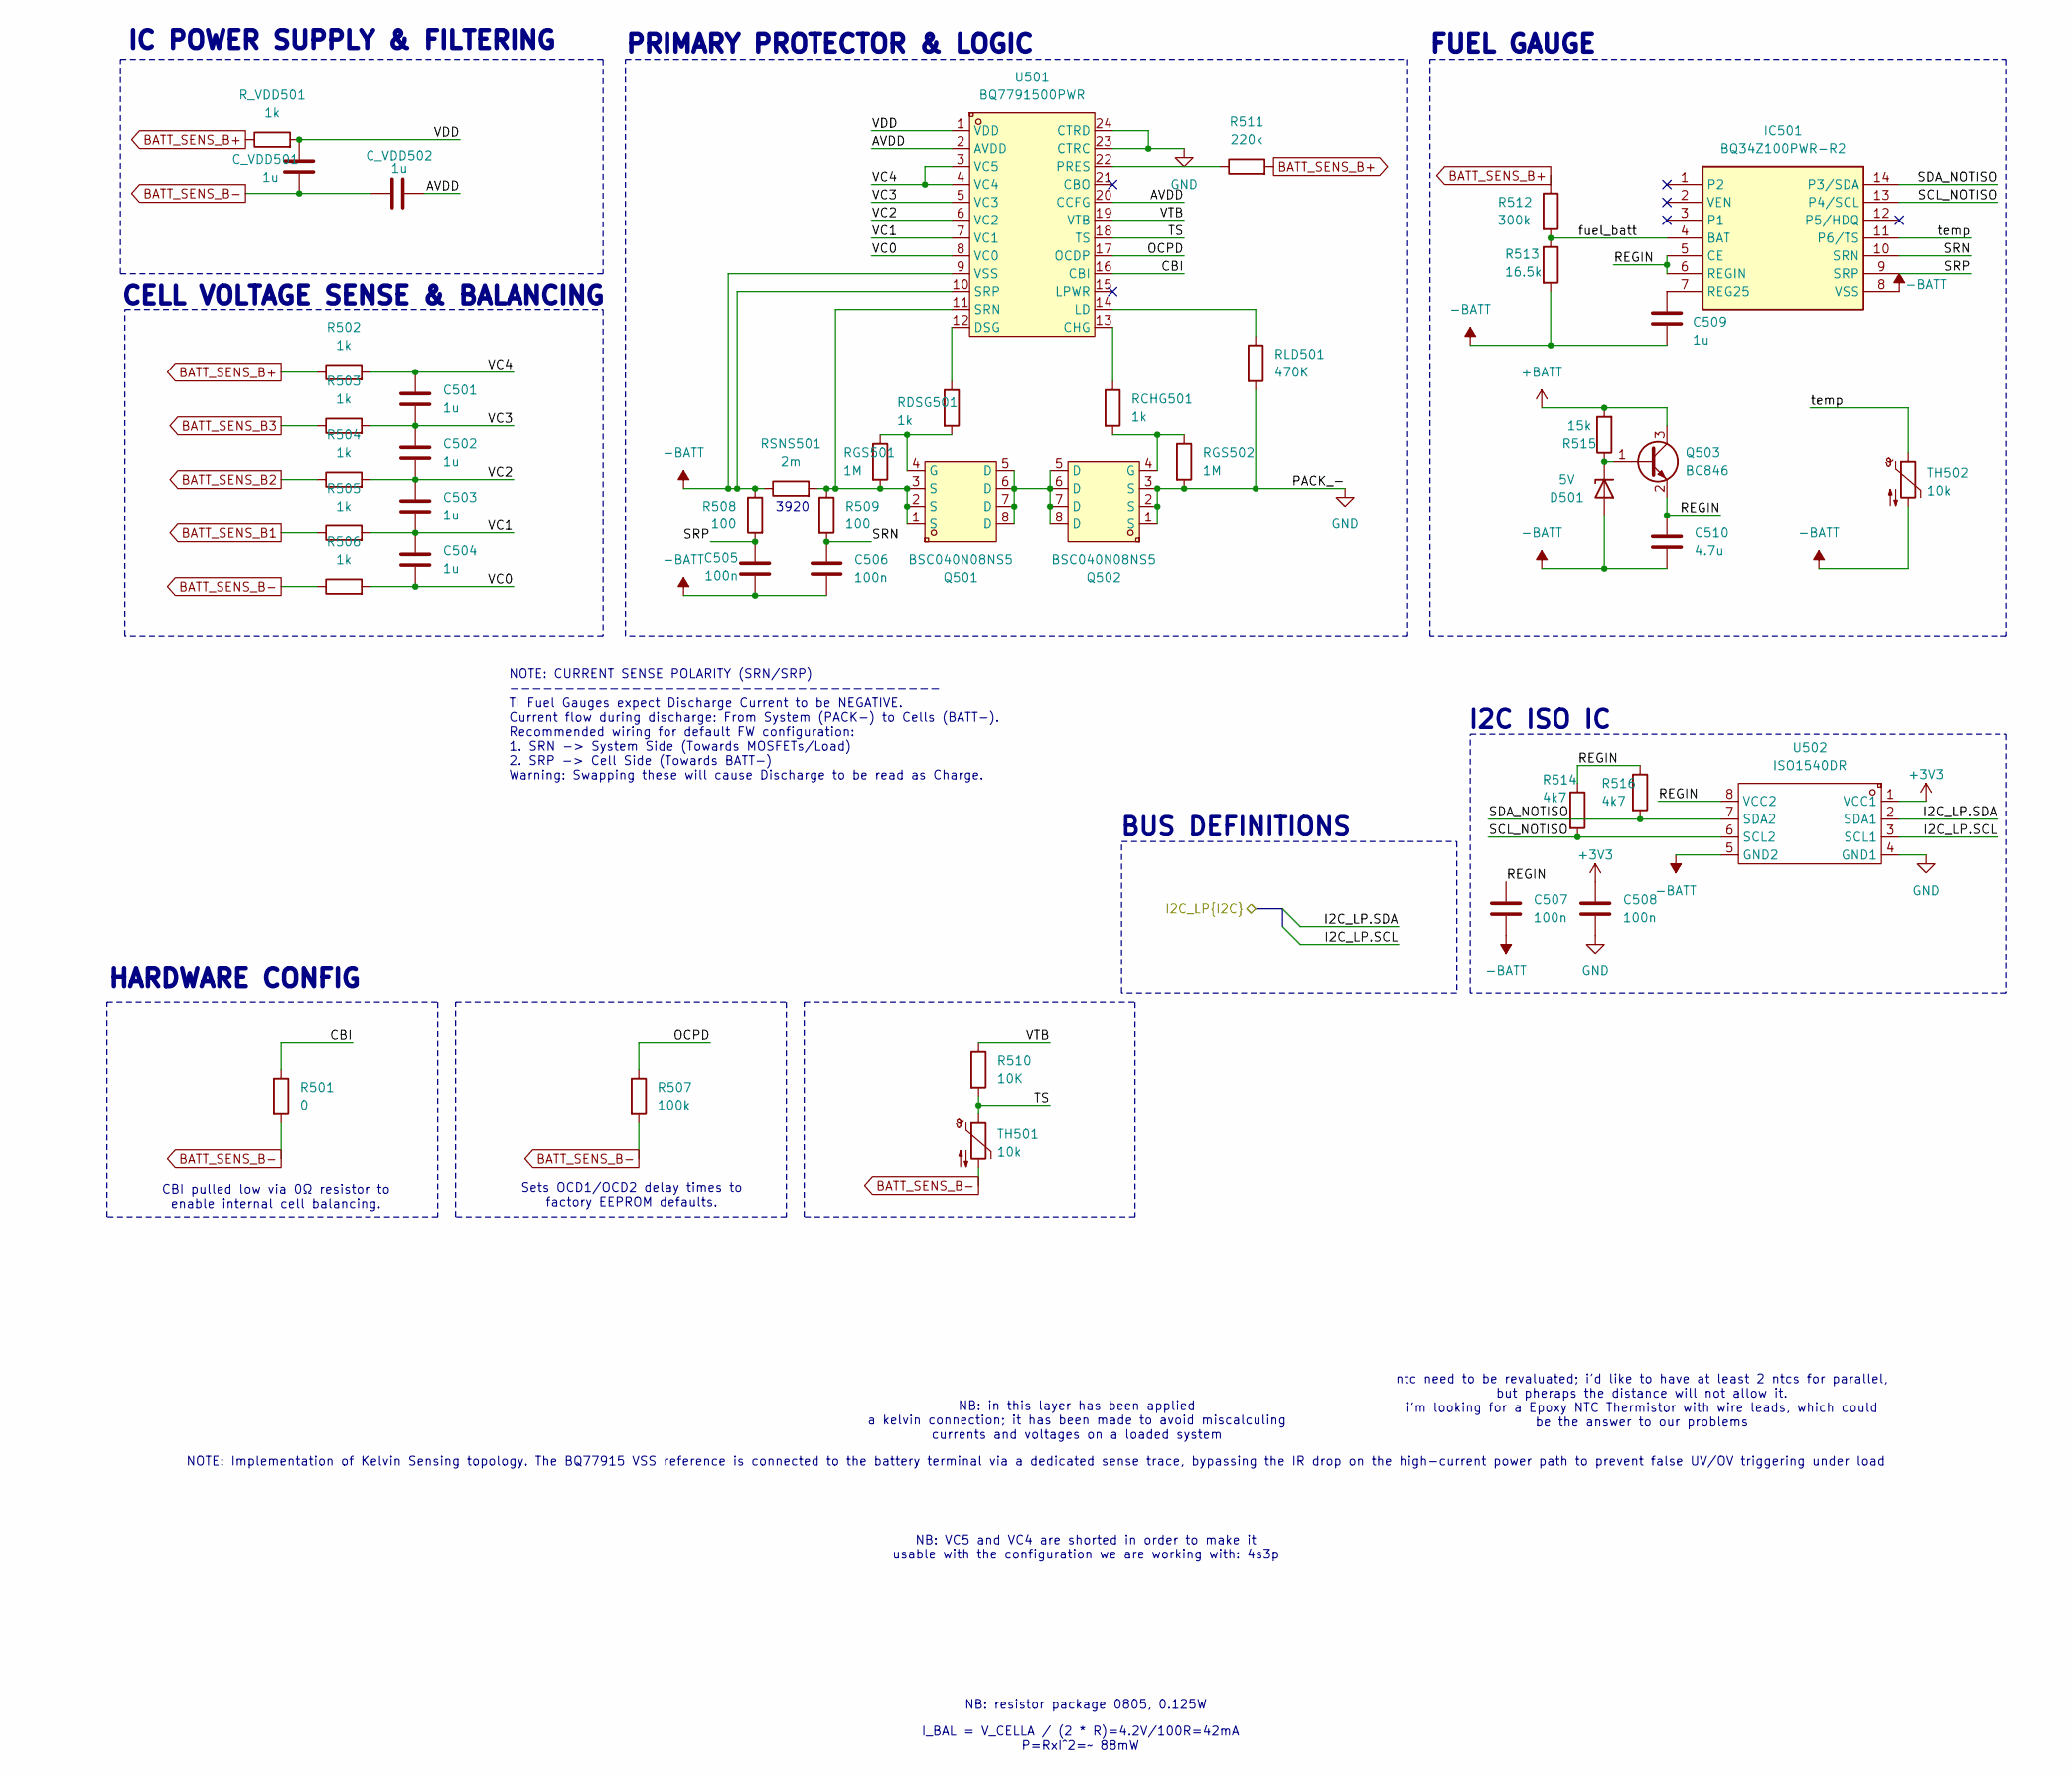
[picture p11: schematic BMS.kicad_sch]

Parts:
C501, C502, C503, C504, C509: 1u; C_0805_2012Metric
C505, C506, C507, C508: 100n; C_0603_1608Metric
C510: 4.7u; C_0805_2012Metric
C_VDD501, C_VDD502: 1u; C_0805_2012Metric
D501: 5V; D_SOD-123
IC501: BQ34Z100PWR-R2; SOP65P640X120-14N; Mouser Part Number 595-BQ34Z100PWR-R2
Q501, Q502: BSC040N08NS5; PG-TDSON-8_L5.9-W5.1-P1.27-LS6.2-BL; LCSC Part C534333
Q503: BC846; SOT-23
R501: 0; R_0603_1608Metric
R502, R503, R504, R505, R506: 1k; R_0603_1608Metric
R507: 100k; R_0603_1608Metric
R508, R509: 100; R_0603_1608Metric
R510: 10K; R_0603_1608Metric
R511: 220k; R_0603_1608Metric
R512: 300k; R_0603_1608Metric
R513: 16.5k; R_0603_1608Metric
R514, R516: 4k7; R_0603_1608Metric
R515: 15k; R_0603_1608Metric
RCHG501: 1k; R_0603_1608Metric
RDSG501: 1k; R_0603_1608Metric
RGS501, RGS502: 1M; R_0603_1608Metric
RLD501: 470K; R_0603_1608Metric
RSNS501: 2m; R3920; lcsc name Milliohm HoJLR2512-3W-5mR-1%
R_VDD501: 1k; R_0603_1608Metric
TH501, TH502: 10k; R_0603_1608Metric
U501: BQ7791500PWR; TSSOP-24_L7.8-W4.4-P0.65-LS6.4-BL; LCSC Part C2876946
U502: ISO1540DR; SOIC-8_L4.9-W3.9-P1.27-LS6.0-BL; LCSC Part C179739

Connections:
+3V3: C508.1, U502.1 (VCC1); also elsewhere on the board
+BATT: Q503.3 (C), R515.2; also elsewhere on the board
-BATT: C505.2, C506.2, C507.2, C509.2, C510.2, D501.2 (A), IC501.8 (VSS), R508.1, R513.2, RSNS501.1, TH502.2, U501.9 (VSS), U501.10 (SRP), U502.5 (GND2); also elsewhere on the board
/BMS/AVDD: C_VDD502.2, U501.2 (AVDD), U501.20 (CCFG)
/BMS/CBI: R501.1, U501.16 (CBI)
/BMS/I2C_LP.SCL: U502.3 (SCL1); also elsewhere on the board
/BMS/I2C_LP.SDA: U502.2 (SDA1); also elsewhere on the board
/BMS/OCPD: R507.1, U501.17 (OCDP)
/BMS/REGIN: C507.1, C510.1, IC501.5 (CE), IC501.6 (REGIN), Q503.2 (E), R514.1, R516.1, U502.8 (VCC2)
/BMS/SCL_NOTISO: IC501.13 (P4/SCL), R514.2, U502.6 (SCL2)
/BMS/SDA_NOTISO: IC501.14 (P3/SDA), R516.2, U502.7 (SDA2)
/BMS/SRN: C506.1, IC501.10 (SRN), R509.2
/BMS/SRP: C505.1, IC501.9 (SRP), R508.2
/BMS/TS: R510.2, TH501.1, U501.18 (TS)
/BMS/VC0: C504.2, R506.2, U501.8 (VC0)
/BMS/VC1: C503.2, C504.1, R505.2, U501.7 (VC1)
/BMS/VC2: C502.2, C503.1, R504.2, U501.6 (VC2)
/BMS/VC3: C501.2, C502.1, R503.2, U501.5 (VC3)
/BMS/VC4: C501.1, R502.2, U501.3 (VC5), U501.4 (VC4)
/BMS/VDD: C_VDD501.1, R_VDD501.2, U501.1 (VDD)
/BMS/VTB: R510.1, U501.19 (VTB)
/BMS/fuel_batt: IC501.4 (BAT), R512.2, R513.1
/BMS/temp: IC501.11 (P6/TS), TH502.1
BATT_SENS_B1: R505.1; also elsewhere on the board
BATT_SENS_B2: R504.1; also elsewhere on the board
BATT_SENS_B3: R503.1; also elsewhere on the board
BATT_SENS_B+: R502.1, R511.2, R512.1, R_VDD501.1; also elsewhere on the board
BATT_SENS_B-: C_VDD501.2, C_VDD502.1, R501.2, R506.1, R507.2, TH501.2; also elsewhere on the board
GND: C508.2, Q502.1 (S), Q502.2 (S), Q502.3 (S), RGS502.2, RLD501.2, U501.23 (CTRC), U501.24 (CTRD), U502.4 (GND1); also elsewhere on the board
unnamed: D501.1 (K), Q503.1 (B), R515.1
unnamed: C509.1, IC501.7 (REG25)
unnamed: Q501.5 (D), Q501.6 (D), Q501.7 (D), Q501.8 (D), Q502.5 (D), Q502.6 (D), Q502.7 (D), Q502.8 (D)
unnamed: Q501.4 (G), RDSG501.2, RGS501.1
unnamed: Q502.4 (G), RCHG501.2, RGS502.1
unnamed: RCHG501.1, U501.13 (CHG)
unnamed: RDSG501.1, U501.12 (DSG)
unnamed: RLD501.1, U501.14 (LD)
unnamed: R511.1, U501.22 (PRES)
unnamed: Q501.1 (S), Q501.2 (S), Q501.3 (S), R509.1, RGS501.2, RSNS501.2, U501.11 (SRN)

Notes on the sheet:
NB: resistor package 0805, 0.125W
I2C ISO IC
NOTE: Implementation of Kelvin Sensing topology. The BQ77915 VSS reference is connected to the battery terminal via a dedicated sense trace, bypassing the IR drop on the high-current power path to prevent false UV/OV triggering under load
FUEL GAUGE
I_BAL = V_CELLA / (2 * R)=4.2V/100R=42mA P=RxI^2=~ 88mW
NOTE: CURRENT SENSE POLARITY (SRN/SRP) --------------------------------------- TI Fuel Gauges expect Discharge Current to be NEGATIVE. Current flow during discharge: From System (PACK-) to Cells (BATT-). Recommended wiring for default FW configuration: 1. SRN -> System Side (Towards MOSFETs/Load) 2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
IC POWER SUPPLY & FILTERING
ntc need to be revaluated; i'd like to have at least 2 ntcs for parallel, but pheraps the distance will not allow it. i'm looking for a Epoxy NTC Thermistor with wire leads, which could be the answer to our problems
NB: in this layer has been applied a kelvin connection; it has been made to avoid miscalculing currents and voltages on a loaded system
Sets OCD1/OCD2 delay times to factory EEPROM defaults.
HARDWARE CONFIG
CELL VOLTAGE SENSE & BALANCING
BUS DEFINITIONS
NB: VC5 and VC4 are shorted in order to make it usable with the configuration we are working with: 4s3p
3920
CBI pulled low via 0Ω resistor to enable internal cell balancing.
PRIMARY PROTECTOR & LOGIC

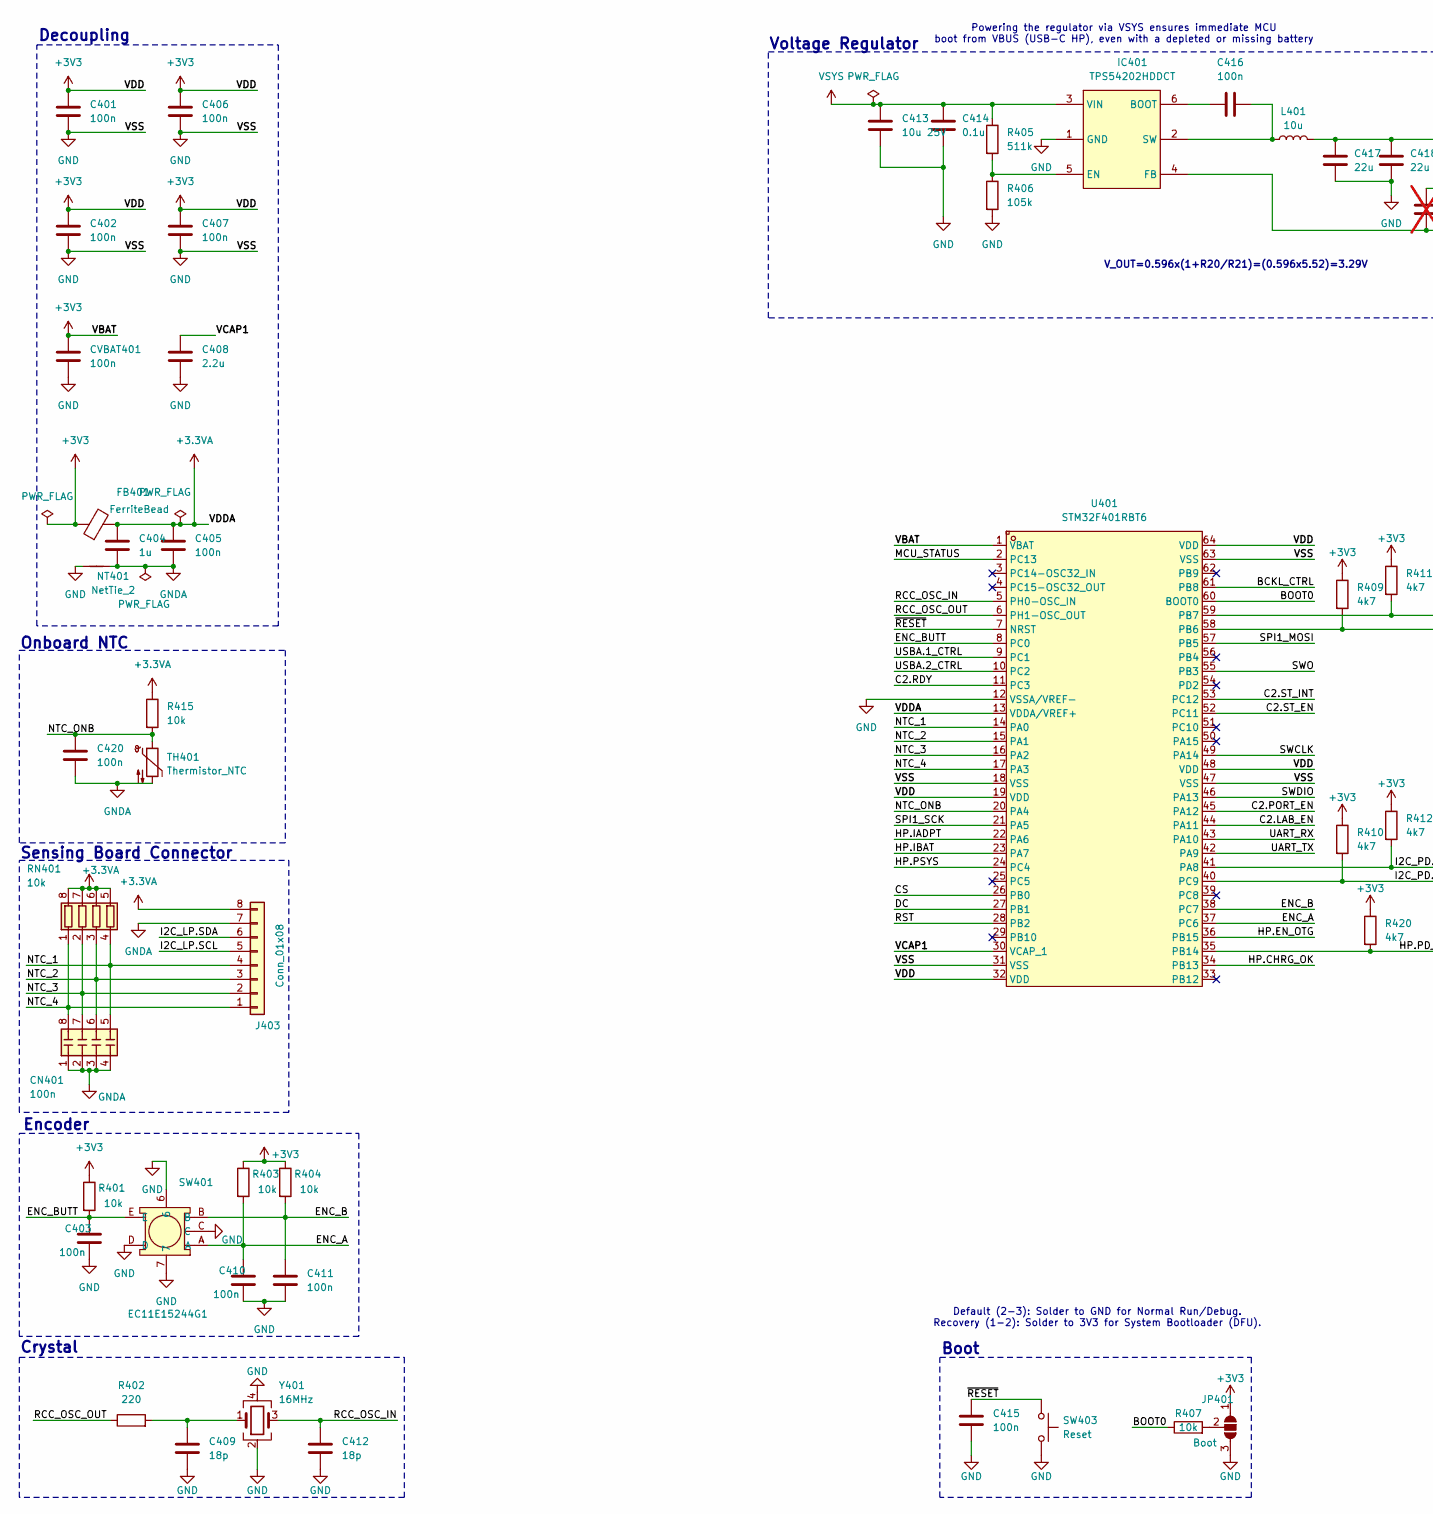
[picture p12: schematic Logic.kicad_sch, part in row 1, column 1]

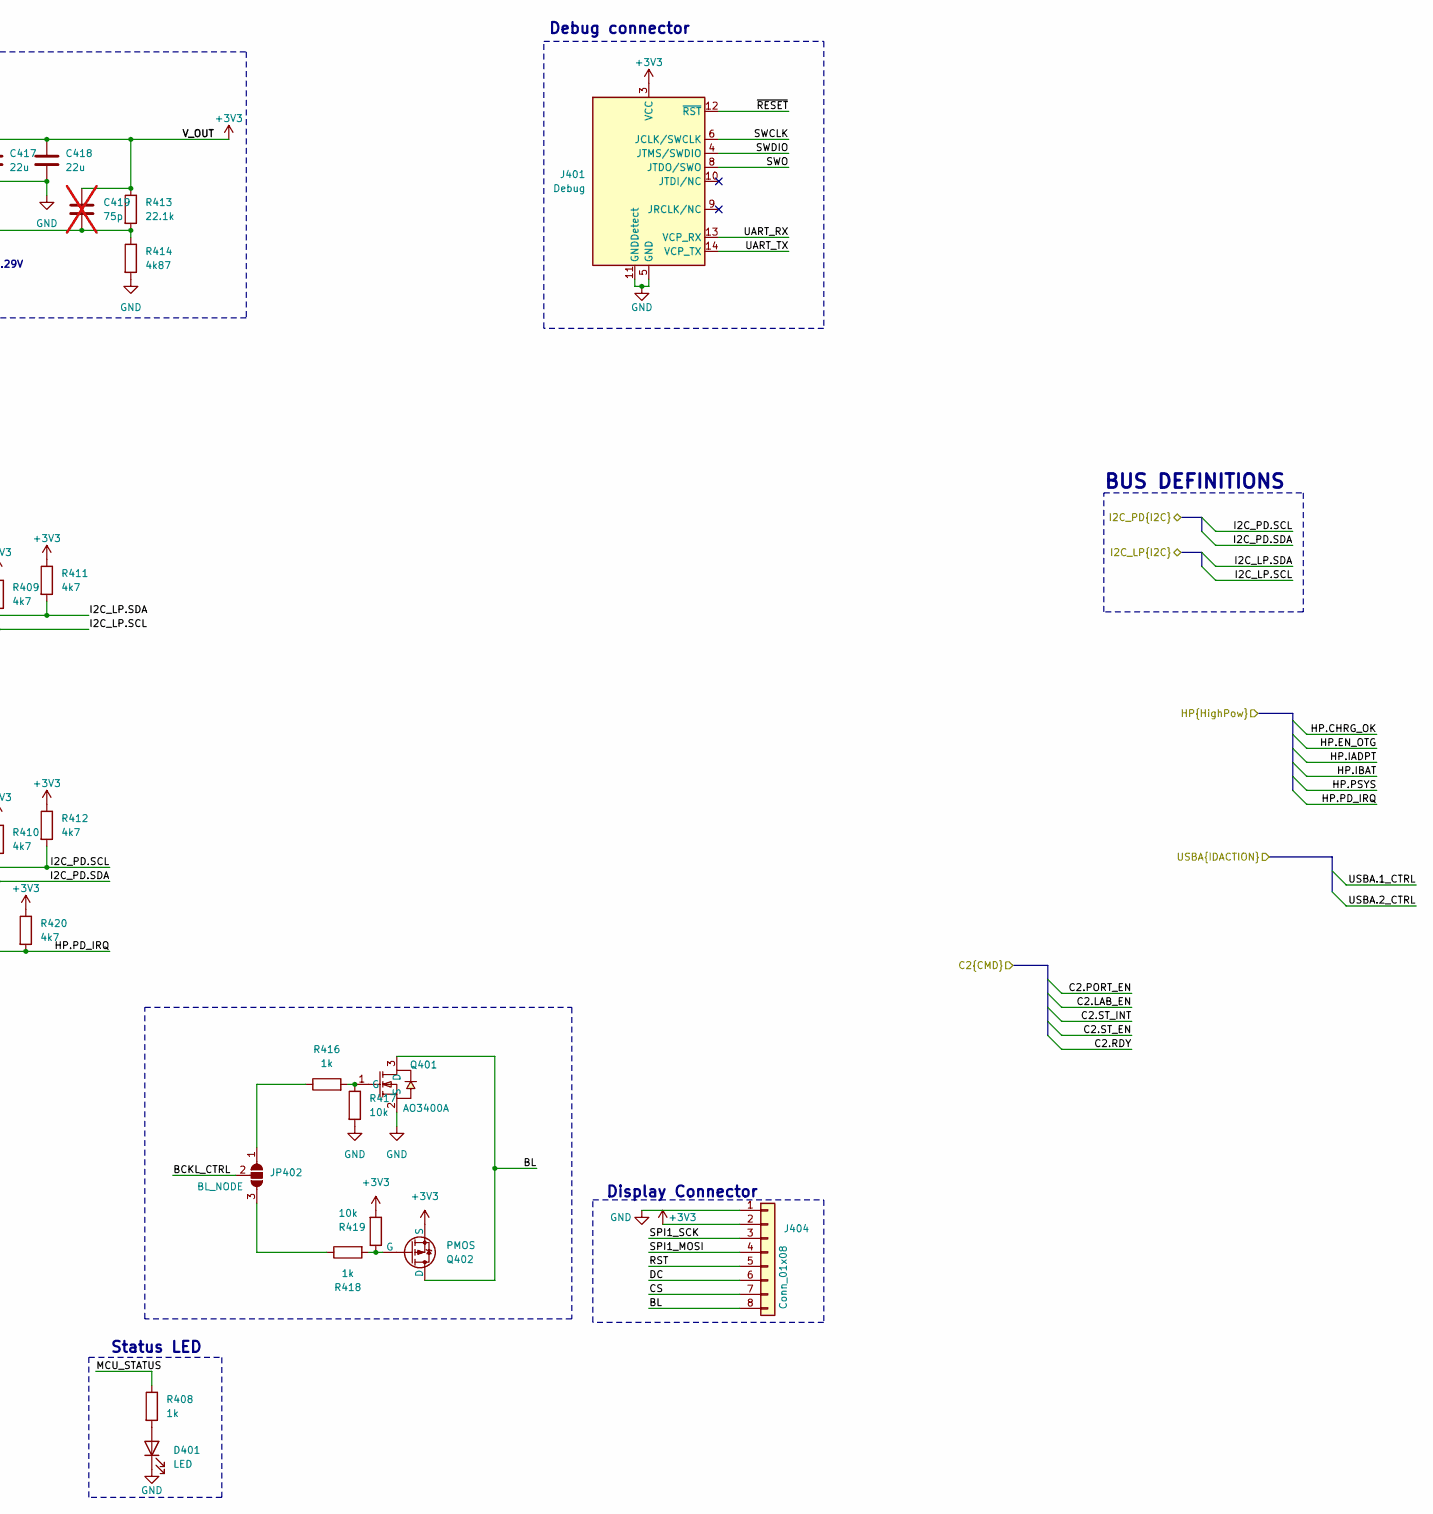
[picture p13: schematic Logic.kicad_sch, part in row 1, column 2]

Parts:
C401, C402, C403, C405, C406, C407, C410, C411, C415, C420: 100n; C_0603_1608Metric
C404: 1u; C_0805_2012Metric
C408: 2.2u; C_0805_2012Metric
C409, C412: 18p; C_0603_1608Metric
C413: 10u 25V; C_1206_3216Metric
C414: 0.1u; C_0805_2012Metric
C416: 100n; C_0805_2012Metric
C417, C418: 22u; C_0805_2012Metric
C419: 75p; C_0805_2012Metric; not fitted
CN401: 100n; R_Array_Concave_4x0603
CVBAT401: 100n; R_0603_1608Metric
D401: LED; LED_0603_1608Metric
FB401: FerriteBead; L_0603_1608Metric
IC401: TPS54202HDDCT; SOT95P280X110-6N; Mouser Part Number 595-TPS54202HDDCT
J401: Debug; SAMTEC_FTSH-107-01-L-DV-K-TR
J403: Conn_01x08; Molex_200528-0080_1x08-1MP_P1.00mm_Horizontal
J404: Conn_01x08; JST_EH_B8B-EH-A_1x08_P2.50mm_Vertical
JP401: Boot; SolderJumper-3_P1.3mm_Open_RoundedPad1.0x1.5mm
JP402: BL_NODE; SolderJumper-3_P1.3mm_Open_RoundedPad1.0x1.5mm
L401: 10u; L_6.3x6.3_H3
NT401: NetTie_2; NetTie-2_SMD_Pad0.5mm
Q401: AO3400A; SOT-23-3_L2.9-W1.3-P1.90-LS2.4-BR; LCSC Part C20917
Q402: PMOS; SOT-23-3_L2.9-W1.3-P1.90-LS2.4-BR
R401, R403, R404, R407, R415, R417, R419: 10k; R_0603_1608Metric
R402: 220; R_0603_1608Metric
R405: 511k; R_0603_1608Metric
R406: 105k; R_0603_1608Metric
R408, R416, R418: 1k; R_0603_1608Metric
R409, R410, R411, R412, R420: 4k7; R_0603_1608Metric
R413: 22.1k; R_0603_1608Metric
R414: 4k87; R_0603_1608Metric
RN401: 10k; R_Array_Convex_4x0603
SW401: EC11E15244G1; SW-TH_EC11E15244G1; LCSC Part C370970
SW403: Reset; SW_SPST_FSMSM
TH401: Thermistor_NTC; R_0603_1608Metric
U401: STM32F401RBT6; LQFP-64_L10.0-W10.0-P0.50-LS12.0-BL; LCSC Part C75278
Y401: 16MHz; Crystal_SMD_EuroQuartz_MT-4Pin_3.2x2.5mm

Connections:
+3.3VA: C404.1, C405.1, FB401.2, J403.8, R415.1, RN401.5 (R4.2), RN401.6 (R3.2), RN401.7 (R2.2), RN401.8 (R1.2), U401.13 (VDDA/VREF+)
+3V3: C401.1, C402.1, C406.1, C407.1, C417.1, C418.1, C419.2, CVBAT401.1, FB401.1, J401.3 (VCC), J404.2, JP401.1 (A), L401.2, Q402.3 (S), R401.1, R403.1, R404.1, R409.1, R410.1, R411.1, R412.1, R413.1, R419.2, R420.1, U401.1 (VBAT), U401.19 (VDD), U401.32 (VDD), U401.48 (VDD), U401.64 (VDD); also elsewhere on the board
/BMS/I2C_LP.SCL: J403.5, R409.2, U401.58 (PB6); also elsewhere on the board
/BMS/I2C_LP.SDA: J403.6, R411.2, U401.59 (PB7); also elsewhere on the board
/High_pow/HP.CHRG_OK: U401.34 (PB13); also elsewhere on the board
/High_pow/HP.EN_OTG: U401.36 (PB15); also elsewhere on the board
/High_pow/HP.IADPT: U401.22 (PA6); also elsewhere on the board
/High_pow/HP.IBAT: U401.23 (PA7); also elsewhere on the board
/High_pow/HP.PD_IRQ: R420.2, U401.35 (PB14); also elsewhere on the board
/High_pow/HP.PSYS: U401.24 (PC4); also elsewhere on the board
/High_pow/I2C_PD.SCL: R412.2, U401.41 (PA8); also elsewhere on the board
/High_pow/I2C_PD.SDA: R410.2, U401.40 (PC9); also elsewhere on the board
/Logic/BCKL_CTRL: JP402.2 (C), U401.61 (PB8)
/Logic/BL: J404.8, Q401.3 (D), Q402.1 (D)
/Logic/BOOT0: R407.1, U401.60 (BOOT0)
/Logic/C2.LAB_EN: U401.44 (PA11); also elsewhere on the board
/Logic/C2.PORT_EN: U401.45 (PA12); also elsewhere on the board
/Logic/C2.RDY: U401.11 (PC3); also elsewhere on the board
/Logic/C2.ST_EN: U401.52 (PC11); also elsewhere on the board
/Logic/C2.ST_INT: U401.53 (PC12); also elsewhere on the board
/Logic/CS: J404.7, U401.26 (PB0)
/Logic/DC: J404.6, U401.27 (PB1)
/Logic/ENC_A: C410.1, R403.2, SW401.A, U401.37 (PC6)
/Logic/ENC_B: C411.1, R404.2, SW401.B, U401.38 (PC7)
/Logic/ENC_BUTT: C403.1, R401.2, SW401.E, U401.8 (PC0)
/Logic/MCU_STATUS: R408.1, U401.2 (PC13)
/Logic/NTC_1: CN401.5 (R4.2), J403.4, RN401.4 (R4.1), U401.14 (PA0)
/Logic/NTC_2: CN401.6 (R3.2), J403.3, RN401.3 (R3.1), U401.15 (PA1)
/Logic/NTC_3: CN401.7 (R2.2), J403.2, RN401.2 (R2.1), U401.16 (PA2)
/Logic/NTC_4: CN401.8 (R1.2), J403.1, RN401.1 (R1.1), U401.17 (PA3)
/Logic/NTC_ONB: C420.1, R415.2, TH401.1, U401.20 (PA4)
/Logic/RCC_OSC_IN: C412.1, U401.5 (PH0-OSC_IN), Y401.3
/Logic/RCC_OSC_OUT: R402.1, U401.6 (PH1-OSC_OUT)
/Logic/RST: J404.5, U401.28 (PB2)
/Logic/SPI1_MOSI: J404.4, U401.57 (PB5)
/Logic/SPI1_SCK: J404.3, U401.21 (PA5)
/Logic/SWCLK: J401.6 (JCLK/SWCLK), U401.49 (PA14)
/Logic/SWDIO: J401.4 (JTMS/SWDIO), U401.46 (PA13)
/Logic/SWO: J401.8 (JTDO/SWO), U401.55 (PB3)
/Logic/UART_RX: J401.13 (VCP_RX), U401.43 (PA10)
/Logic/UART_TX: J401.14 (VCP_TX), U401.42 (PA9)
/Logic/USBA.1_CTRL: U401.9 (PC1); also elsewhere on the board
/Logic/USBA.2_CTRL: U401.10 (PC2); also elsewhere on the board
/Logic/VCAP1: C408.1, U401.30 (VCAP_1)
/Logic/~RESET: C415.1, J401.12 (~RST), SW403.1, U401.7 (NRST)
GND: C401.2, C402.2, C403.2, C406.2, C407.2, C408.2, C409.2, C410.2, C411.2, C412.2, C413.2, C414.2, C415.2, C417.2, C418.2, CVBAT401.2, D401.1 (K), IC401.1 (GND), J401.5 (GND), J401.7 (GND), J401.11 (GNDDetect), J404.1, JP401.3 (B), NT401.1, Q401.2 (S), R406.2, R414.2, R417.2, SW401.6, SW401.7, SW401.C, SW401.D, SW403.2, U401.12 (VSSA/VREF-), U401.18 (VSS), U401.31 (VSS), U401.47 (VSS), U401.63 (VSS), Y401.2, Y401.4; also elsewhere on the board
GNDA: C404.2, C405.2, C420.2, CN401.1 (R1.1), CN401.2 (R2.1), CN401.3 (R3.1), CN401.4 (R4.1), J403.7, NT401.2, TH401.2
unnamed: C409.1, R402.2, Y401.1
unnamed: D401.2 (A), R408.2
unnamed: C416.1, IC401.6 (BOOT)
unnamed: IC401.5 (EN), R405.2, R406.1
unnamed: C419.1, IC401.4 (FB), R413.2, R414.1
unnamed: C416.2, IC401.2 (SW), L401.1
unnamed: JP401.2 (C), R407.2
unnamed: JP402.1 (A), R416.1
unnamed: JP402.3 (B), R418.1
unnamed: Q401.1 (G), R416.2, R417.1
unnamed: Q402.2 (G), R418.2, R419.1
VSYS: C413.1, C414.1, IC401.3 (VIN), R405.1; also elsewhere on the board

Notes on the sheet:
Status LED
Crystal
Boot
V_OUT=0.596x(1+R20/R21)=(0.596x5.52)=3.29V
Sensing Board Connector
Onboard NTC
Voltage Regulator
Encoder
Debug connector
Powering the regulator via VSYS ensures immediate MCU boot from VBUS (USB-C HP), even with a depleted or missing battery
BUS DEFINITIONS
Default (2-3): Solder to GND for Normal Run/Debug. Recovery (1-2): Solder to 3V3 for System Bootloader (DFU).
Decoupling
Display Connector

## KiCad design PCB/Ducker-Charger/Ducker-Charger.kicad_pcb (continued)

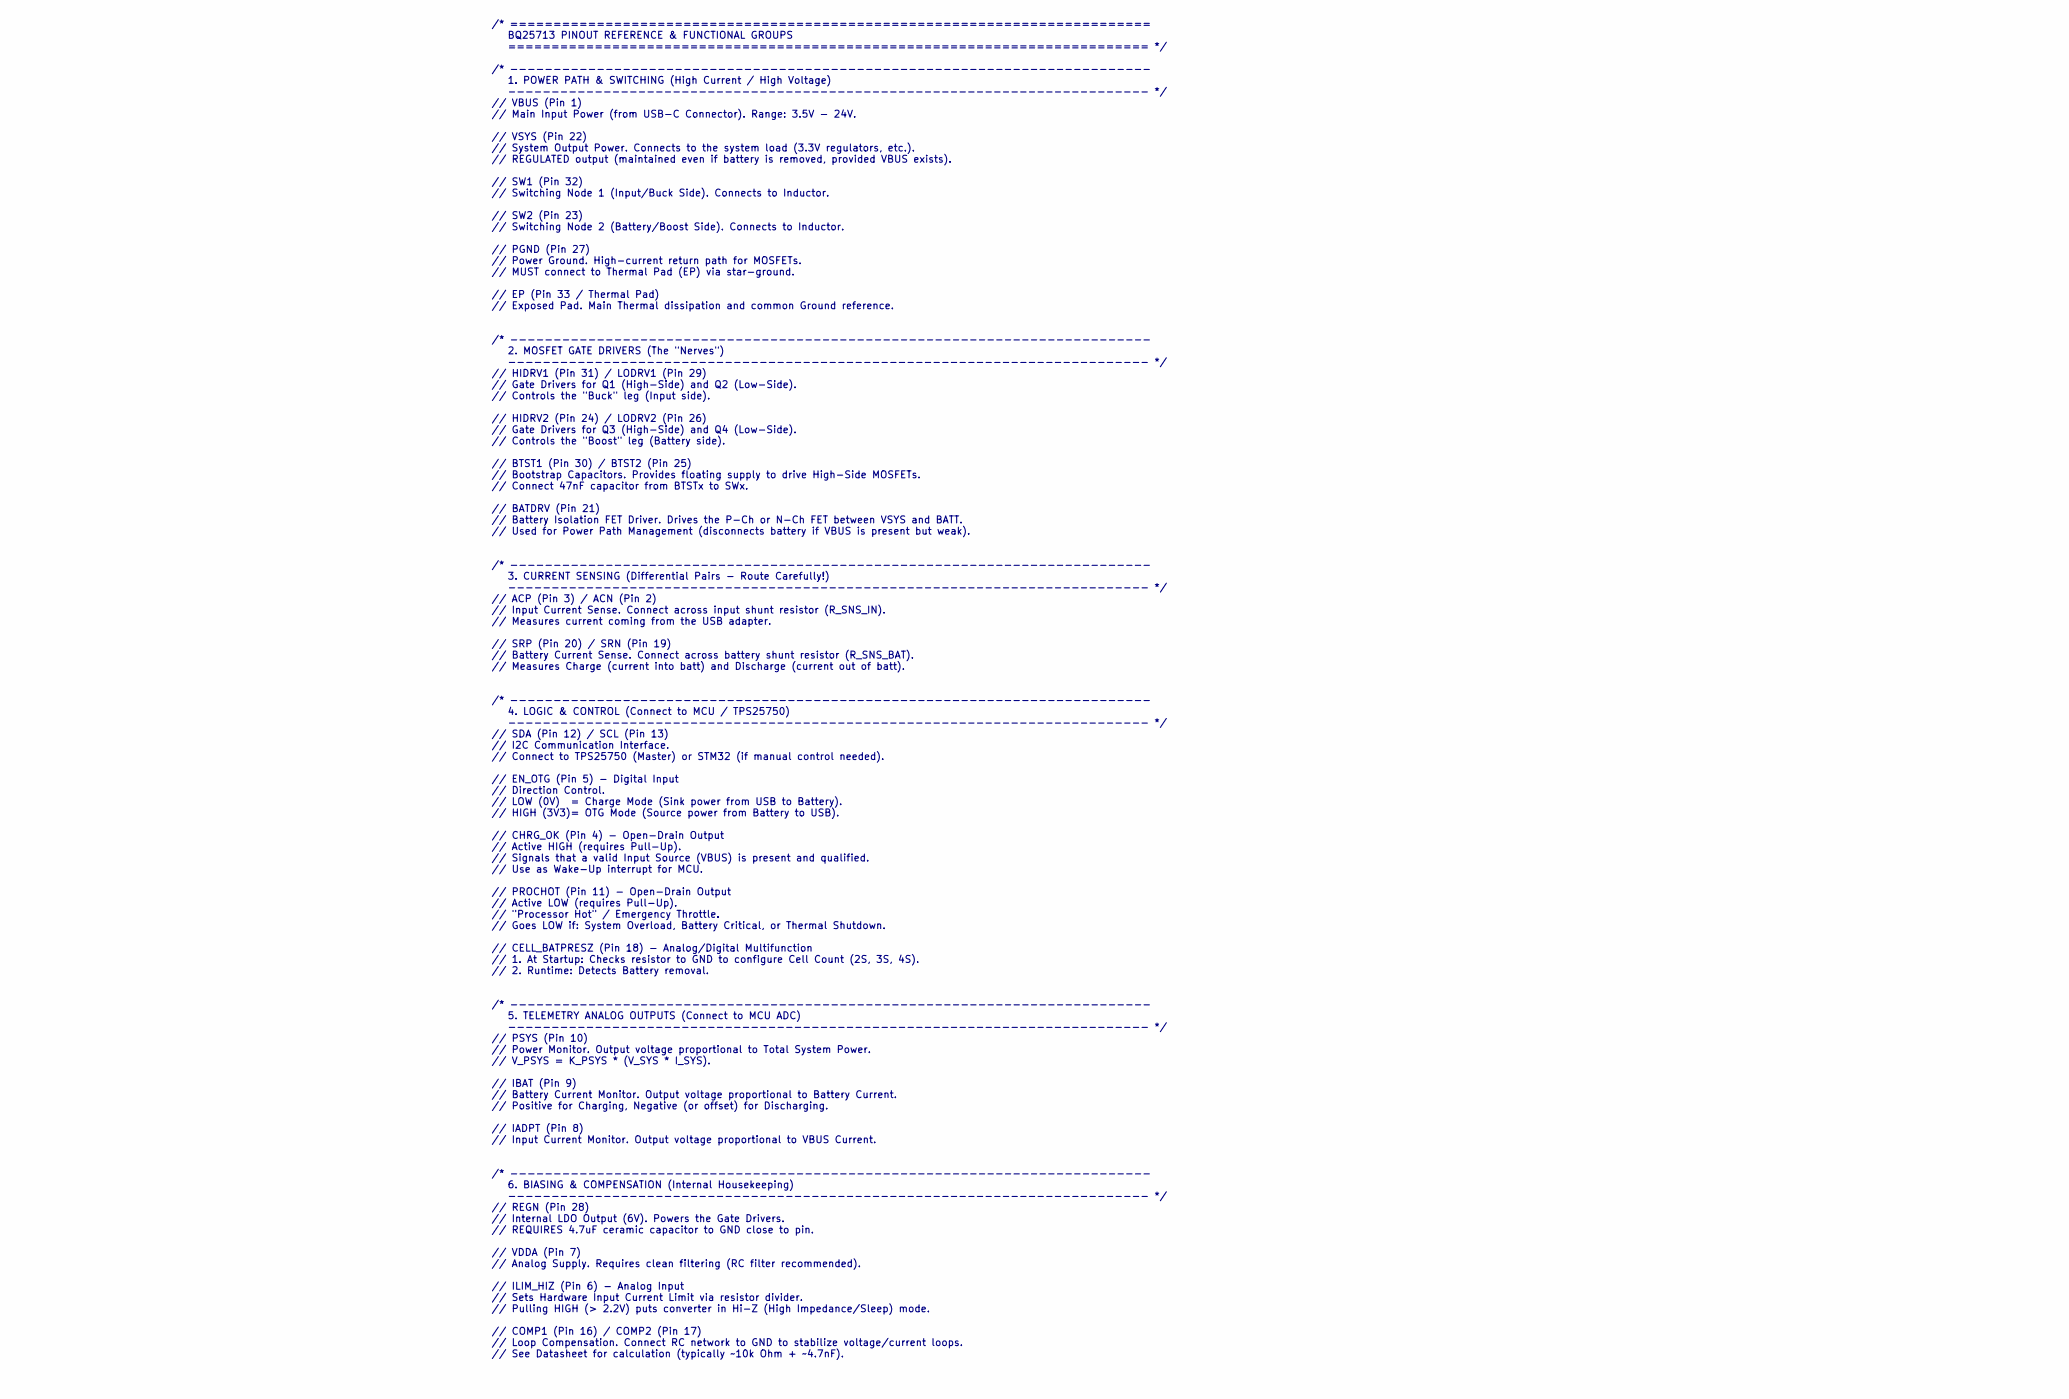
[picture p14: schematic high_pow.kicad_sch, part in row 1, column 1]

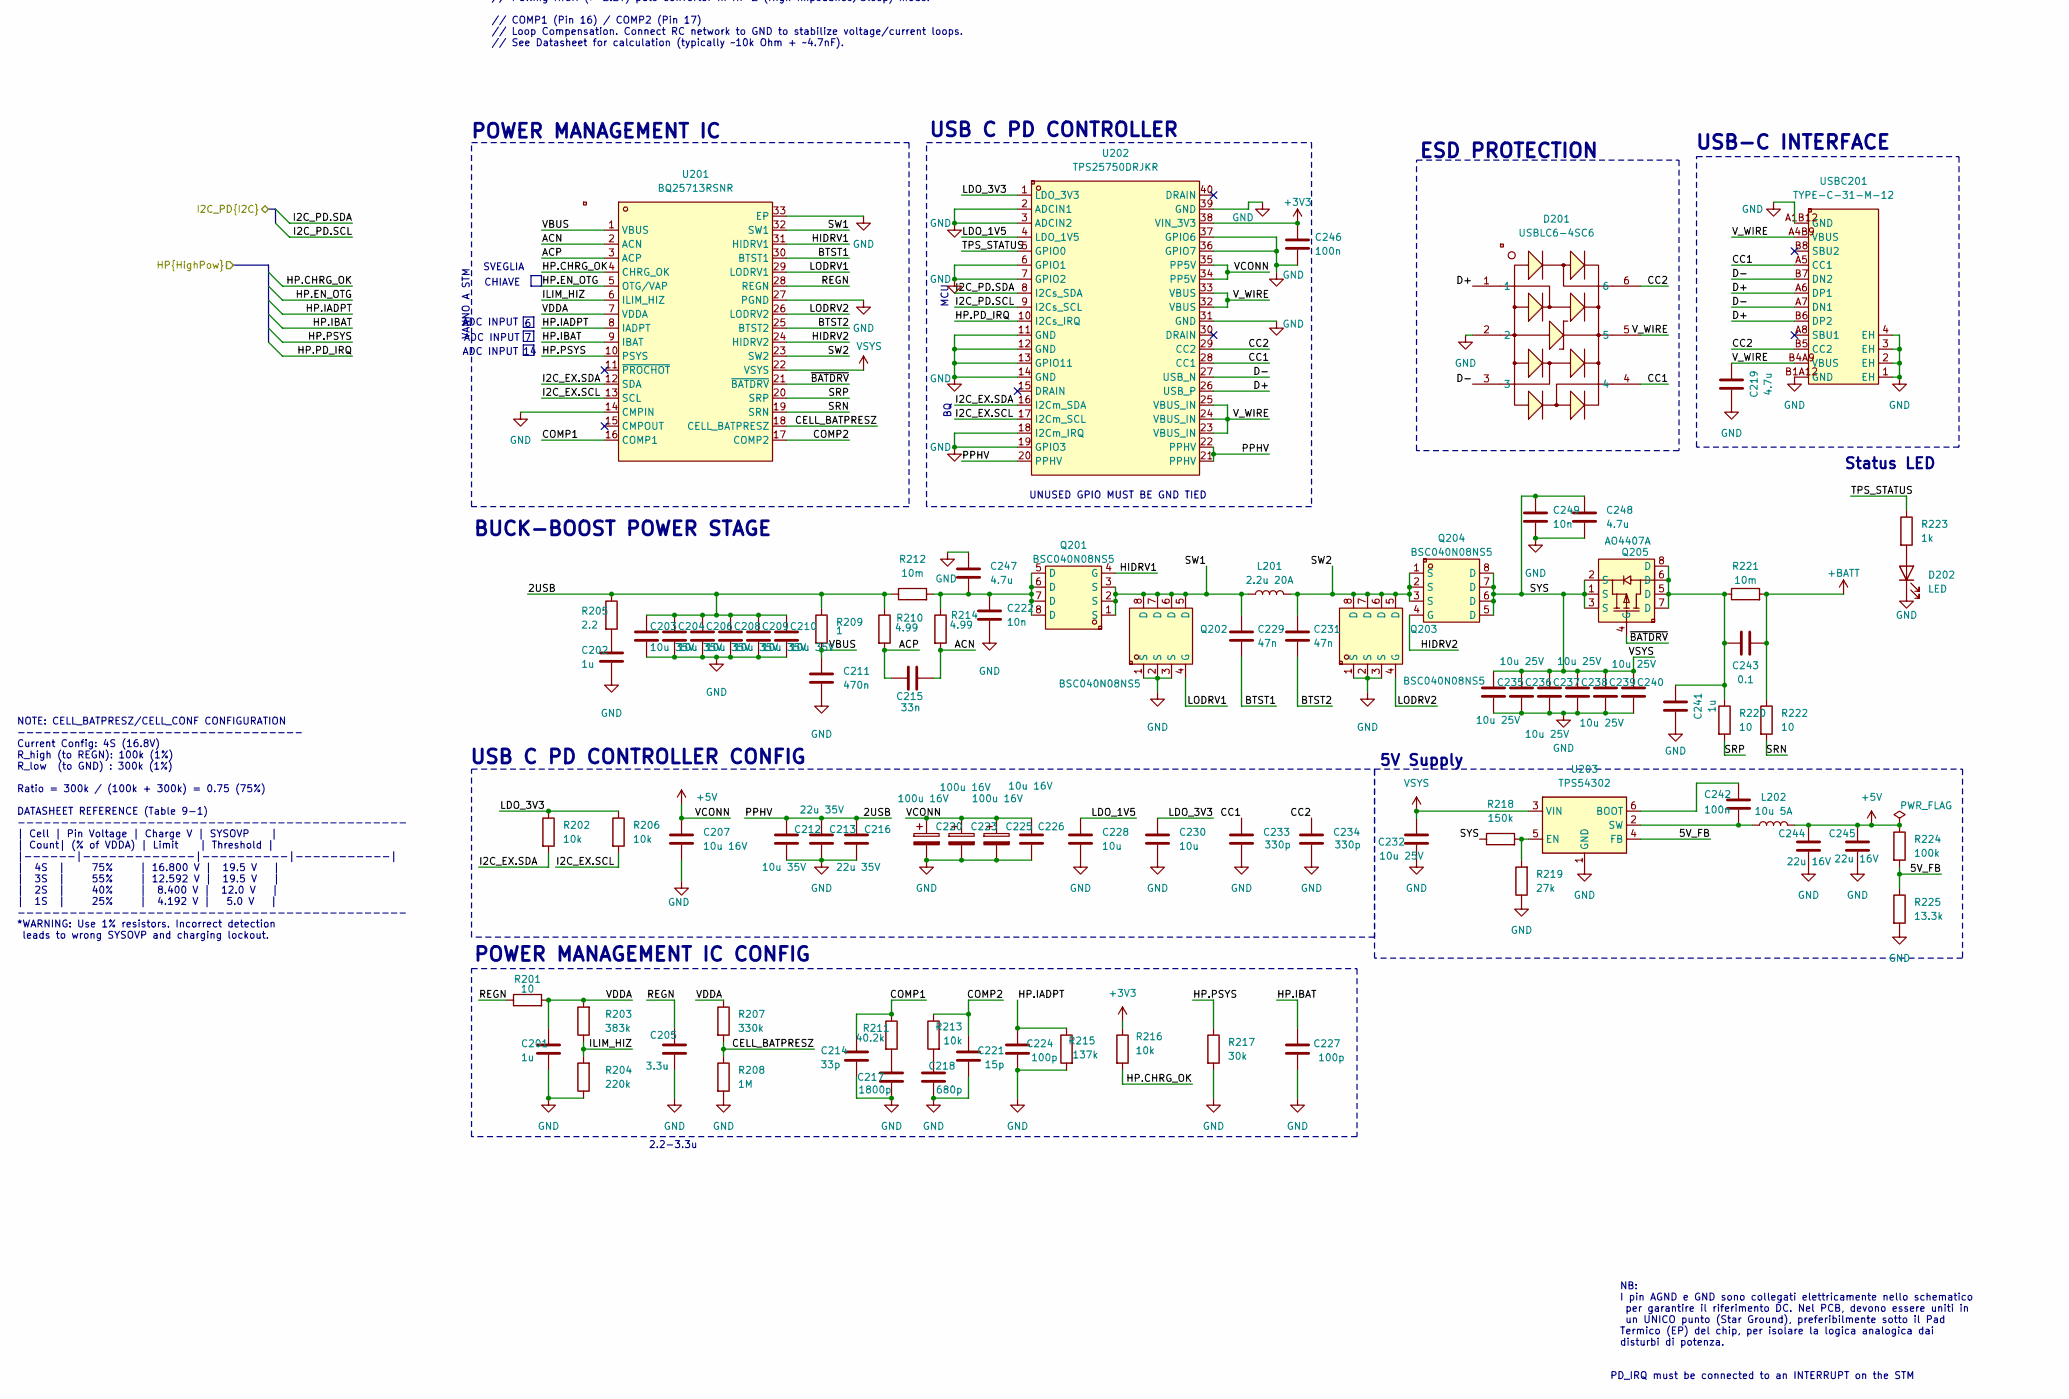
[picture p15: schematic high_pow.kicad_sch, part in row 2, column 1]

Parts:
C201, C202, C241: 1u; C_0805_2012Metric
C203, C204, C206, C208, C209, C210, C212: 10u 35V; C_1206_3216Metric
C205: 3.3u; C_0805_2012Metric
C207, C226: 10u 16V; C_0603_1608Metric
C211: 470n; C_0805_2012Metric
C213, C216: 22u 35V; C_1210_3225Metric
C214: 33p; C_0603_1608Metric
C215: 33n; C_0603_1608Metric
C217: 1800p; C_0603_1608Metric
C218: 680p; C_0603_1608Metric
C219, C247, C248: 4.7u; C_0805_2012Metric
C220, C223, C225: 100u 16V; C_1210_3225Metric
C221: 15p; C_0603_1608Metric
C222, C249: 10n; C_0603_1608Metric
C224, C227: 100p; C_0603_1608Metric
C228, C230: 10u; C_0805_2012Metric
C229, C231: 47n; C_0603_1608Metric
C232, C235, C236, C237, C238, C239, C240: 10u 25V; C_1206_3216Metric
C233, C234: 330p; C_0603_1608Metric
C242, C246: 100n; C_0603_1608Metric
C243: 0.1; C_0805_2012Metric
C244, C245: 22u 16V; C_0805_2012Metric
D201: USBLC6-4SC6; SOT-23-6_L2.9-W1.6-P0.95-LS2.8-BL; LCSC Part C111212
D202: LED; LED_0603_1608Metric
L201: 2.2u 20A; L_Chilisin_BMRF00131360
L202: 10u 5A; L_7.3x7.3_H4.5
Q201, Q202, Q203, Q204: BSC040N08NS5; PG-TDSON-8_L5.9-W5.1-P1.27-LS6.2-BL; LCSC Part C534333
Q205: AO4407A; SOIC-8_L4.9-W3.9-P1.27-LS6.0-BL; LCSC Part C16072
R201, R220, R222: 10; R_0603_1608Metric
R202, R206, R213, R216: 10k; R_0603_1608Metric
R203: 383k; R_0603_1608Metric
R204: 220k; R_0603_1608Metric
R205: 2.2; R_0603_1608Metric
R207: 330k; R_0603_1608Metric
R208: 1M; R_0603_1608Metric
R209: 1; R_0603_1608Metric
R210, R214: 4.99; R_0603_1608Metric
R211: 40.2k; R_0603_1608Metric
R212, R221: 10m; R3920
R215: 137k; R_0603_1608Metric
R217: 30k; R_0603_1608Metric
R218: 150k; R_0603_1608Metric
R219: 27k; R_0603_1608Metric
R223: 1k; R_0603_1608Metric
R224: 100k; R_0603_1608Metric
R225: 13.3k; R_0603_1608Metric
U201: BQ25713RSNR; QFN-32_L4.0-W4.0-P0.40-TL-EP2.8; LCSC Part C2878935
U202: TPS25750DRJKR; QFN-38_L6.0-W4.0-P0.40-TL-EP_RJK; LCSC Part C2868209
U203: TPS54302; SOT-23-6
USBC201: TYPE-C-31-M-12; USB-C_SMD-TYPE-C-31-M-12_1; LCSC Part C165948

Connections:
+3V3: C246.1, R216.1, U202.38 (VIN_3V3); also elsewhere on the board
+5V: C207.1, C220.1, C223.1, C225.1, C226.1, C244.1, C245.1, L202.2, R224.1, U202.34 (PP5V), U202.35 (PP5V); also elsewhere on the board
+BATT: C243.1, R221.2, R222.1; also elsewhere on the board
/High_pow/2USB: C203.1, C204.1, C206.1, C208.1, C209.1, C210.1, C212.1, C213.1, C216.1, R205.1, R209.1, R210.1, R212.1, U202.20 (PPHV), U202.21 (PPHV), U202.22 (PPHV)
/High_pow/5V_FB: R224.2, R225.1, U203.4 (FB)
/High_pow/ACN: C215.2, R214.2, U201.2 (ACN)
/High_pow/ACP: C215.1, R210.2, U201.3 (ACP)
/High_pow/BTST1: C229.2, U201.30 (BTST1)
/High_pow/BTST2: C231.2, U201.25 (BTST2)
/High_pow/CC1: C233.1, D201.4, U202.28 (CC1), USBC201.A5 (CC1)
/High_pow/CC2: C234.1, D201.6, U202.29 (CC2), USBC201.B5 (CC2)
/High_pow/CELL_BATPRESZ: R207.2, R208.1, U201.18 (CELL_BATPRESZ)
/High_pow/COMP1: C214.1, R211.1, U201.16 (COMP1)
/High_pow/COMP2: C221.1, R213.1, U201.17 (COMP2)
/High_pow/D+: D201.1, U202.26 (USB_P), USBC201.A6 (DP1), USBC201.B6 (DP2)
/High_pow/D-: D201.3, U202.27 (USB_N), USBC201.A7 (DN1), USBC201.B7 (DN2)
/High_pow/HIDRV1: Q201.4 (G), U201.31 (HIDRV1)
/High_pow/HIDRV2: Q204.4 (G), U201.24 (HIDRV2)
/High_pow/HP.CHRG_OK: R216.2, U201.4 (CHRG_OK); also elsewhere on the board
/High_pow/HP.EN_OTG: U201.5 (OTG/VAP); also elsewhere on the board
/High_pow/HP.IADPT: C224.1, R215.1, U201.8 (IADPT); also elsewhere on the board
/High_pow/HP.IBAT: C227.1, U201.9 (IBAT); also elsewhere on the board
/High_pow/HP.PD_IRQ: U202.10 (I2Cs_IRQ); also elsewhere on the board
/High_pow/HP.PSYS: R217.1, U201.10 (PSYS); also elsewhere on the board
/High_pow/I2C_EX.SCL: R206.2, U201.13 (SCL), U202.17 (I2Cm_SCL)
/High_pow/I2C_EX.SDA: R202.2, U201.12 (SDA), U202.16 (I2Cm_SDA)
/High_pow/I2C_PD.SCL: U202.9 (I2Cs_SCL); also elsewhere on the board
/High_pow/I2C_PD.SDA: U202.8 (I2Cs_SDA); also elsewhere on the board
/High_pow/ILIM_HIZ: R203.1, R204.2, U201.6 (ILIM_HIZ)
/High_pow/LDO_1V5: C228.1, U202.4 (LDO_1V5)
/High_pow/LDO_3V3: C230.1, R202.1, R206.1, U202.1 (LDO_3V3)
/High_pow/LODRV1: Q202.4 (G), U201.29 (LODRV1)
/High_pow/LODRV2: Q203.4 (G), U201.26 (LODRV2)
/High_pow/REGN: C205.1, R201.1, U201.28 (REGN)
/High_pow/SRN: R222.2, U201.19 (SRN)
/High_pow/SRP: R220.2, U201.20 (SRP)
/High_pow/SW1: C229.1, L201.1, Q201.1 (S), Q201.2 (S), Q201.3 (S), Q202.5 (D), Q202.6 (D), Q202.7 (D), Q202.8 (D), U201.32 (SW1)
/High_pow/SW2: C231.1, L201.2, Q203.5 (D), Q203.6 (D), Q203.7 (D), Q203.8 (D), Q204.1 (S), Q204.2 (S), Q204.3 (S), U201.23 (SW2)
/High_pow/TPS_STATUS: R223.1, U202.5 (GPIO0)
/High_pow/VBUS: C211.1, R209.2, U201.1 (VBUS)
/High_pow/VDDA: C201.1, R201.2, R203.2, R207.1, U201.7 (VDDA)
/High_pow/V_WIRE: C219.1, D201.5, U202.23 (VBUS_IN), U202.24 (VBUS_IN), U202.25 (VBUS_IN), U202.32 (VBUS), U202.33 (VBUS), USBC201.A4B9 (VBUS), USBC201.B4A9 (VBUS)
/High_pow/~BATDRV: Q205.4 (G), U201.21 (~BATDRV)
GND: C201.2, C202.2, C203.2, C204.2, C205.2, C206.2, C207.2, C208.2, C209.2, C210.2, C211.2, C212.2, C213.2, C214.2, C216.2, C217.2, C218.2, C219.2, C220.2, C221.2, C222.2, C223.2, C224.2, C225.2, C226.2, C227.2, C228.2, C230.2, C232.2, C233.2, C234.2, C235.2, C236.2, C237.2, C238.2, C239.2, C240.2, C241.2, C244.2, C245.2, C246.2, C247.1, C248.2, C249.2, D201.2, D202.1 (K), Q202.1 (S), Q202.2 (S), Q202.3 (S), Q203.1 (S), Q203.2 (S), Q203.3 (S), R204.1, R208.2, R215.2, R217.2, R219.1, R225.2, U201.14 (CMPIN), U201.27 (PGND), U201.33 (EP), U202.2 (ADCIN1), U202.3 (ADCIN2), U202.6 (GPIO1), U202.7 (GPIO2), U202.11 (GND), U202.12 (GND), U202.13 (GPIO11), U202.14 (GND), U202.18 (I2Cm_IRQ), U202.19 (GPIO3), U202.31 (GND), U202.36 (GPIO7), U202.37 (GPIO6), U202.39 (GND), U203.1 (GND), USBC201.1 (EH), USBC201.2 (EH), USBC201.3 (EH), USBC201.4 (EH), USBC201.A1B12 (GND), USBC201.B1A12 (GND); also elsewhere on the board
unnamed: C202.1, R205.2
unnamed: C217.1, R211.2
unnamed: C218.1, R213.2
unnamed: C222.1, C247.2, Q201.5 (D), Q201.6 (D), Q201.7 (D), Q201.8 (D), R212.2, R214.1
unnamed: C241.1, C243.2, Q205.5 (D), Q205.6 (D), Q205.7 (D), Q205.8 (D), R220.1, R221.1
unnamed: D202.2 (A), R223.2
unnamed: C242.1, U203.6 (BOOT)
unnamed: R218.2, R219.2, U203.5 (EN)
unnamed: C242.2, L202.1, U203.2 (SW)
VSYS: C232.1, C235.1, C236.1, C237.1, C238.1, C239.1, C240.1, C248.1, C249.1, Q204.5 (D), Q204.6 (D), Q204.7 (D), Q204.8 (D), Q205.1 (S), Q205.2 (S), Q205.3 (S), R218.1, U201.22 (VSYS), U203.3 (VIN); also elsewhere on the board

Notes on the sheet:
BUCK-BOOST POWER STAGE
SVEGLIA
NB: I pin AGND e GND sono collegati elettricamente nello schematico per garantire il riferimento DC. Nel PCB, devono essere uniti in un UNICO punto (Star Ground), preferibilmente sotto il Pad Termico (EP) del chip, per isolare la logica analogica dai disturbi di potenza.
USB C PD CONTROLLER
ESD PROTECTION
PD_IRQ must be connected to an INTERRUPT on the STM
ADC INPUT
POWER MANAGEMENT IC
NOTE: CELL_BATPRESZ/CELL_CONF CONFIGURATION --------------------------------- Current Config: 4S (16.8V) R_high (to REGN): 100k (1%) R_low (to GND) : 300k (1%) Ratio = 300k / (100k + 300k) = 0.75 (75%) DATASHEET REFERENCE (Table 9-1) --------------------------------------------- | Cell | Pin Voltag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
USB C PD CONTROLLER CONFIG
/* ========================================================================== BQ25713 PINOUT REFERENCE & FUNCTIONAL GROUPS ========================================================================== */ /* -------------------------------------------------------------------------- 1. POWER PATH & SWIT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
USB-C INTERFACE
2.2-3.3u
Status LED
5V Supply
VANNO A STM
MCU
POWER MANAGEMENT IC CONFIG
UNUSED GPIO MUST BE GND TIED
CHIAVE

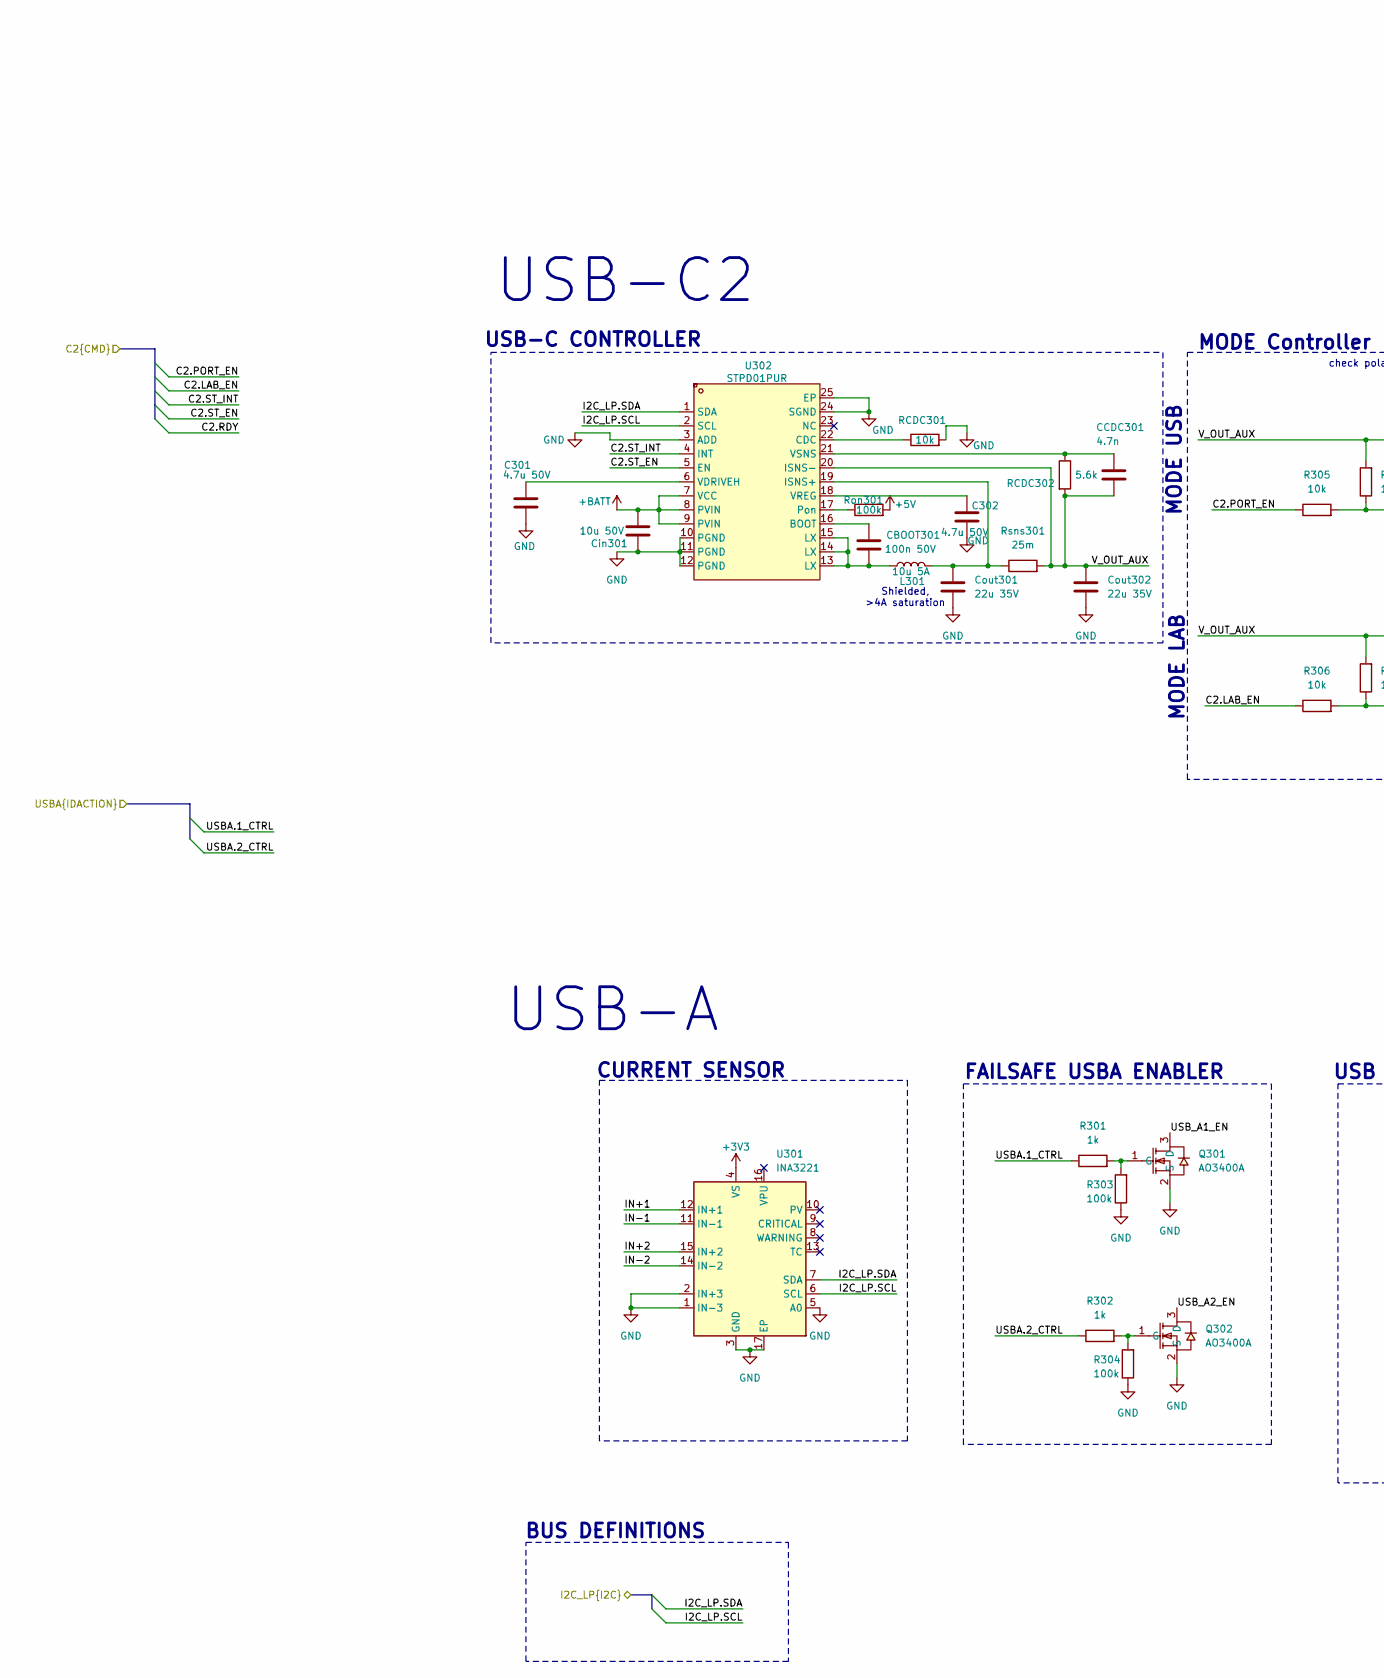
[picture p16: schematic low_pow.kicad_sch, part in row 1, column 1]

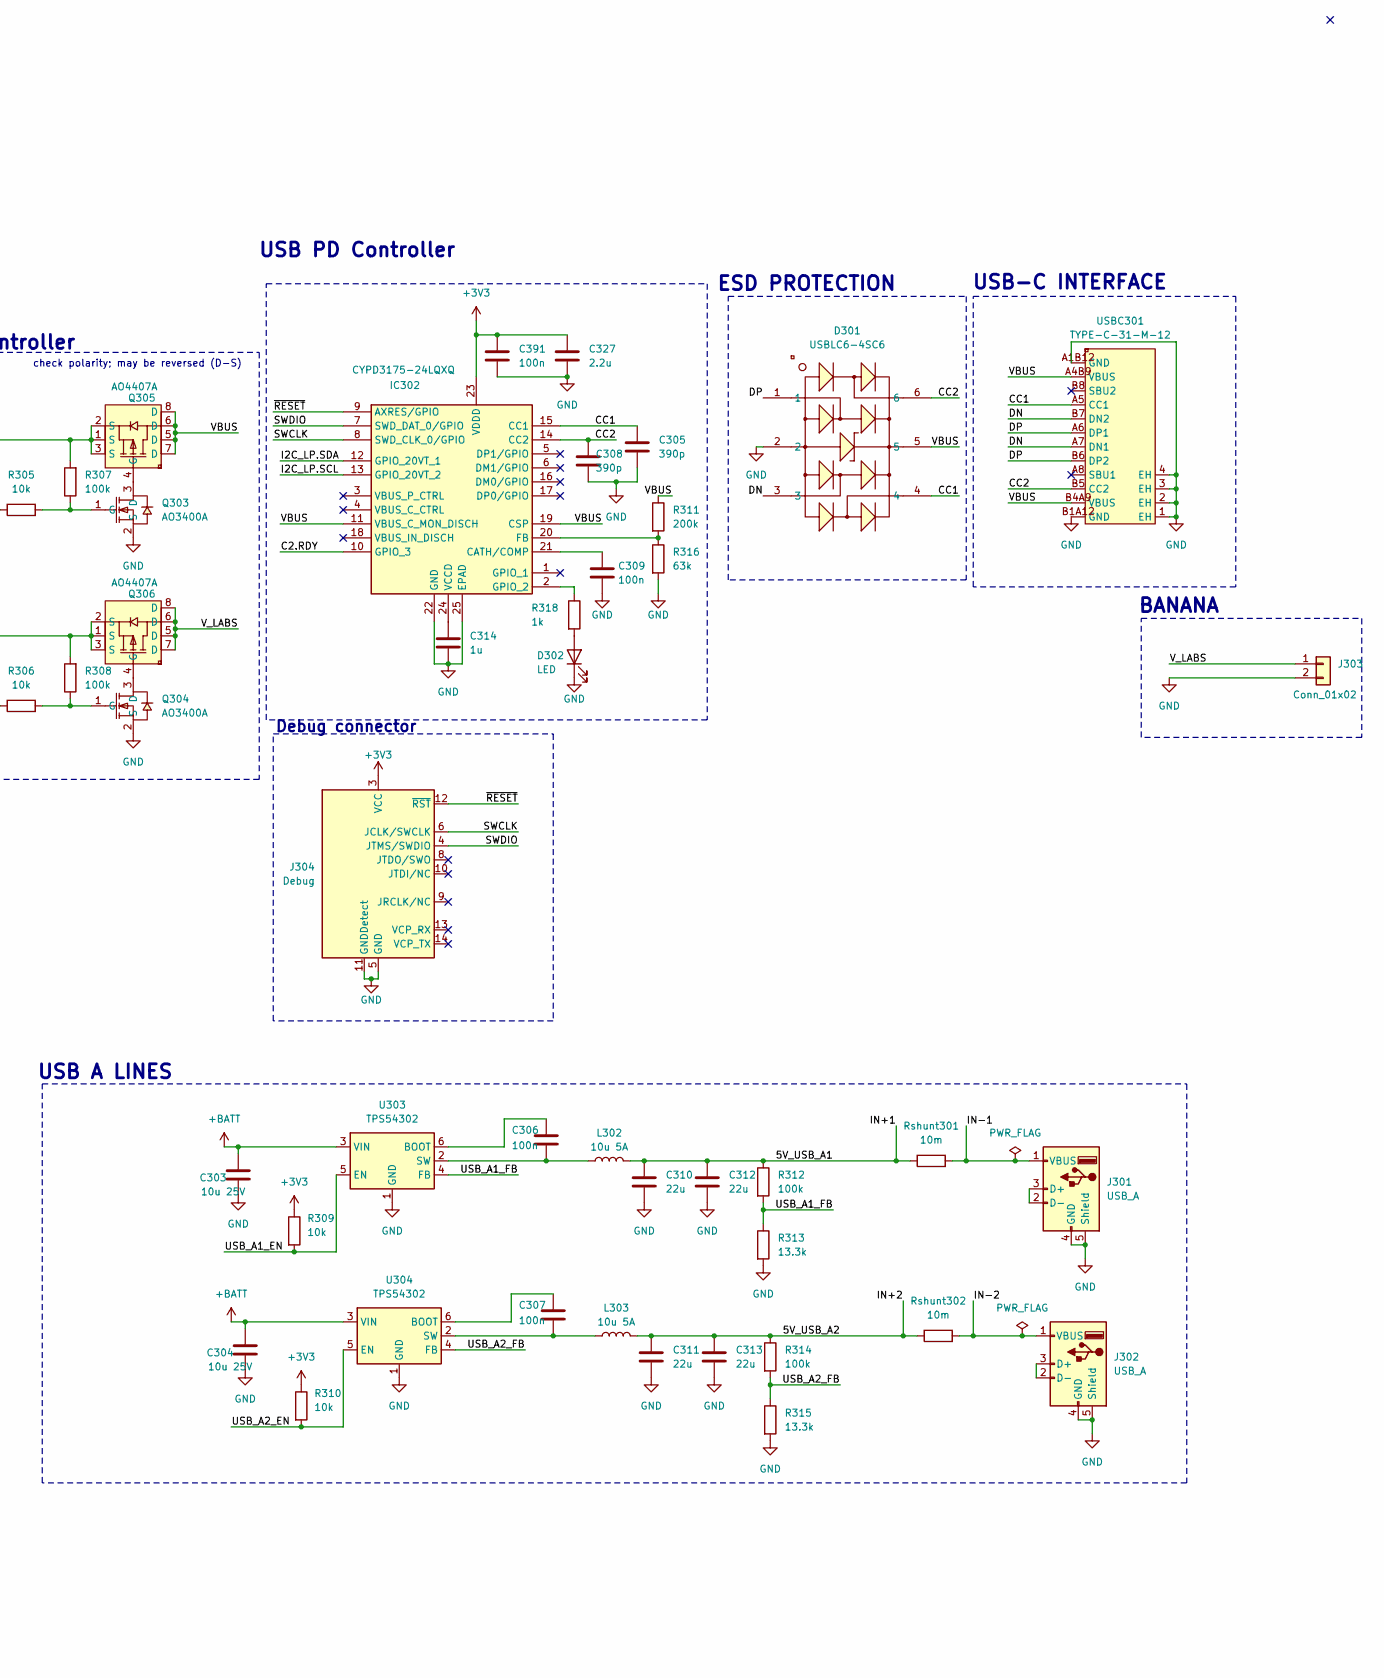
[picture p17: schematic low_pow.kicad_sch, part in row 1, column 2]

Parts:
C301, C302: 4.7u 50V; C_0805_2012Metric
C303, C304: 10u 25V; C_1206_3216Metric
C305, C308: 390p; R_0603_1608Metric
C306, C307: 100n; C_0603_1608Metric
C309, C391: 100n; R_0603_1608Metric
C310, C311, C312, C313: 22u; C_0805_2012Metric
C314: 1u; R_0603_1608Metric
C327: 2.2u; C_0805_2012Metric
CBOOT301: 100n 50V; C_0603_1608Metric
CCDC301: 4.7n; C_0805_2012Metric
Cin301: 10u 50V; C_0805_2012Metric
Cout301, Cout302: 22u 35V; C_1210_3225Metric
D301: USBLC6-4SC6; SOT-23-6_L2.9-W1.6-P0.95-LS2.8-BL; LCSC Part C111212
D302: LED; LED_0603_1608Metric
IC302: CYPD3175-24LQXQ; QFN50P400X400X60-25N-D; Mouser Part Number 727-CYPD3175-24LQXQ
J301, J302: USB_A; USB_A_Molex_67643_Horizontal
J303: Conn_01x02; TerminalBlock_bornier-2_P5.08mm
J304: Debug; SAMTEC_FTSH-107-01-L-DV-K-TR
L301, L302, L303: 10u 5A; L_7.3x7.3_H4.5
Q301, Q302, Q303, Q304: AO3400A; SOT-23-3_L2.9-W1.3-P1.90-LS2.4-BR; LCSC Part C20917
Q305, Q306: AO4407A; SOIC-8_L4.9-W3.9-P1.27-LS6.0-BL; LCSC Part C16072
R301, R302, R318: 1k; R_0603_1608Metric
R303, R304, R307, R308, R312, R314: 100k; R_0603_1608Metric
R305, R306, R309, R310: 10k; R_0603_1608Metric
R311: 200k; R_0603_1608Metric
R313, R315: 13.3k; R_0603_1608Metric
R316: 63k; R_0603_1608Metric
RCDC301: 10k; R_0603_1608Metric
RCDC302: 5.6k; R_0603_1608Metric
Ron301: 100k; R_0603_1608Metric
Rshunt301, Rshunt302: 10m; R_1206_3216Metric
Rsns301: 25m; R_1206_3216Metric
U301: INA3221; Texas_RGV0016A_VQFN-16-1EP_4x4mm_P0.65mm_EP2.1x2.1mm
U302: STPD01PUR; QFN-24_L4.0-W3.0-P0.40-TL-EP; LCSC Part C5268090
U303, U304: TPS54302; SOT-23-6
USBC301: TYPE-C-31-M-12; USB-C_SMD-TYPE-C-31-M-12_1; LCSC Part C165948

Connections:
+3V3: C327.1, C391.1, IC302.23 (VDDD), J304.3 (VCC), R309.1, R310.1, U301.4 (VS); also elsewhere on the board
+5V: Ron301.2; also elsewhere on the board
+BATT: C303.1, C304.1, Cin301.1, U302.7 (VCC), U302.8 (PVIN), U302.9 (PVIN), U303.3 (VIN), U304.3 (VIN); also elsewhere on the board
/BMS/I2C_LP.SCL: IC302.13 (GPIO_20VT_2), U301.6 (SCL), U302.2 (SCL); also elsewhere on the board
/BMS/I2C_LP.SDA: IC302.12 (GPIO_20VT_1), U301.7 (SDA), U302.1 (SDA); also elsewhere on the board
/Logic/C2.LAB_EN: R306.1; also elsewhere on the board
/Logic/C2.PORT_EN: R305.1; also elsewhere on the board
/Logic/C2.RDY: IC302.10 (GPIO_3); also elsewhere on the board
/Logic/C2.ST_EN: U302.5 (EN); also elsewhere on the board
/Logic/C2.ST_INT: U302.4 (INT); also elsewhere on the board
/Logic/USBA.1_CTRL: R301.1; also elsewhere on the board
/Logic/USBA.2_CTRL: R302.1; also elsewhere on the board
/Low_pow/5V_USB_A1: C310.1, C312.1, L302.2, R312.1, Rshunt301.1, U301.12 (IN+1)
/Low_pow/5V_USB_A2: C311.1, C313.1, L303.2, R314.1, Rshunt302.1, U301.15 (IN+2)
/Low_pow/CC1: C305.1, D301.4, IC302.15 (CC1), USBC301.A5 (CC1)
/Low_pow/CC2: C308.1, D301.6, IC302.14 (CC2), USBC301.B5 (CC2)
/Low_pow/DN: D301.3, USBC301.A7 (DN1), USBC301.B7 (DN2)
/Low_pow/DP: D301.1, USBC301.A6 (DP1), USBC301.B6 (DP2)
/Low_pow/IN-1: J301.1 (VBUS), Rshunt301.2, U301.11 (IN-1)
/Low_pow/IN-2: J302.1 (VBUS), Rshunt302.2, U301.14 (IN-2)
/Low_pow/SWCLK: IC302.8 (SWD_CLK_0/GPIO), J304.6 (JCLK/SWCLK)
/Low_pow/SWDIO: IC302.7 (SWD_DAT_0/GPIO), J304.4 (JTMS/SWDIO)
/Low_pow/USB_A1_EN: Q301.3 (D), R309.2, U303.5 (EN)
/Low_pow/USB_A1_FB: R312.2, R313.1, U303.4 (FB)
/Low_pow/USB_A2_EN: Q302.3 (D), R310.2, U304.5 (EN)
/Low_pow/USB_A2_FB: R314.2, R315.1, U304.4 (FB)
/Low_pow/VBUS: D301.5, IC302.11 (VBUS_C_MON_DISCH), IC302.19 (CSP), Q305.5 (D), Q305.6 (D), Q305.7 (D), Q305.8 (D), R311.1, USBC301.A4B9 (VBUS), USBC301.B4A9 (VBUS)
/Low_pow/V_LABS: J303.1, Q306.5 (D), Q306.6 (D), Q306.7 (D), Q306.8 (D)
/Low_pow/V_OUT_AUX: CCDC301.2, Cout302.1, Q305.1 (S), Q305.2 (S), Q305.3 (S), Q306.1 (S), Q306.2 (S), Q306.3 (S), R307.2, R308.2, RCDC302.2, Rsns301.2, U302.20 (ISNS-)
/Low_pow/~RESET: IC302.9 (AXRES/GPIO), J304.12 (~RST)
GND: C301.2, C302.2, C303.2, C304.2, C305.2, C308.2, C309.2, C310.2, C311.2, C312.2, C313.2, C314.2, C327.2, C391.2, Cin301.2, Cout301.2, Cout302.2, D301.2, D302.1 (K), IC302.22 (GND), IC302.25 (EPAD), J301.4 (GND), J301.5 (Shield), J302.4 (GND), J302.5 (Shield), J303.2, J304.5 (GND), J304.7 (GND), J304.11 (GNDDetect), Q301.2 (S), Q302.2 (S), Q303.2 (S), Q304.2 (S), R303.1, R304.1, R313.2, R315.2, R316.2, RCDC301.2, U301.1 (IN-3), U301.2 (IN+3), U301.3 (GND), U301.5 (A0), U301.17 (EP), U302.3 (ADD), U302.10 (PGND), U302.11 (PGND), U302.12 (PGND), U302.24 (SGND), U302.25 (EP), U303.1 (GND), U304.1 (GND), USBC301.1 (EH), USBC301.2 (EH), USBC301.3 (EH), USBC301.4 (EH), USBC301.A1B12 (GND), USBC301.B1A12 (GND); also elsewhere on the board
unnamed: CBOOT301.2, L301.1, U302.13 (LX), U302.14 (LX), U302.15 (LX)
unnamed: D302.2 (A), R318.2
unnamed: C309.1, IC302.21 (CATH/COMP)
unnamed: IC302.20 (FB), R311.2, R316.1
unnamed: IC302.2 (GPIO_2), R318.1
unnamed: C314.1, IC302.24 (VCCD)
unnamed: J301.2 (D-), J301.3 (D+)
unnamed: J302.2 (D-), J302.3 (D+)
unnamed: Q301.1 (G), R301.2, R303.2
unnamed: Q302.1 (G), R302.2, R304.2
unnamed: Q303.3 (D), Q305.4 (G)
unnamed: Q303.1 (G), R305.2, R307.1
unnamed: Q304.3 (D), Q306.4 (G)
unnamed: Q304.1 (G), R306.2, R308.1
unnamed: CBOOT301.1, U302.16 (BOOT)
unnamed: RCDC301.1, U302.22 (CDC)
unnamed: Cout301.1, L301.2, Rsns301.1, U302.19 (ISNS+)
unnamed: Ron301.1, U302.17 (Pon)
unnamed: C301.1, U302.6 (VDRIVEH)
unnamed: C302.1, U302.18 (VREG)
unnamed: CCDC301.1, RCDC302.1, U302.21 (VSNS)
unnamed: C306.1, U303.6 (BOOT)
unnamed: C306.2, L302.1, U303.2 (SW)
unnamed: C307.1, U304.6 (BOOT)
unnamed: C307.2, L303.1, U304.2 (SW)

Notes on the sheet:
BUS DEFINITIONS
USB-C CONTROLLER
USB-C2
Shielded, >4A saturation
USB-C INTERFACE
USB PD Controller
FAILSAFE USBA ENABLER
CURRENT SENSOR
MODE USB
Debug connector
USB-A
MODE Controller
USB A LINES
ESD PROTECTION
BANANA
MODE LAB
check polarity; may be reversed (D-S)

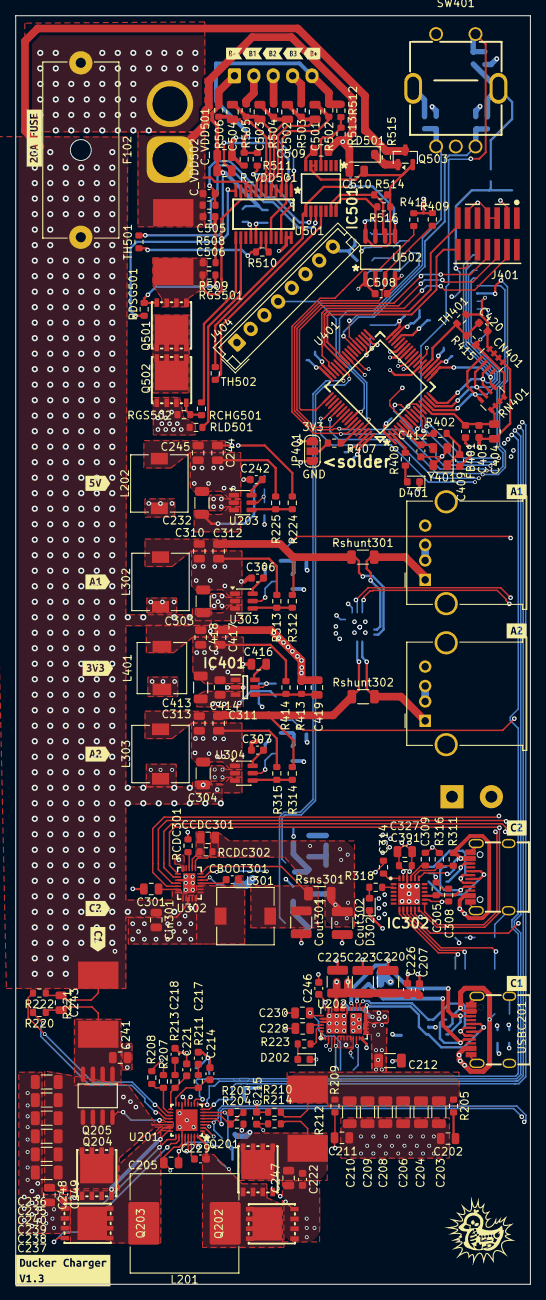
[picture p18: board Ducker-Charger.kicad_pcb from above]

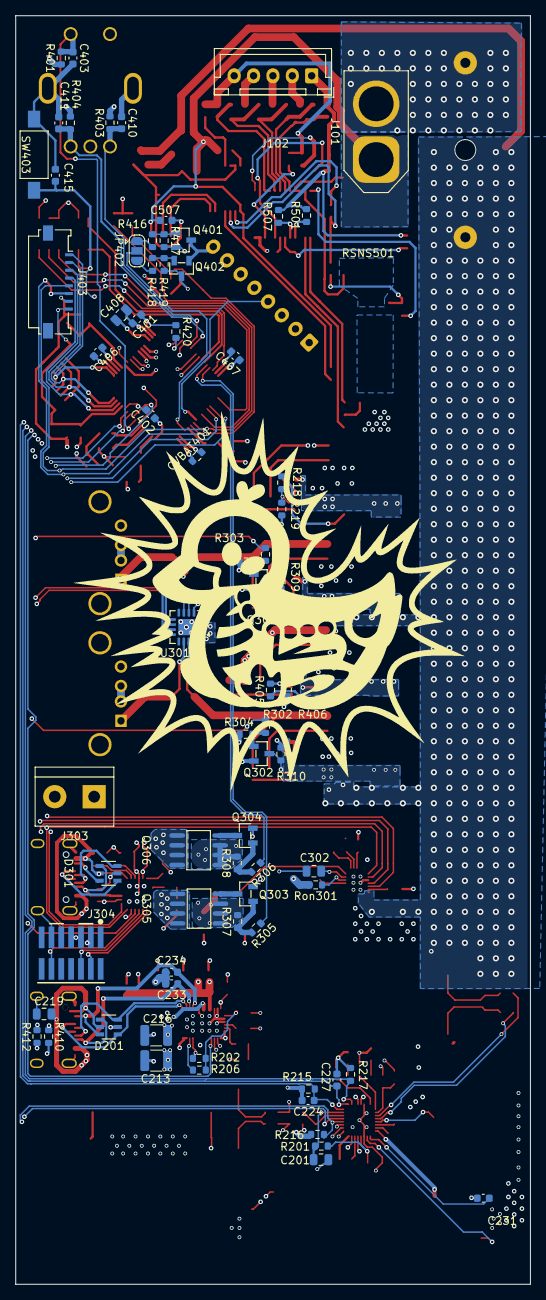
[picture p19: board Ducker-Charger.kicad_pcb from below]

Board: 4 copper layers, 66.4 x 163.6 mm, 276 parts (72 on the bottom side), 180 nets.

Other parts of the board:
F102: 20A; Fuseholder_Cylinder-5x20mm_Schurter_0031_8201_Horizontal_Op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
J101: Conn_01x02; AMASS_XT60-M_1x02_P7.20mm_Vertical
J102: Conn_01x05; JST_XH_B5B-XH-A_1x05_P2.50mm_Vertical
kibuzzard-6A3BBBB4: G***; kibuzzard-6A3BBBB4
kibuzzard-6A3BBBD7: G***; kibuzzard-6A3BBBD7
kibuzzard-6A3BBBE2: G***; kibuzzard-6A3BBBE2
kibuzzard-6A3BBBEB: G***; kibuzzard-6A3BBBEB
kibuzzard-6A3BBBFC: G***; kibuzzard-6A3BBBFC
kibuzzard-6A3BBC07: G***; kibuzzard-6A3BBC07
kibuzzard-6A3BBC42: G***; kibuzzard-6A3BBC42
kibuzzard-6A3BBDB6: G***; kibuzzard-6A3BBDB6
kibuzzard-6A3BBDBF: G***; kibuzzard-6A3BBDBF
kibuzzard-6A3BBDD0: G***; kibuzzard-6A3BBDD0
kibuzzard-6A3BBDD9: G***; kibuzzard-6A3BBDD9
kibuzzard-6A3C421F: G***; kibuzzard-6A3C421F
kibuzzard-694FF1FC: G***; kibuzzard-694FF1FC
kibuzzard-694FF21A: G***; kibuzzard-694FF21A
kibuzzard-694FF228: G***; kibuzzard-694FF228
kibuzzard-694FF236: G***; kibuzzard-694FF236
kibuzzard-694FF248: G***; kibuzzard-694FF248

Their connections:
+BATT: F102.2; also elsewhere on the board
-BATT: J101.1; also elsewhere on the board
BATT_SENS_B1: J102.2; also elsewhere on the board
BATT_SENS_B2: J102.3; also elsewhere on the board
BATT_SENS_B3: J102.4; also elsewhere on the board
BATT_SENS_B+: J102.5; also elsewhere on the board
BATT_SENS_B-: J102.1; also elsewhere on the board
unnamed: F102.1, J101.2

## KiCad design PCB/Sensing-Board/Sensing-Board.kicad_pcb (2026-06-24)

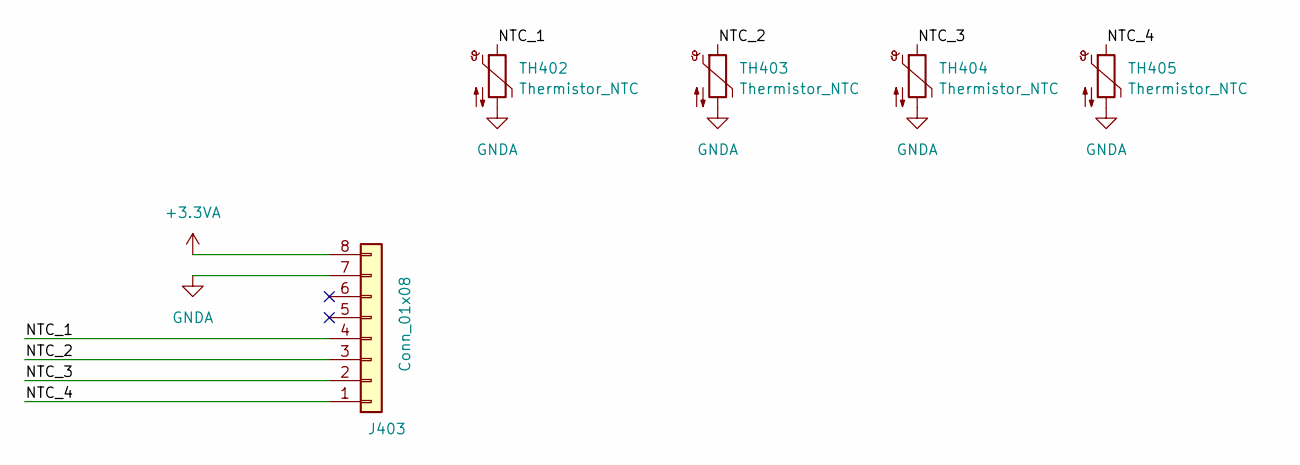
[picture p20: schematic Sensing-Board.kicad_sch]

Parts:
J403: Conn_01x08; Molex_200528-0080_1x08-1MP_P1.00mm_Horizontal
TH402, TH403, TH404, TH405: Thermistor_NTC; R_0603_1608Metric

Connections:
+3.3VA: J403.8
/NTC_1: J403.4, TH402.1
/NTC_2: J403.3, TH403.1
/NTC_3: J403.2, TH404.1
/NTC_4: J403.1, TH405.1
GNDA: J403.7, TH402.2, TH403.2, TH404.2, TH405.2

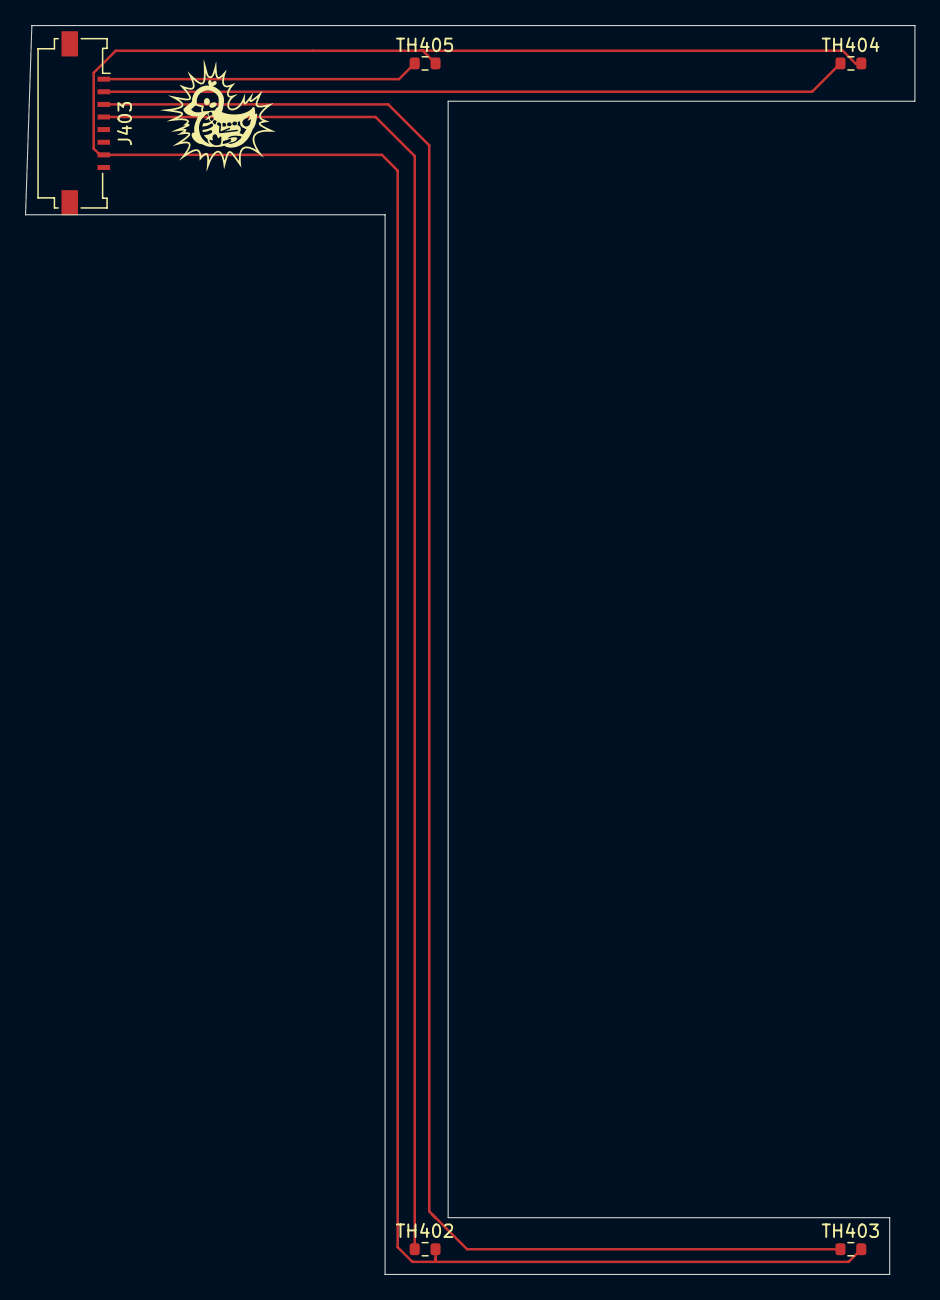
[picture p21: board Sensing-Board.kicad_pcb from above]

Board: 2 copper layers, 70.5 x 99.0 mm, 6 parts (1 on the bottom side), 5 nets.

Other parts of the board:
kibuzzard-6A3C49BF: G***; kibuzzard-6A3C49BF

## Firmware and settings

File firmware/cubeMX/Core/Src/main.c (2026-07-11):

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
/* Includes ------------------------------------------------------------------*/
#include "main.h"
#include "adc.h"
#include "gpio.h"
#include "i2c.h"
#include "spi.h"
#include "tim.h"
#include "usart.h"

/* USER CODE BEGIN Includes */
#include "app/initialization.h"   /* every-boot IC init (TPS25750 patch, INA3221, STPD01) */
#include "app/provisioning.h"     /* one-time BQ34Z100 data-flash provisioning */
#include "system/charge.h"
#include "system/fsm.h"
#include "app/encoder.h"
#include "app/telemetry.h"
#include "display/ili9341.h"
#include "ui/ui_state.h"
/* USER CODE END Includes */


/* USER CODE BEGIN PV */
static FSM fsm;
static uint32_t lastActivityTick = 0;
static uint32_t lastEncoderActivityTick = 0;
/* USER CODE END PV */

void SystemClock_Config(void);
/**
 * @brief  The application entry point.
 * @retval int
 */
int main(void) {

  /* MCU Configuration--------------------------------------------------------*/

  /* Reset of all peripherals, Initializes the Flash interface and the Systick.
   */
  HAL_Init();

  /* Configure the system clock */
  SystemClock_Config();

  /* Initialize all configured peripherals */
  MX_GPIO_Init();
  MX_ADC1_Init();
  MX_I2C1_Init();
  MX_SPI1_Init();
  MX_TIM3_Init();
  MX_USART1_UART_Init();
  MX_I2C3_Init();
  /* USER CODE BEGIN 2 */
  /* Boot camp: every IC with volatile config gets initialized here.
   * A failed step degrades the boot (report available for the UI),
   * it never blocks it. */
  (void)System_Initialization();

  /* Fuel-gauge data flash: one-time, marker-guarded, refuses to run
   * unless the pack is at rest. No-op on already-provisioned units. */
  if (Provisioning_Required()) {
    (void)Provisioning_RunGauge();
  }

  Encoder_Init(&htim3);
  Telemetry_Init(&hi2c1, &hi2c3);
  ILI9341_Init(&hspi1);
  UI_Init();

  init();
  PB_FSM_Init(&fsm);
  lastActivityTick = HAL_GetTick();
  /* USER CODE END 2 */

  /* Infinite loop */
  /* USER CODE BEGIN WHILE */
  while (1) {
    /* USER CODE END WHILE */

    /* USER CODE BEGIN 3 */
    readNCS();

    Event_t evt;
    if (event_pop(&evt)) {
      if (evt == EVT_BUTTON_SHORT || evt == EVT_BUTTON_LONG)
        lastActivityTick = HAL_GetTick();
      PB_FSM_FireEvent(&fsm, evt);
    }

    /* Real knob/button activity also counts against the global inactivity
     * timer -- otherwise SLEEP/DEEP_SLEEP would still fire on schedule
     * while the user is actively turning the encoder. */
    uint32_t encoderActivityTick = Encoder_LastActivityTick();
    if (encoderActivityTick != lastEncoderActivityTick) {
      lastEncoderActivityTick = encoderActivityTick;
      lastActivityTick = HAL_GetTick();
    }

    /* Deep-sleep entry: encoder button held >= BUTTON_DEEPSLEEP_HOLD_MS,
     * then released, pushes EVT_BUTTON_LONG (IDLE/SLEEP -> DEEP_SLEEP).
     * On release and not while held: STOP mode wakes on both EXTI0 edges,
     * so sleeping with the button still down would wake immediately. */
    static uint32_t holdStartTick = 0;
    if (Encoder_IsHeld()) {
      if (holdStartTick == 0)
        holdStartTick = HAL_GetTick();
    } else {
      if (holdStartTick != 0 &&
          HAL_GetTick() - holdStartTick >= BUTTON_DEEPSLEEP_HOLD_MS)
        event_push(EVT_BUTTON_LONG);
      holdStartTick = 0;
    }

    if (HAL_GetTick() - lastActivityTick > INACTIVITY_TIMEOUT_MS) {
      event_push(EVT_INACTIVITY);
      lastActivityTick = HAL_GetTick();
    }

    State_ID_t stateBeforeUpdate = PB_FSM_GetState(&fsm);
    PB_FSM_Update(&fsm);

    /* Leaving DEEP_SLEEP: the UI was frozen mid-screen when the MCU
     * stopped; restart it from the splash and swallow the wake press. */
    if (stateBeforeUpdate == STATE_DEEP_SLEEP &&
        PB_FSM_GetState(&fsm) != STATE_DEEP_SLEEP) {
      UI_OnDeepSleepWake();
    }

    /* Reshape the charge layer's fresh readings for the UI. Must run here
     * and not inside UI_Tick(): the FSM keeps polling sensors in SLEEP
     * (Sleep_Run) but UI_Tick() is skipped below, and the uptime counter,
     * the energy integral and the per-port histories have to keep running
     * while the screen is dark. Telemetry_Poll() rate-limits itself. */
    Telemetry_Poll();

    /* Skip UI work while the FSM has the backlight physically off --
     * avoids pointless SPI/CPU churn into a dark screen. In DEEP_SLEEP
     * this also keeps the wake press latched in the encoder layer until
     * UI_OnDeepSleepWake() consumes it. */
    State_ID_t st = PB_FSM_GetState(&fsm);
    if (st != STATE_SLEEP && st != STATE_DEEP_SLEEP) {
      UI_Tick();
    } else if (st == STATE_SLEEP && Encoder_IsPressed()) {
      /* UI_Tick() is the only consumer of button presses, and it is not
       * running here: turn the raw press into the wake event ourselves,
       * or SLEEP -> IDLE could never fire on a button. Consuming the
       * press also keeps it from navigating the UI after the wake. */
      event_push(EVT_BUTTON_SHORT);
    }
  }
  /* USER CODE END 3 */
}

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


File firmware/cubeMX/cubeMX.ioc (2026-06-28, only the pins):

Mcu.UserName=STM32F401RBTx
PA0-WKUP.Signal=ADCx_IN0
PA1.Signal=ADCx_IN1
PA10.Signal=USART1_RX
PA11.GPIO_Label=C2_LAB_EN
PA11.Signal=GPIO_Output
PA12.GPIO_Label=C2_PORT_EN
PA12.Signal=GPIO_Output
PA13.Signal=SYS_JTMS-SWDIO
PA14.Signal=SYS_JTCK-SWCLK
PA2.Signal=ADCx_IN2
PA3.Signal=ADCx_IN3
PA4.Signal=ADCx_IN4
PA5.Signal=SPI1_SCK
PA6.Signal=ADCx_IN6
PA7.Signal=ADCx_IN7
PA8.Signal=I2C3_SCL
PA9.Signal=USART1_TX
PB0.GPIO_Label=DISP_CS
PB0.Signal=GPIO_Output
PB1.GPIO_Label=DISP_DC
PB1.Signal=GPIO_Output
PB13.GPIO_Label=HP_CHRG_OK
PB13.Signal=GPIO_Input
PB14.GPIO_Label=HP_PD_IRQ
PB14.Signal=GPIO_Input
PB15.GPIO_Label=HP_EN_OTG
PB15.Signal=GPIO_Output
PB2.GPIO_Label=DISP_RST
PB2.Signal=GPIO_Output
PB3.Signal=SYS_JTDO-SWO
PB5.Signal=SPI1_MOSI
PB6.Signal=I2C1_SCL
PB7.Signal=I2C1_SDA
PB8.GPIO_Label=BCKL_CTRL
PB8.Signal=GPIO_Output
PC0.GPIO_Label=ENCOD_BUTT
PC0.Signal=GPIO_Input
PC1.GPIO_Label=USB_A1_CTRL
PC1.Signal=GPIO_Output
PC11.GPIO_Label=C2_ST_EN
PC11.Signal=GPIO_Output
PC12.GPIO_Label=C2_ST_INT
PC12.Signal=GPIO_Input
PC13-ANTI_TAMP.GPIO_Label=STATUS
PC13-ANTI_TAMP.Signal=GPIO_Output
PC2.GPIO_Label=USB_A2_CTRL
PC2.Signal=GPIO_Output
PC3.GPIO_Label=C2_RDY
PC3.Signal=GPIO_Input
PC4.Signal=ADCx_IN14
PC6.Signal=S_TIM3_CH1
PC7.Signal=S_TIM3_CH2
PC9.Signal=I2C3_SDA

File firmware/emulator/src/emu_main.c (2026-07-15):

/**
 * @file    emu_main.c
 * @brief   Emulator entry point: SDL window + scenario keys + firmware
 *          thread. The unmodified firmware main() (renamed fw_main by
 *          the Makefile) runs in its own thread against the fake HAL.
 *
 * Keys:
 *   arrows / wheel   encoder rotation
 *   SPACE            encoder button (hold = long press)
 *   c                plug / unplug the C1 charger
 *   v                attach / detach a C2 PD sink
 *   1 / 2            attach / detach a load on USB-A1 / A2
 *   l                attach / detach a resistive load on the lab output
 *   o                INA3221 critical alert on A1 (overcurrent)
 *   t/h/u/f          gauge faults: overtemp / BATHI / BATLOW / CF
 *   b                gauge I2C bus failure (NACK everything)
 *   x / z / r        CYPD3175: OVP / OCP / hard reset
 *   g                STPD01 short-circuit fault
 *   k                toggle CHRG_OK line
 *   w                wake from STOP mode
 *   q                shutdown (long-press) -> DEEP_SLEEP (from IDLE/SLEEP)
 *   i                print board/firmware status
 *   s                dump screen to screen.ppm
 *   ESC              quit
 *
 * Headless: emulator --headless <ms> [--at <ms>:<key> ...]
 *           runs without a window, injects scripted keys, dumps
 *           screen.ppm and a status report on exit.
 */
#include "sim.h"

#include "system/charge.h"      /* status getters (real firmware code) */
#include "system/event.h"       /* event_push, EVT_BUTTON_LONG */
#include "system/fsm.h"         /* PB_FSM_ActiveState */
#include "app/telemetry.h"      /* port_stats: what the UI actually shows */

#include <pthread.h>
#include <stdio.h>
#include <stdlib.h>
#include <string.h>
#include <unistd.h>

int fw_main(void);              /* firmware main(), renamed */

static void *fw_thread(void *arg)
{
    (void)arg;
    sim_log("[EMU ] firmware thread started");
    fw_main();
    return NULL;
}

/* ---------------- scenario toggles ---------------- */

static int tog_a1_oc, tog_ot, tog_bathi, tog_batlow, tog_cf, tog_stpd,
           tog_gg_bus;

static void set_charger(bool on)
{
    board.charger_attached = on;
    sim_gpio_drive_input(1, 13, on ? 1 : 0);    /* CHRG_OK (BQ25713) */
    tps_plug_charger(on);
}

static void print_status(void)
{
    sim_lock();
    FuelGaugeSensors fg = getFuelGaugeData();
    PDContract c1 = getPrimaryUSBC_Contract();
    PDContract c2 = getSecondaryUSBC_Contract();
    INA3221_Sensors ina = getINA3221_Sensors();
    fprintf(stderr,
        "---------------- STATUS ----------------\n"
        "fsm:    %s\n"
        "board:  SoC %.1f%%  V %.0f mV  I %+.0f mA  T %.1f C\n"
        "gauge:  SoC %.0f%%  V %.0f mV  I %.0f mA  flags[CHG=%d DSG=%d BATHI=%d BATLOW=%d OT=%d]\n"
        "C1:     plugged=%d sink=%d nego=%d  %.0f mV / %.0f mA\n"
        "C2:     plugged=%d nego=%d  %.0f mV / %.0f mA\n"
        "ports:  A1=%d A2=%d C2=%d OTG=%d STPD_EN=%d  INA[%.0f %.0f]\n"
        "lab:    EN=%d load=%d  %.0f mA @ %.0f mV (ILIM %.0f mA)\n"
        "pins:   PD_IRQ=%d STPD_INT=%d CYPD_INT=%d CHRG_OK=%d BCKL=%d\n"
        "-----------------------------------------\n",
        sim_fsm_name(),
        board.soc, board.pack_mv, board.i_batt_ma, board.temp_c,
        fg.SoC, fg.voltage, fg.current,
        fg.flags.CHG, fg.flags.DSG, fg.flags.BATHI, fg.flags.BATLOW,
        fg.flags.OTC || fg.flags.OTD,
        c1.isPlugged, c1.isSink, c1.isNegotiationDone, c1.voltage, c1.maxCurrent,
        c2.isPlugged, c2.isNegotiationDone, c2.voltage, c2.maxCurrent,
        get_USBA1_Status(), get_USBA2_Status(), get_USBC2_Status(),
        get_OTG_Status(), get_STPD01_Enabled(),
        ina.current_channel1, ina.current_channel2,
        sim_gpio_get(0, 11), board.lab_load_attached,
        board.lab_ma, stpd_vout_mv(), stpd_ilim_ma(),
        sim_gpio_get(1, 14), sim_gpio_get(2, 12), sim_gpio_get(2, 3),
        sim_gpio_get(1, 13), sim_gpio_get(1, 8));

    fprintf(stderr, "stats:  energy_out %lu mWh  uptime %lu s  P %ld mW\n",
            (unsigned long)sys_stats.energy_out_mWh,
            (unsigned long)sys_stats.uptime_s, (long)telemetry.power_mW);

    /* what the PORTS page / lab bench page read out of telemetry */
    static const char *pname[5] = { "A1", "A2", "C1", "C2", "LAB" };
    for (int i = 0; i < 5; i++) {
        int nz = 0;
        for (int k = 0; k < TELEMETRY_HISTORY_SIZE; k++)
            if (port_stats[i].history[k]) nz++;
        fprintf(stderr,
                "portmon: %-3s active=%d  %5u mV  %5d mA  hist[idx=%2u nonzero=%2d]\n",
                pname[i], port_stats[i].active,
                port_stats[i].voltage_mv, port_stats[i].current_mA,
                port_stats[i].idx, nz);
    }
    fprintf(stderr, "-----------------------------------------\n");
    sim_unlock();
}
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

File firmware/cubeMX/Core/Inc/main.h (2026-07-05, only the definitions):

#define STATUS_Pin GPIO_PIN_13
#define STATUS_GPIO_Port GPIOC
#define ENCOD_BUTT_Pin GPIO_PIN_0
#define ENCOD_BUTT_GPIO_Port GPIOC
#define USB_A1_CTRL_Pin GPIO_PIN_1
#define USB_A1_CTRL_GPIO_Port GPIOC
#define USB_A2_CTRL_Pin GPIO_PIN_2
#define USB_A2_CTRL_GPIO_Port GPIOC
#define C2_RDY_Pin GPIO_PIN_3
#define C2_RDY_GPIO_Port GPIOC
#define DISP_CS_Pin GPIO_PIN_0
#define DISP_CS_GPIO_Port GPIOB
#define DISP_DC_Pin GPIO_PIN_1
#define DISP_DC_GPIO_Port GPIOB
#define DISP_RST_Pin GPIO_PIN_2
#define DISP_RST_GPIO_Port GPIOB
#define HP_CHRG_OK_Pin GPIO_PIN_13
#define HP_CHRG_OK_GPIO_Port GPIOB
#define HP_PD_IRQ_Pin GPIO_PIN_14
#define HP_PD_IRQ_GPIO_Port GPIOB
#define HP_EN_OTG_Pin GPIO_PIN_15
#define HP_EN_OTG_GPIO_Port GPIOB
#define C2_LAB_EN_Pin GPIO_PIN_11
#define C2_LAB_EN_GPIO_Port GPIOA
#define C2_PORT_EN_Pin GPIO_PIN_12
#define C2_PORT_EN_GPIO_Port GPIOA
#define C2_ST_EN_Pin GPIO_PIN_11
#define C2_ST_EN_GPIO_Port GPIOC
#define C2_ST_INT_Pin GPIO_PIN_12
#define C2_ST_INT_GPIO_Port GPIOC
#define BCKL_CTRL_Pin GPIO_PIN_8
#define BCKL_CTRL_GPIO_Port GPIOB

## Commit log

2025-10-14 feat: added kicad project
    [Ducker-Charger.kicad_pcb, Ducker-Charger.kicad_sch]
2025-11-17 feat: general layout
    [BMS.kicad_sch, Ducker-Charger.kicad_sch, Logic.kicad_sch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]
2025-11-17 fix: typo
    [Ducker-Charger.kicad_sch]
2025-11-17 feat: added High power main sections
    [BMS.kicad_sch, Logic.kicad_sch, high_pow.kicad_sch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]
2025-11-18 feat: added capacitors to BUCK-BOOST POWER STAGE
    [high_pow.kicad_sch]
2025-11-18 feat: completed High power stage
    [Ducker-Charger.kicad_pcb, high_pow.kicad_sch]
2025-11-18 fix: unconnected pins, wrong connections
    [Ducker-Charger.kicad_sch, high_pow.kicad_sch]
2025-11-18 feat: begun Logic
    [Logic.kicad_sch]
2025-11-19 fix: placement
    [high_pow.kicad_sch]
2025-11-25 fix: CUBE-MX project placement and name
    [cubeMX.ioc]
2025-11-25 fix: changed cell sensing connector
    [Ducker-Charger.kicad_sch]
2025-11-25 feat: started BMS configuration
    [BMS.kicad_sch, Ducker-Charger.kicad_pcb, Ducker-Charger.kicad_sch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]
2025-11-26 feat: started CHG and DSG in BMS
    [BMS.kicad_sch]
2025-11-30 feat: implement basic BQ77915 protection circuit
    [BMS.kicad_sch]
2025-11-30 feat: added circuit diagram explanation
2025-11-30 feat: initial CubeMX configuration (Clocks, SPI1, I2C1, TIM2)
2025-11-30 feat: progressed MCU setup, completed 3V3 voltage regulator
    [Logic.kicad_sch]
2025-11-30 feat: added voltage regulator lib and datasheet
2025-11-30 fix: placement and values
    [BMS.kicad_sch, Logic.kicad_sch]
2025-11-30 feat: added debug, ntc sensing and minor fixes
    [cubeMX.ioc]
2025-12-08 feat: STPD01 setup
    [low_pow.kicad_sch]
2025-12-08 fix: minor files
    [Ducker-Charger.kicad_sch]
2025-12-13 feat: substituted IP5389 with BQ25713 + TPS25750
    [high_pow.kicad_sch]
2025-12-13 feat: added STUSB4710AQ1TR
    [low_pow.kicad_sch]
2025-12-14 feat: completed BQ25713 + TPS25750 config
    [high_pow.kicad_sch]
2025-12-14 feat: completed low power sheet
    [low_pow.kicad_sch]
2025-12-14 feat: completed BMS sheet
    [BMS.kicad_sch]
2025-12-14 feat: added pullup resistors for i2c
    [Logic.kicad_sch]
2025-12-22 feat: progressed overall schematic
    [Ducker-Charger.kicad_pcb, Ducker-Charger.kicad_sch, Logic.kicad_sch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]
2025-12-23 fix: power symbols
    [BMS.kicad_sch, Ducker-Charger.kicad_sch, Logic.kicad_sch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]
2025-12-23 fix: I2C is now a BUS, no longer a global label
    [BMS.kicad_sch, Ducker-Charger.kicad_sch, Logic.kicad_sch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]
2025-12-23 fix: replaced Schottky Diode sym
    [high_pow.kicad_sch]
2025-12-23 fix: readability of Buck-Boost power stage
    [high_pow.kicad_sch]
2025-12-26 fix: MOSFET
    [high_pow.kicad_sch]
2025-12-26 fix: Rshunt
    [high_pow.kicad_sch]
2025-12-26 feat: added I2C iso IC
    [BMS.kicad_sch]
2025-12-27 fix: short circuited D+ and D- to unlock 3A in usbA
    [low_pow.kicad_sch]
2025-12-27 fix: minor fixes
    [Ducker-Charger.kicad_sch, Logic.kicad_sch]
2025-12-27 feat: added fuse blade
    [Ducker-Charger.kicad_sch]
2025-12-27 feat: updated footprints
    [BMS.kicad_sch, Ducker-Charger.kicad_sch, Logic.kicad_sch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]
2025-12-27 feat: completed BMS section
    [Ducker-Charger.kicad_pcb]
2025-12-27 fix: changed rshunt footprint
    [BMS.kicad_sch, high_pow.kicad_sch]
2025-12-27 feat: progressed pcb
    [Ducker-Charger.kicad_pcb]
2025-12-27 fix: completed MCU config
    [cubeMX.ioc]
2025-12-27 fix: updated config based on CubeMX
    [Ducker-Charger.kicad_sch, Logic.kicad_sch, low_pow.kicad_sch]
2025-12-28 fix: added missing connections
    [Logic.kicad_sch, low_pow.kicad_sch]
2025-12-28 feat: PCB v1.0 is now ready
    [Ducker-Charger.kicad_pcb]
2025-12-28 feat: added gerber files
2025-12-28 fix: removed 90deg tracks
    [Ducker-Charger.kicad_pcb]
2025-12-28 feat: added sensing board project
    [Sensing-Board.kicad_pcb, Sensing-Board.kicad_sch]
2025-12-29 fix: downsized the numbers of load bearing VIAs
    [Ducker-Charger.kicad_pcb]
2025-12-29 fix: new BUCK-BOOST power stage
    [high_pow.kicad_sch]
2025-12-30 fix: removed old High Power section
2025-12-30 fix: remade entire ICs configuration
    [high_pow.kicad_sch]
2025-12-31 fix: MCU connections
    [high_pow.kicad_sch]
2025-12-31 fix: missing files
    [Logic.kicad_sch]
2026-06-08 feat: splitted analog line
    [Logic.kicad_sch]
2026-06-11 feat: Initial commit of charge management system files
2026-06-11 fix: switched to C
    [charge.c, charge.h]
2026-06-11 feat: Implemented sensor reading function via ADC
2026-06-12 Updated PCB docs, added BQ34Z100-R2 Technical Reference Manual
2026-06-12 feat: Added FuelGauge sensor reading and GPIO R/W for interrupts and ports enabling
2026-06-12 fix: configuration & parity errors
    [cubeMX.ioc]
2026-06-13 fix: fixed race conditions by switching I2C fuel gauge sensors readings from non-blocking to blocking
    [charge.c, charge.h]
2026-06-13 feat: add UI module headers
    Add include directories for app, display and ui modules.
    Headers define the full architecture: telemetry polling (BQ34Z100 + BQ25713), rotary encoder (TIM3 encoder mode), ILI9341 SPI display driver, GFX primitives, widgets, screens and UI state machine.
    No source files yet - headers only, compile-tested in STM32CubeIDE.
2026-06-14 feat: Added fetch of PD contract and interrupt handling for primary USB-C connection/disconnection
2026-06-16 feat: add ILI9341 display driver and GFX primitives
    ili9341.c: SPI low-level driver for ILI9341/ST7789 TFT display.
    gfx.c: geometry and text primitives built on top of the display driver.
2026-06-16 fixed comments and addes features (add telemetry polling and rotary encoder driver)
    [ili9341.c, ili9341.h]
2026-06-17 fix: fixed adc sensor reading and added get functions for easy data fetch
    [charge.c, charge.h]
2026-06-18 fix: code cleanup + fixed temperature conversion for NTC thermistors
    [charge.c, charge.h]
2026-06-18 fix: moved charge-management doc file into docs/
2026-06-20 feat: added INA sensors and alerts reading, implemented INA get function and added guard for non supported PDO contracts for the primary USB-C
2026-06-21 feat: added charge management documentation
2026-06-22 feat: remade the PCB & minor schematic fixes
    [BMS.kicad_sch, Ducker-Charger.kicad_pcb, Logic.kicad_sch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]
2026-06-24 feat: completed Sensing board
    [Sensing-Board.kicad_pcb, Sensing-Board.kicad_sch]
2026-06-24 feat: final version before prod
    [Ducker-Charger.kicad_pcb, high_pow.kicad_sch, low_pow.kicad_sch]
2026-06-26 feat: added other ALERT_STATUS register's bits handling and modified lower-bound voltage for STPD01 setup + some fixes
    [charge.c, charge.h]
2026-06-28 fix: updated pin names & added missing pins
    [cubeMX.ioc]
2026-06-28 fix: updated cubeMX generated code
    [cubeMX.ioc, main.c, main.h]
2026-07-03 feat: production BOM
    [BMS.kicad_sch, Logic.kicad_sch, high_pow.kicad_sch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]
2026-07-04 feat: wired boot initialization into main
2026-07-05 feat: C2_RDY interrupt handler for STPD01 power state changes
2026-07-05 feat: display driver ILI9341/ST7789, GFX layer, logo
2026-07-05 feat: encoder EC11, TIM3 TI12 mode, /2 divisor
2026-07-05 feat: telemetry, BQ34Z100 on hi2c1 (I2C_LP), BQ25713 stubbed
2026-07-05 feat: UI layer — widgets, screens, state machine
2026-07-05 build: add display/UI/encoder/telemetry sources to Makefile
2026-07-05 feat: wire display, encoder, telemetry and UI into main()
2026-07-05 feat: add interface-tester — native UI simulator linked to firmware sources
2026-07-05 fix: Encoder button moved from polling to EXTI0
2026-07-06 fix: removed redundant comments, #5
    [fsm.c]
2026-07-06 fix: missed CS in onRun, #6
    [fsm.c]
2026-07-06 fix: header include, #7
    [charge.c]
2026-07-07 fix: C2 using CYPD3175, #8
    [charge.c, charge.h, defines.h]
2026-07-07 chore: fixes + docs
    [fsm.c]
2026-07-09 feat: Designed the first enclosure prototype for the power bank
    [Power_bank_enclosure(prototype_1).f3d, Power_bank_enclosure(prototype_1).step, Power_bank_enclosure(prototype_1).stl]
2026-07-10 feat: detached C1 in SAFETY_LOCK, C2 ceiling, condition on wake up, fix on UI
    [charge.c, charge.h, defines.h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]
2026-07-10 feat: Designed the second version of the power bank enclosure prototype
    [Enclosure_(prototype_2).stl, Power_bank_enclosure(prototype_1).f3d, Power_bank_enclosure(prototype_1).step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]
2026-07-12 fix: Fixed some tolerances
    [Enclosure_(prototype_3).stl, Power_bank_enclosure_(prototype_2).f3d, Power_bank_enclosure_(prototype_3).f3d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]
2026-07-12 fix: Increased PCB guide's tolerance
    [Enclosure_(prototype_3).stl, Power_bank_enclosure_(prototype_3).f3d, Power_bank_enclosure_(prototype_3).step]
2026-07-12 feat: frame recorder
2026-07-12 feat: on-device gauge calibration wizard
2026-07-12 feat(emulator): live calibration model for the BQ34Z100
2026-07-12 docs: gauge calibration wizard + emulator recorder

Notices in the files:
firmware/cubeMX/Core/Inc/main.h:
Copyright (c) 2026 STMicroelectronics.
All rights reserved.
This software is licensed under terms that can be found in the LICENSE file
